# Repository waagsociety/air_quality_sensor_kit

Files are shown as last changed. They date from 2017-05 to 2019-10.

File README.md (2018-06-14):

# Air quality sensor kit
This repo contains documentation, source files and code for the following air quality sensor kits:

- Bora kit
- Bora Lora kit
- rIoT
- Responsive bird

### Bora kit
Air Quality Sensor for the Amsterdam Smart Citizens Lab, measures NO2, dust, temperature and humidity. Developed for a pilot in 2016 to measure air quality around the Valkenburgerstraat and Weesperstraat, under the name [Urban AirQ](http://waag.org/en/project/urban-airq). Citizens actively participated in the measuring process.

### Bora lora kit
The Bora kit was further developed during the [Smart Kids Lab](https://waag.org/en/blog/smart-citizen-kit-measuring-children-school) pilot to improve some criticalities with [LoraWAN](https://www.lora-alliance.org/What-IsLoRa/Technology):
- unstable and weak connectivity of the wifi module
- high power consumption,
- lack of real time data visualization.

### rIot
TBA

##### Credits
Partners: KNMI, University of Wageningen, GGD Amsterdam, ECN and the LongFonds. Waag Society earlier conducted a pilot with the Smart Citizen Kit in Amsterdam to measure air quality.

Partly financed by the Amsterdam Institute for Advanced Metropolitan Solutions (AMS). The project is also part of the European financed program Making Sense. This project has received funding from the European Union’s Horizon 2020 research and innovation programme under grant agreement no. 688620.

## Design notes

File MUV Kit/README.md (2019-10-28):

# Air quality sensor kit for MUV

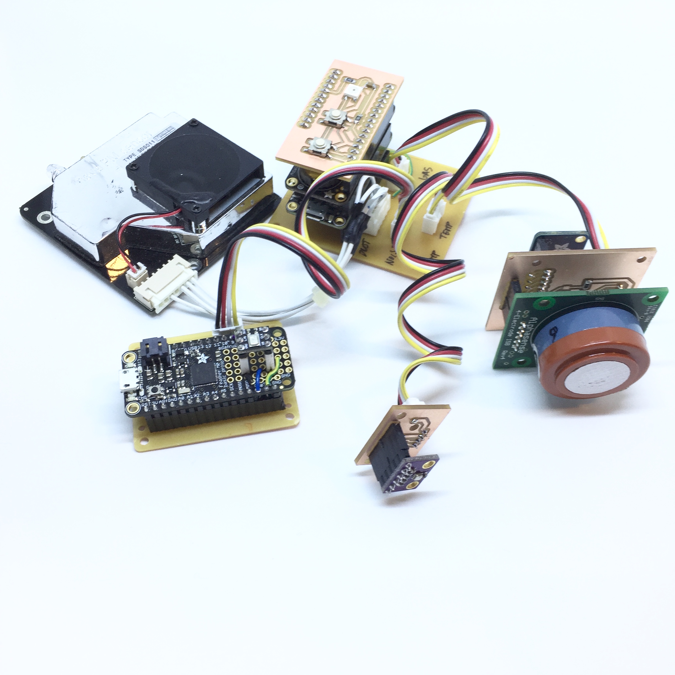
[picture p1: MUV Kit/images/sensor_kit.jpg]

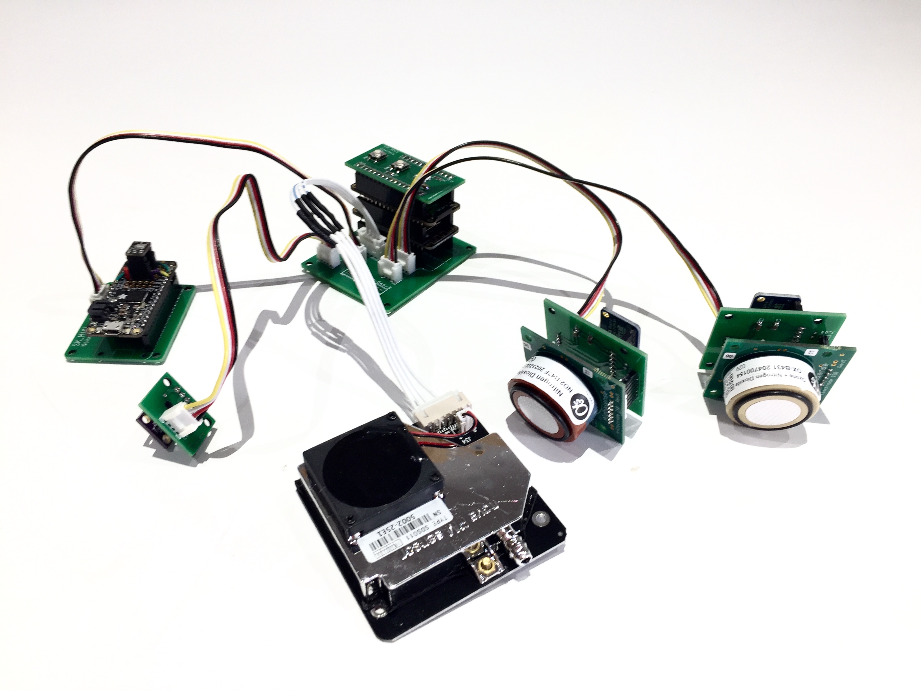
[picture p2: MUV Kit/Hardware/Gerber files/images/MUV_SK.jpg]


This repository is about the Sensors Kit developed for the project [MUV](https://www.muv2020.eu/) and contains the following parts:
- this page: you will find on this page the instructions on how it works.
- [Sensors](https://github.com/waagsociety/air_quality_sensor_kit/tree/master/MUV%20Kit/Sensors) folder: it contains the list of sensors that can be connected to the Kit.
- [Hardware](https://github.com/waagsociety/air_quality_sensor_kit/tree/master/MUV%20Kit/Hardware) folder: it contains digital files, original design files, layout view, instruction on how to produce the pcbs in a fablab, gerber files and BOM.
- [Firmware](https://github.com/waagsociety/air_quality_sensor_kit/tree/master/MUV%20Kit/Firmware) folder: it contains the sketches used in the Kit.
- [Case](https://github.com/waagsociety/air_quality_sensor_kit/tree/master/MUV%20Kit/Case) folder: it contains the instructions for the case.

## Intro
The MUV Sensors kit is a device developed to measure the following environmental quantities:
* dust (PM10 and PM2.5)
* temperature/humidity/pressure sensor
* nitrogen dioxide and ozone.

The kit has a WiFi module that collects the data from the sensors and send them to the MUV MQTT-server. If the WiFi is missing the kit saves the data on an SD-card.

NOTE: when you power on the kit, it must be able to connect to a WiFi otherwise it will not start the measurements.

Once the Kit is powered on and connected to the WiFi it will run automatically.

### Connect the Sensor Kit to the local WiFi
Power on the SK (Sensor Kit), plugging the USB cable. 
The kit will try to connect to the WiFi, during which the Led on the interface board will flash red. 
If no Wifi configuration is present, the kit wil enter configuration mode, indicated by a steady blue Led.

When in configuration mode, it creates a network named MUV_air.
At this point you need a smartphone/tablet or computer, join the network MUV_air.

If the Led keeps flashing red, you can enter configuration mode manually. Press and hold the 
SW_CONFIG button while pressing the SW_RST button. The kit should reset and start in
configuration mode with the blue Led on. Once the blue Led is on, you can release the SW_CONFIG
button.

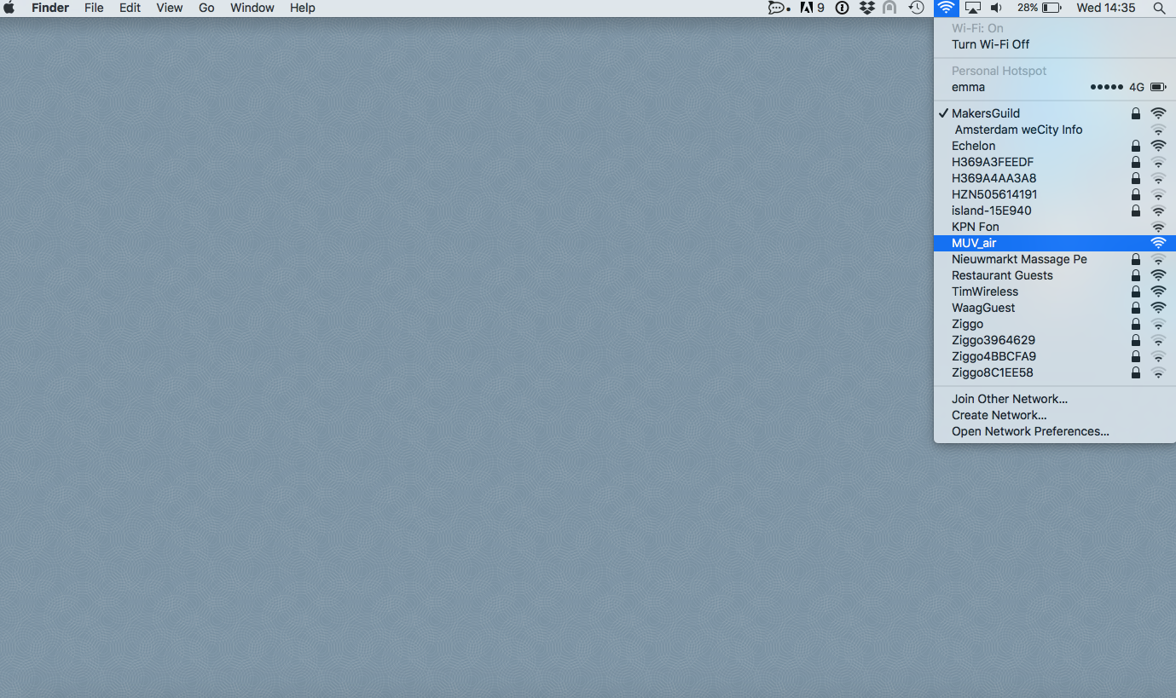
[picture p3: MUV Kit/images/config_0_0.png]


Automatically on the device you are using (smartphone/tablet/computer) the configuration window will pop-up.

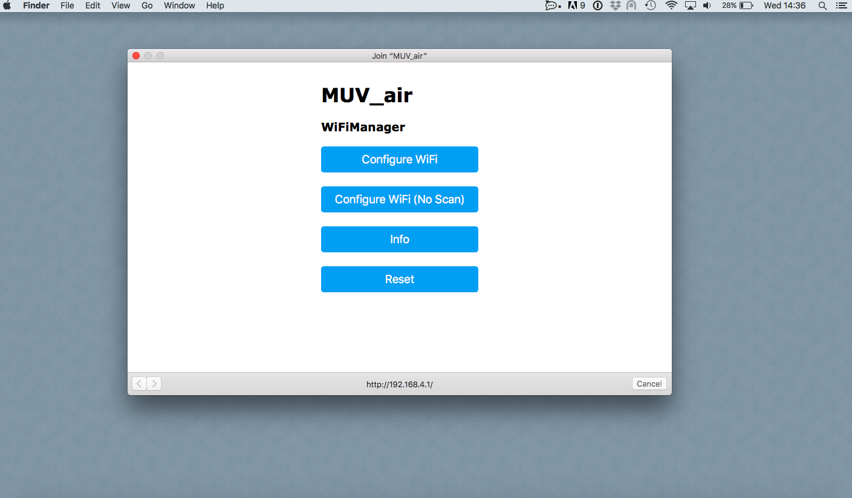
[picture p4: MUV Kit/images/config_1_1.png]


If the window doesn't appear, open a browser and go to the address: http://192.168.4.1/.

Clicking on Info, you can see the information related to the kit and find the kit ID that in the window is called Chip ID.
Clicking on Configure WiFi, you are in the right place to connect the kit to you local WiFi.

Select the WiFi and type the password.
In the tag "Insert address", write the location of the kit.
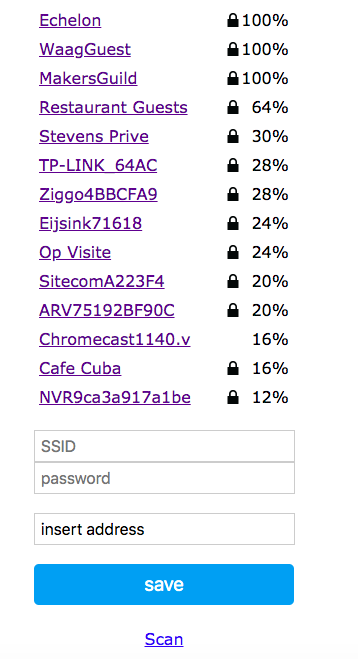
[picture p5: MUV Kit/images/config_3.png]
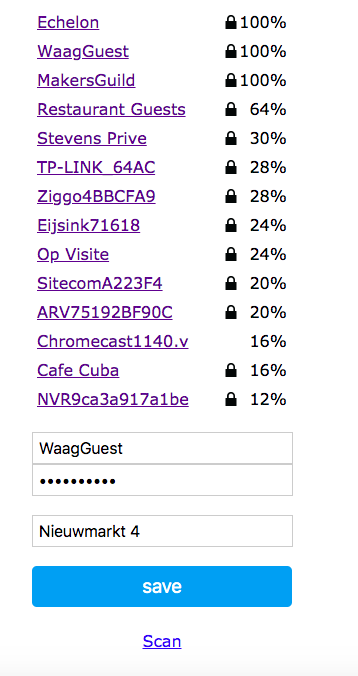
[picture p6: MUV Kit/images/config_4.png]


Click save and the kit will try to connect to the WiFi. The Led should flash red briefly, then turn green for a short time, then flash
magenta briefly and finally going off. The kit is now connected and starts the measurements.

** NOTE **
In case you want to change the location, you can enter configuration mode using the Config switch on the interface board: keep pushed the Config switch and reset the kit (press once the reset switch). Hold the Config switch until the Config Led turns blue.

### Explanation of the Led colors
- When you power the kit on, the Led blinks red while connecting to the WiFi. If it can't connect, it will continue to flash red.
- You can enter configuration mode as described above. When in configuration mode the Led is a steady blue.
- When the WiFi is connected succesfully, the Led is on green, while getting the current time from the NTP server and checking for a firmware update.
- Once the time is synchronised, the kit will attempt to connect to the MQTT server. During this the Led flashes magenta. If it can't connect
to the MQTT server, it will continue to flash magenta.
- Once the MQTT connection is made, the Led will go off and the measurements begin.
- Every time the data are pushed to the cloud, the Led blinks green if the uplink is successful. If the payload can't reach the server, the Led turns on/orange and the data are saved to the SD-card. If the kit is disconnected from the WiFi and can't save the data on the sd-card, the Led stays on/red.

### MUV

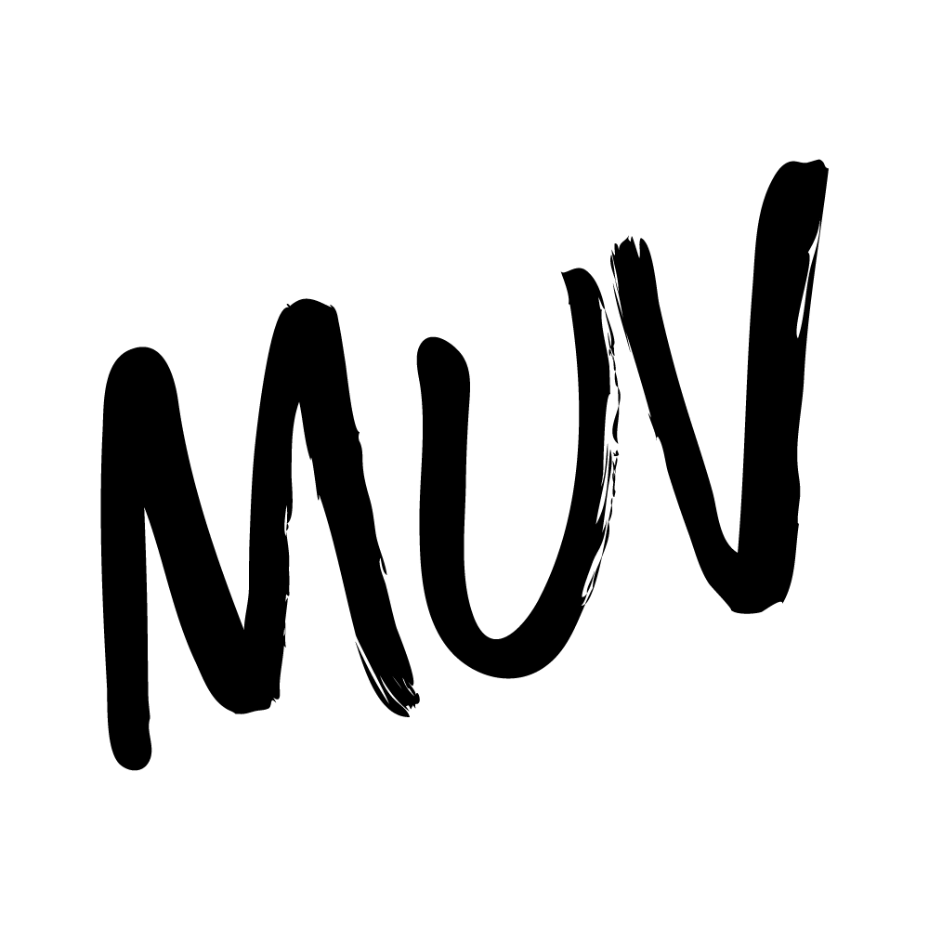
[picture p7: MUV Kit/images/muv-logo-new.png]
 

[*MUV* – Mobility Urban Values –](https://www.muv2020.eu) levers behavioural change in local communities using an innovative approach to improve urban mobility: changing citizens’ habits through a game that mixes digital and physical experiences.

Rather than focus on costly and rapidly ageing urban infrastructures, MUV promotes a shift towards more sustainable and healthy mobility choices by engaging in a positive way local communities, local businesses, policymakers and Open Data enthusiasts.

MUV solutions will be open, co-created with a strong learning community of users and stakeholders, and piloted in a set of diverse urban neighbourhoods spread across Europe: Amsterdam (NL), Barcelona (ES), Fundao (PT), Ghent (BE), Helsinki (FI), Palermo (IT).

Mobility and environmental data gathered via the mobile app and the monitoring stations will allow policymakers to enhance planning processes and civic hackers to build new services able to improve cities’ quality of life in a more effective way.



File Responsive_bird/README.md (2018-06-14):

# NO2_sensor
This bird senses NO2 and according on the percentage NO2 it rotates around its axis. 

The housing of the NO2 sensor has the shape of a bird. A DC motor attached to the sensor enables the object to rotate. This rotation gives minimalistic feedback on the sensor's data. When the quality of the air is good, the bird is in it's normal position. But when the air quality deteriorates, the bird turns half a circle and lies down on its back, as if it’s dead. In this way, by adding a small mechanism to the sensor, passers-by can immediately retrieve feedback from the sensor.

prototype bird with hands
no2 kills birds

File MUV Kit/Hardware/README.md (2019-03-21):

If you are planning to produce the boards in the fablab you are in the right place. On this page you find instructions that will guide you during the process.
If you want to save time (and budget) you can download and use the gerber files of the customised boards from [folder](https://github.com/waagsociety/air_quality_sensor_kit/tree/master/MUV%20Kit/Hardware/Gerber%20files).

## Fab pcbs

The Fab boards are made using the small milling machine Roland Modela MDX-20, each pcbs requires at least two jobs: mill the trace and cut/drill the boards, in the folder digital files you find the png machinable files. When the pcb is double-side (the components and/or traces are on both side), the jobs are four: [double side milling](https://github.com/waagsociety/air_quality_sensor_kit/tree/master/MUV%20Kit/Hardware/Double%20side%20milling).

Tools used:
- one side and double side copper plate, FR1
- to mill the traces: endmill, 1/64inch diameter
- to cut and drill: endmill, 1/32inch diameter

In Fablab Amsterdam the software to generate the rml file and send it to the machine is Fabmodules. It is highly recommended to use the last version of Fabmodules, aka mods http://mods.cba.mit.edu/; previous versions of fabmodules, still work but double check the output of the software before to send the job to the machine, in some cases the path is not well calculated.

In the image below you find the setting to envrage the traces and to drill holes/cut the board.
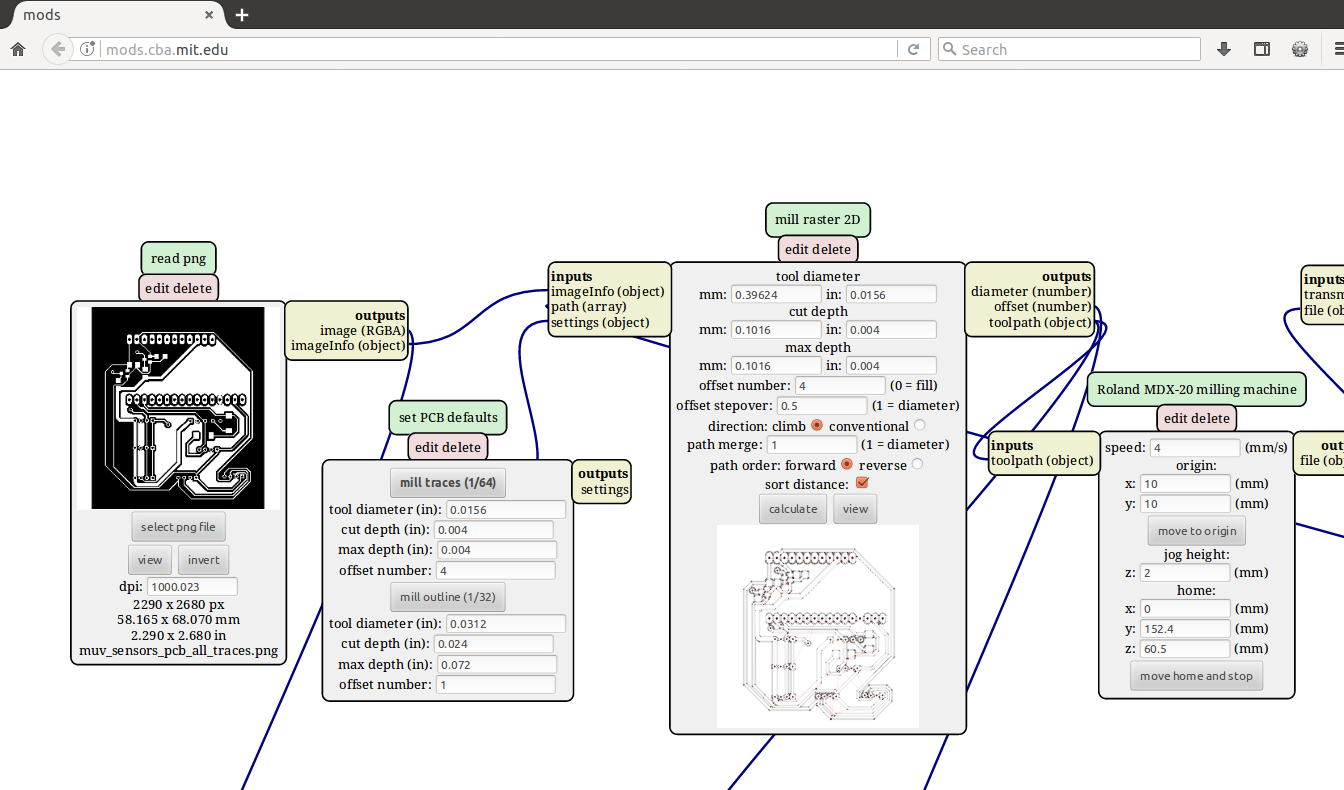
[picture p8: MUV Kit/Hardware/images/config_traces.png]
<br>
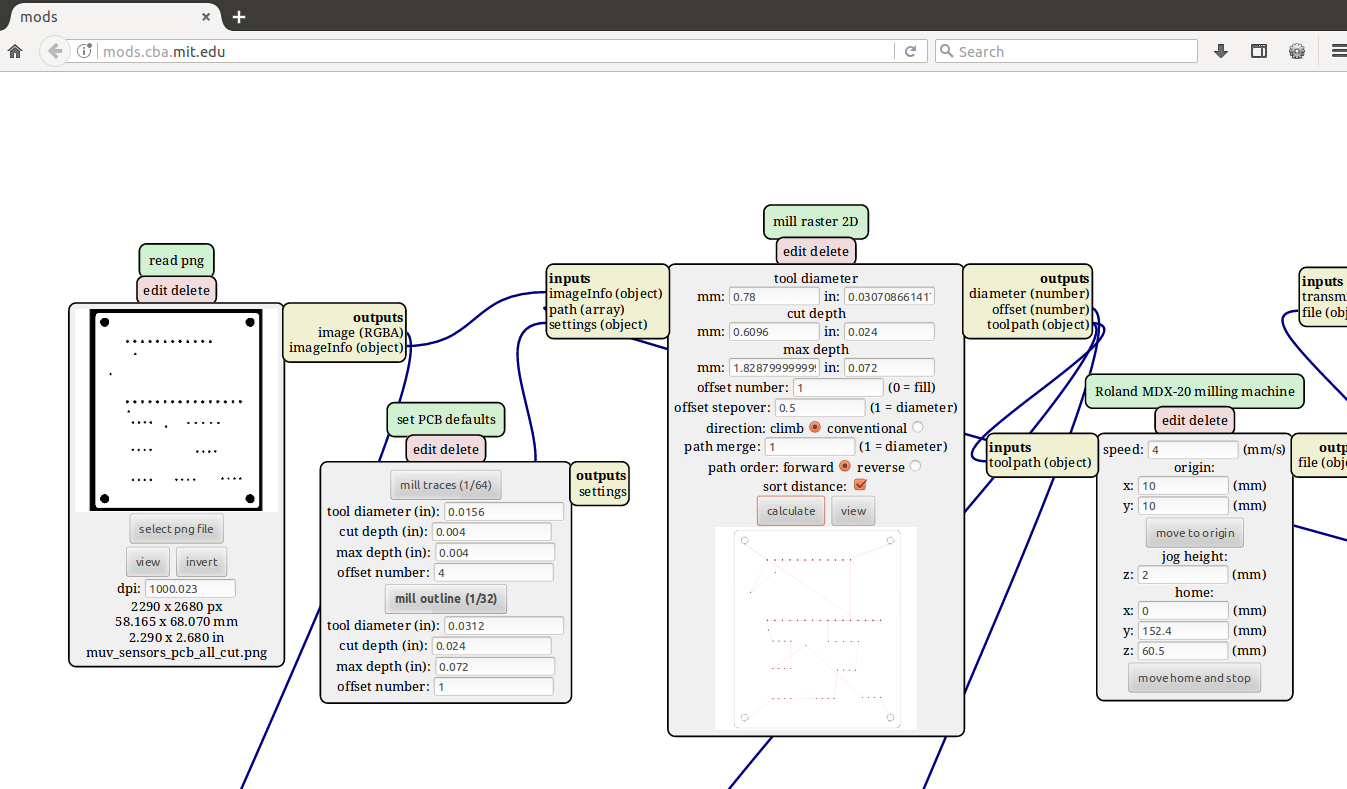
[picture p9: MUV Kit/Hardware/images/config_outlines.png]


Note: when you mill the outlines, you will need to trick the fabmodules!! Some holes are two smalls to be identified with a diameter tool of 1/64inch (0.79248mm) so you can set the diameter tool to 0.78mm and all the holes will be milled; yes, you lose some copper on the pad but it is still enough to solder vias and components.

#### Sensors pcb
| top view  | bottom view |
| --- | --- |
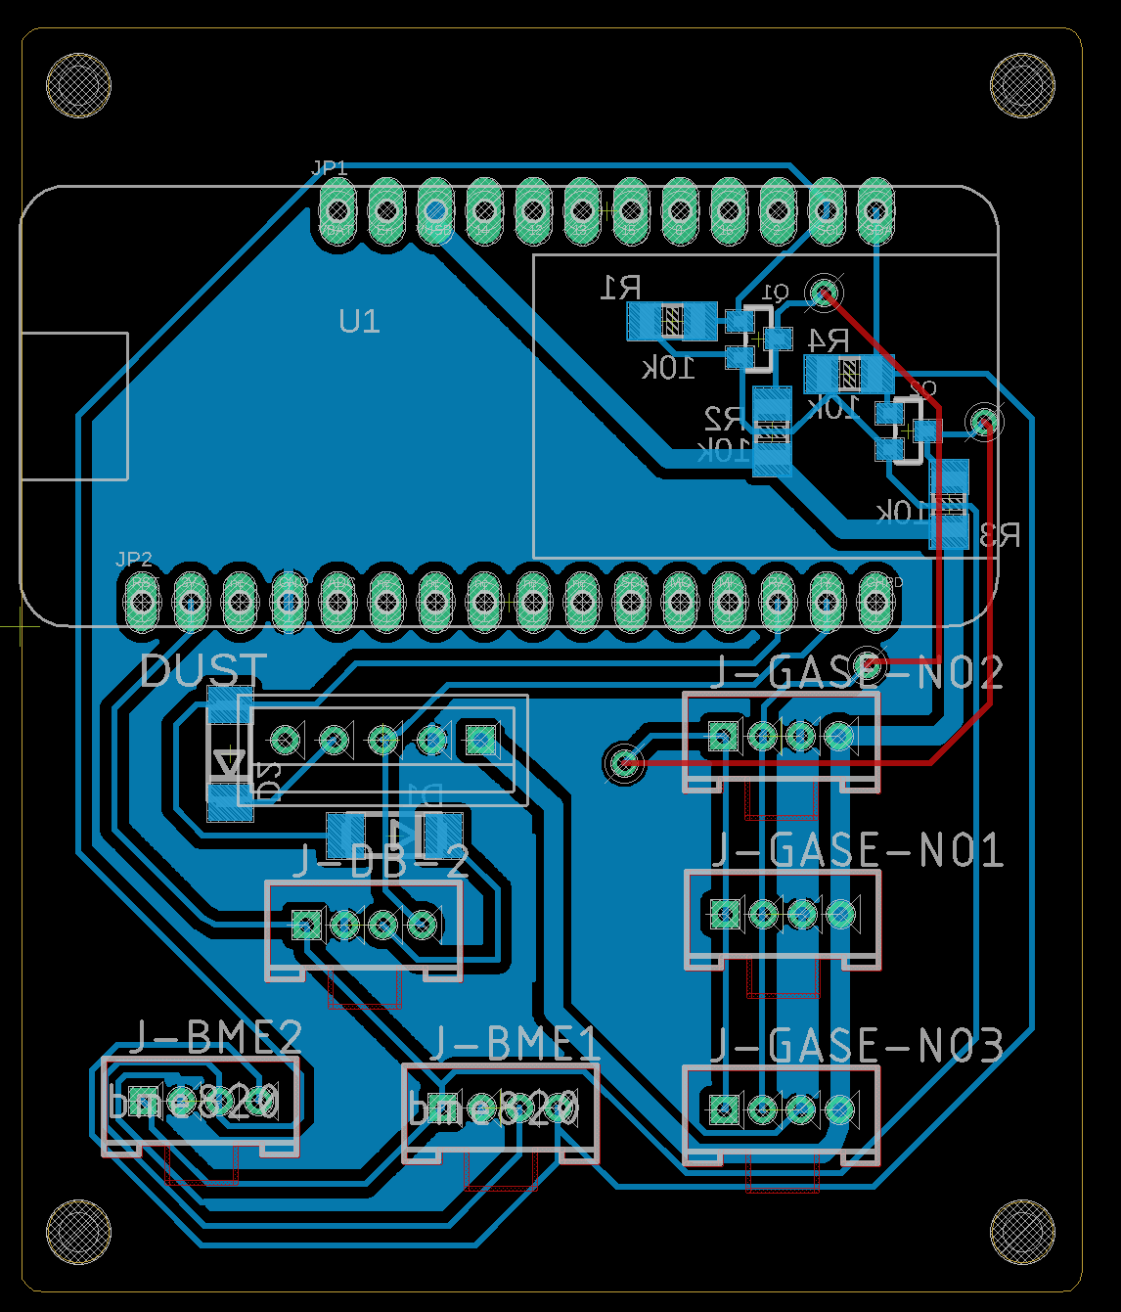
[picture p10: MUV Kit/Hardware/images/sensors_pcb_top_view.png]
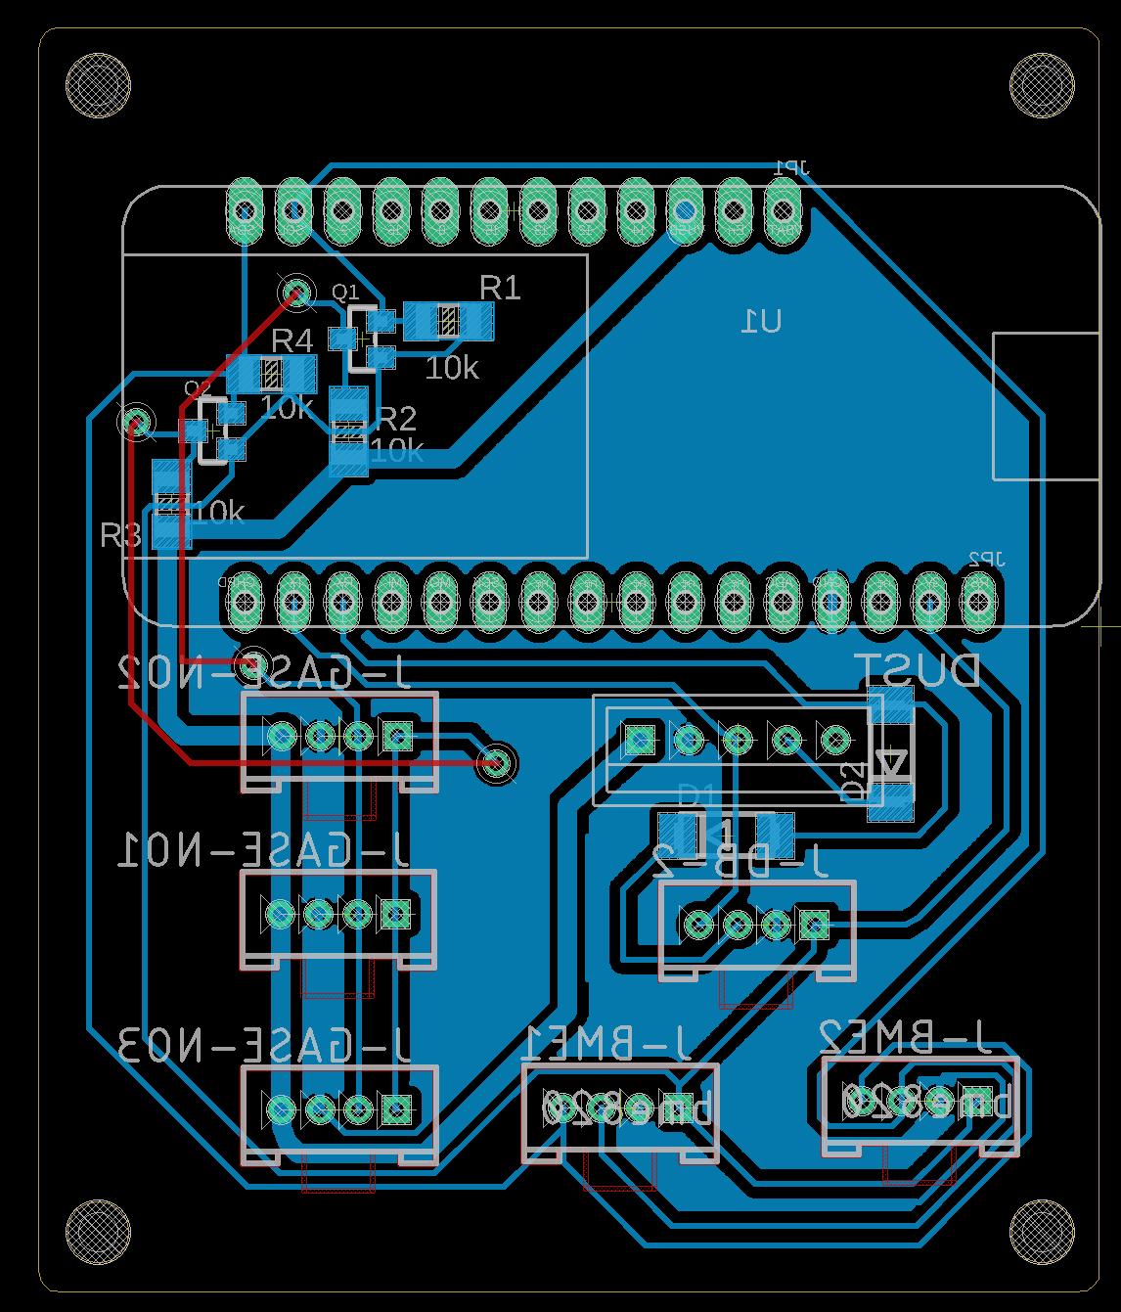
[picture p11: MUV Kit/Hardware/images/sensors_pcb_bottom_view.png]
| |  |
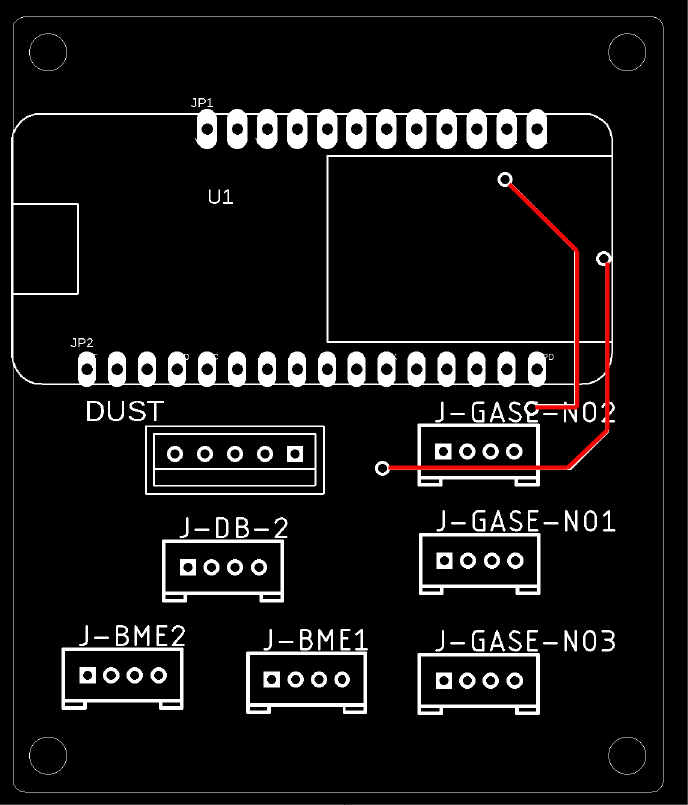
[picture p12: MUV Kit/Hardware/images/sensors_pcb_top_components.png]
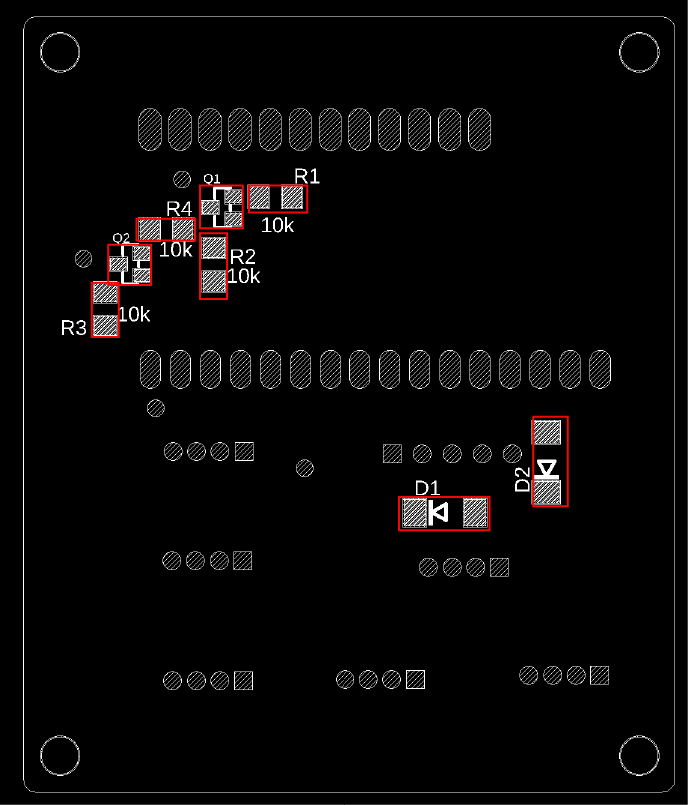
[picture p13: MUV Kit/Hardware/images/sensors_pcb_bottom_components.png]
| Components placed on the top layer  <br> but soldered on the bottom! <br>  <br> JP1: female THT 1x12 pin header, 2.54pitch <br> JP2: female THT 1x16 pin header 2.54pitch <br> J-GAS, J-DB. J-BME : Grove - Universal 4 Pin connector <br> 05-JST-B5B: Connector Wire-To-Board, B5B-XH-A (LF)(SN) <br> red traces: jumper wires between vias| Components placed on the bottom layer <br> and soldered on the bottom side <br>  <br> Q1/Q2 : BSS138 mosfet, also the NDS355AN from the fab inventory is ok. <br> R1/R2/R3/R4 : 10 Kohm <br> D1/D2 : diodes <br><br><br><br>|
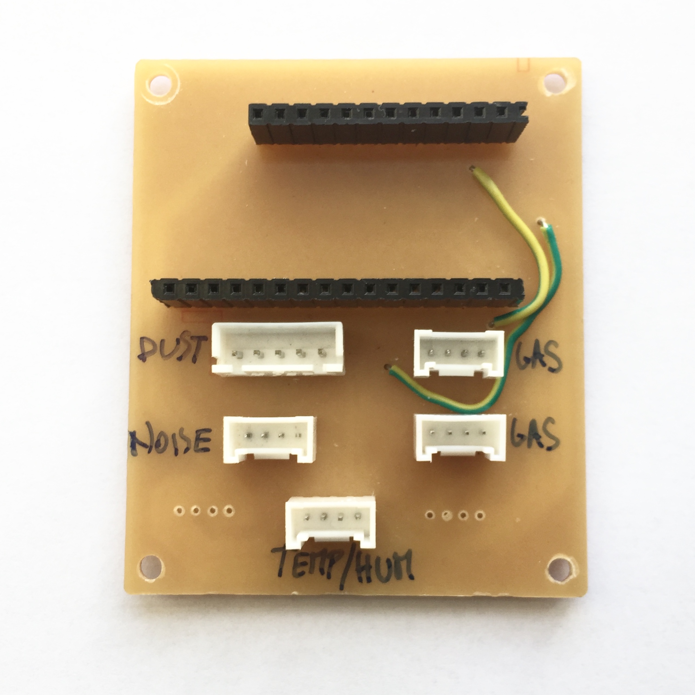
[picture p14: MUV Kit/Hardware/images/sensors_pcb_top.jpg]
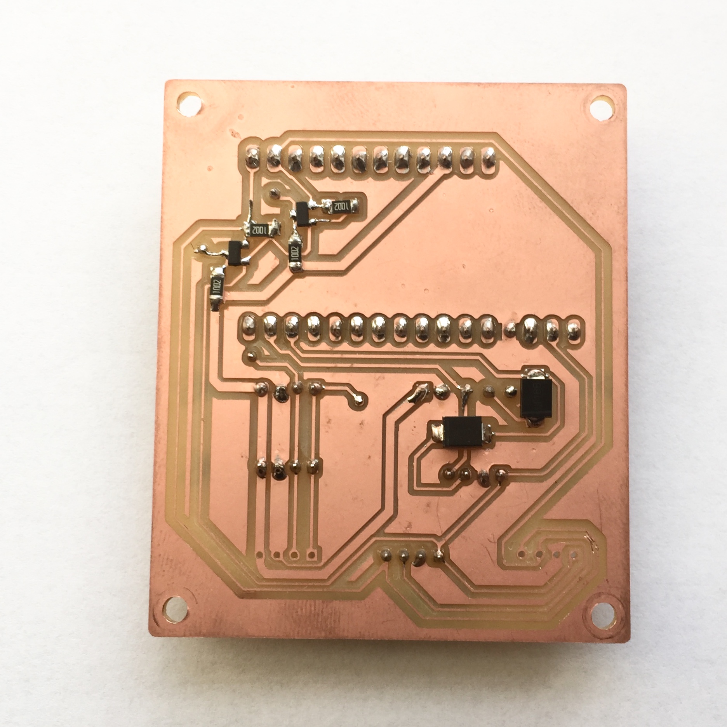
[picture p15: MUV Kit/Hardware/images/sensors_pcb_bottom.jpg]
|   | |

On the sensors pcb, it is not necessary to use all the connectors.
Depending on the sensors you want you use you can solder the required sockets. The J-GAS-NO1 and J-GAS-NO2 are dedicated to the Alphasense gas input devices. In this repo we are using only one sensor, the NO2 detector and it is connected to J-GAS-NO1.

#### Interface pcb
| top view  | bottom view |
| --- | --- |
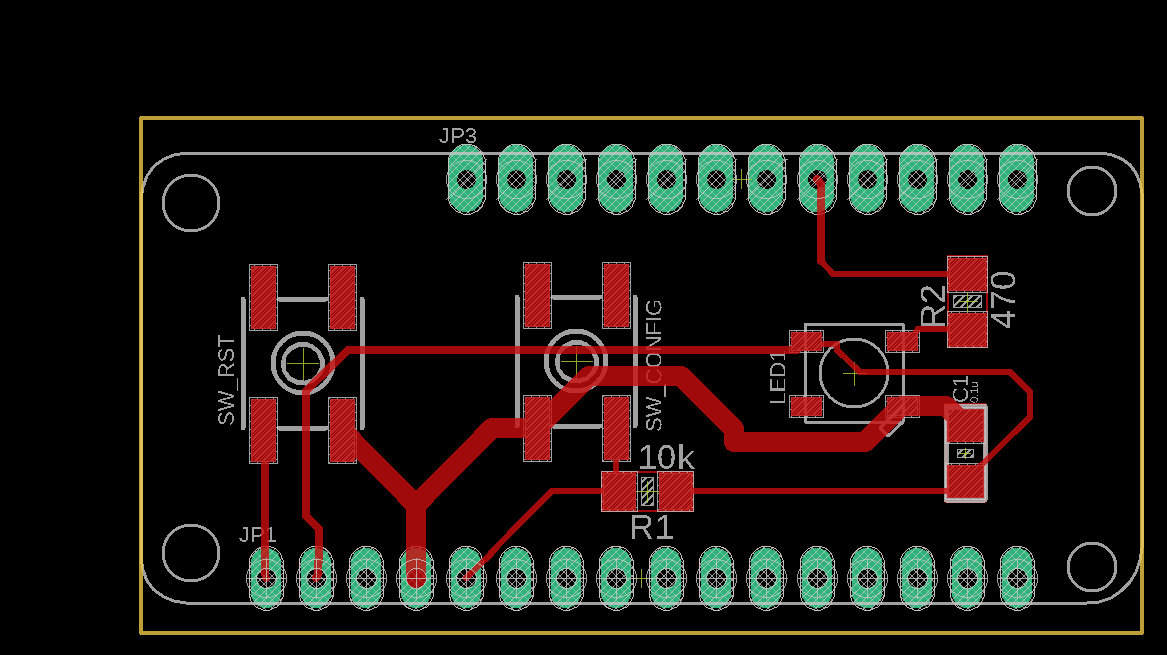
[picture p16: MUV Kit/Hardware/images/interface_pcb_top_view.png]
|  | |
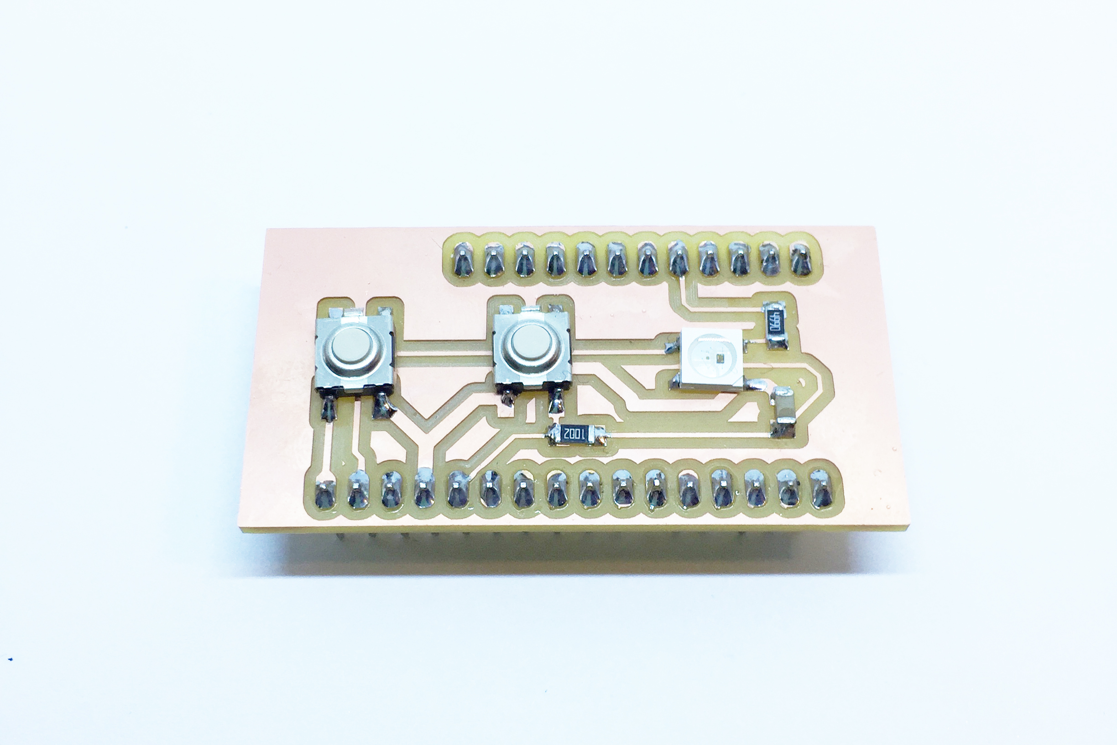
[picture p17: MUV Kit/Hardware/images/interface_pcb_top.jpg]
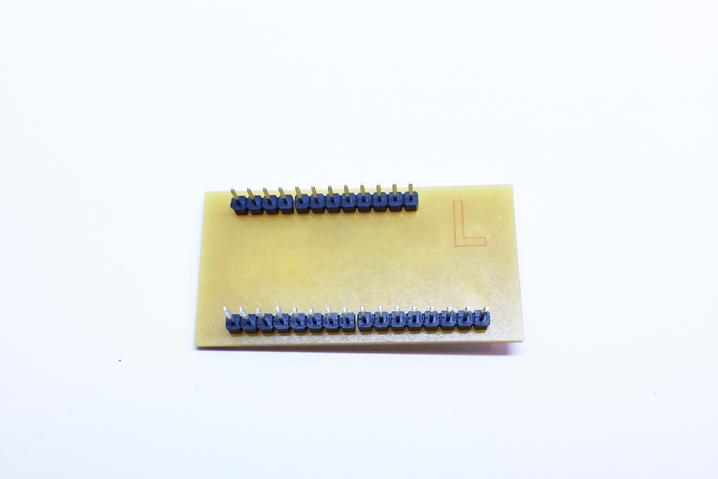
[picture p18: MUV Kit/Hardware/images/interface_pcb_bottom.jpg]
|Components placed on the top layer <br>   <br> SW_RST, SW_CONFIG: push button, smd, 6mm <br> LED1: WS2812B smd <br> R1: 10K res, smd, 1206 <br> R2: 470 ohm res, smd, 1206 <br> C1: 0.1uF cap, smd, 1206| Components placed on the bottom layer <br>  <br> JP3: female THT 1x12 pin header, 2.54pitch <br> JP1: female THT 1x16 pin header 2.54pitch <br><br><br><br>|

#### Temp/Hum pcb
| top view  | bottom view |
| --- | --- |
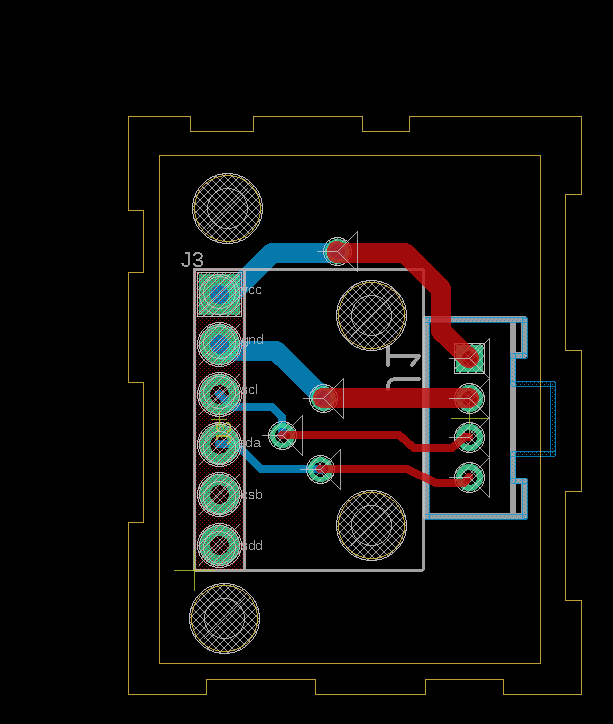
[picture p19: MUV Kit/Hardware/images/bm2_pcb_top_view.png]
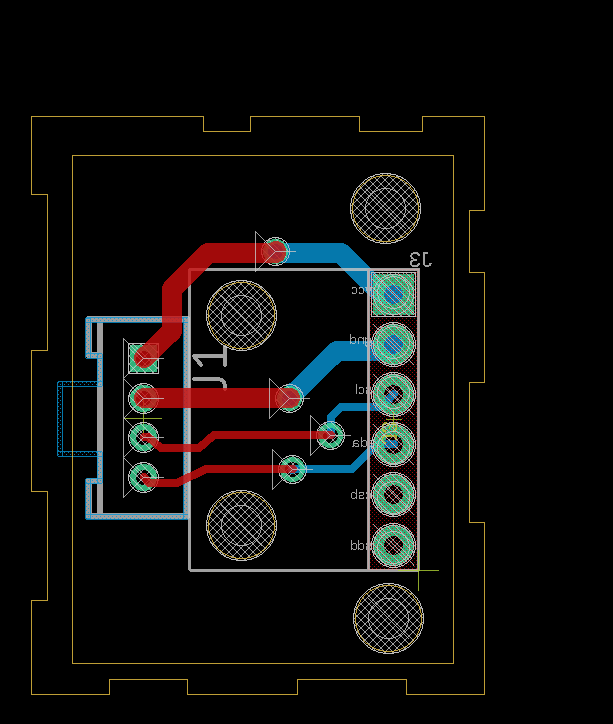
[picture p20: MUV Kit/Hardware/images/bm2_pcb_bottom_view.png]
|   | |
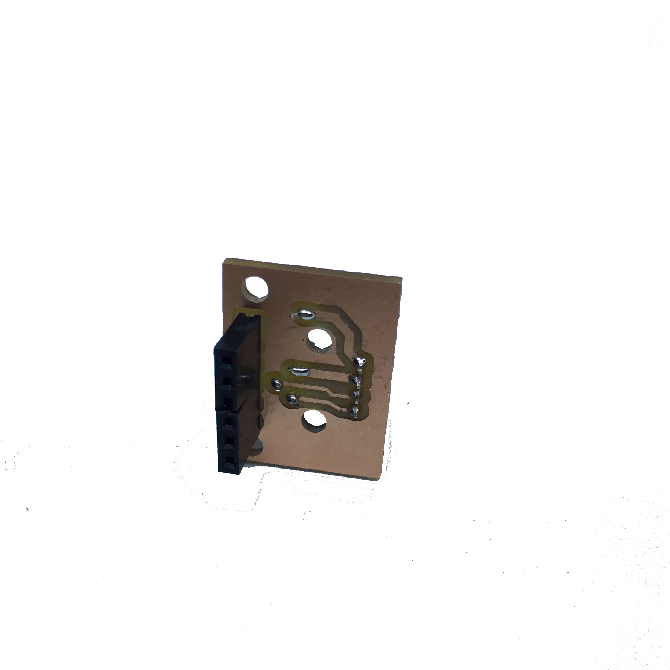
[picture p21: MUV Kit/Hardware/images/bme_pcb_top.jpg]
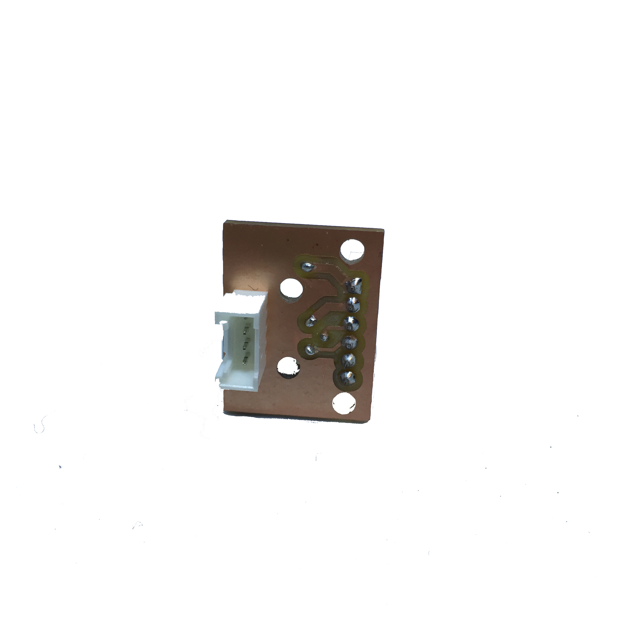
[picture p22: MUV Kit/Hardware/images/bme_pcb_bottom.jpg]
| Components placed on the top layer <br>   <br> J3: female THT 1x6 pin header, 2.54pitch| Components placed on the bottom layer <br>  <br> J1: Grove - Universal 4 Pin connector|

The temp/hum pcb is a 2 layers board, the vias can be filled in with solid core wire (diameter < 0.8 mm). More information about the production of a double side pcb are in the [Double side milling](https://github.com/waagsociety/air_quality_sensor_kit/tree/master/MUV%20Kit/Hardware/Double%20side%20milling) section.

#### Gas pcb
| top view  | bottom view |
| --- | --- |
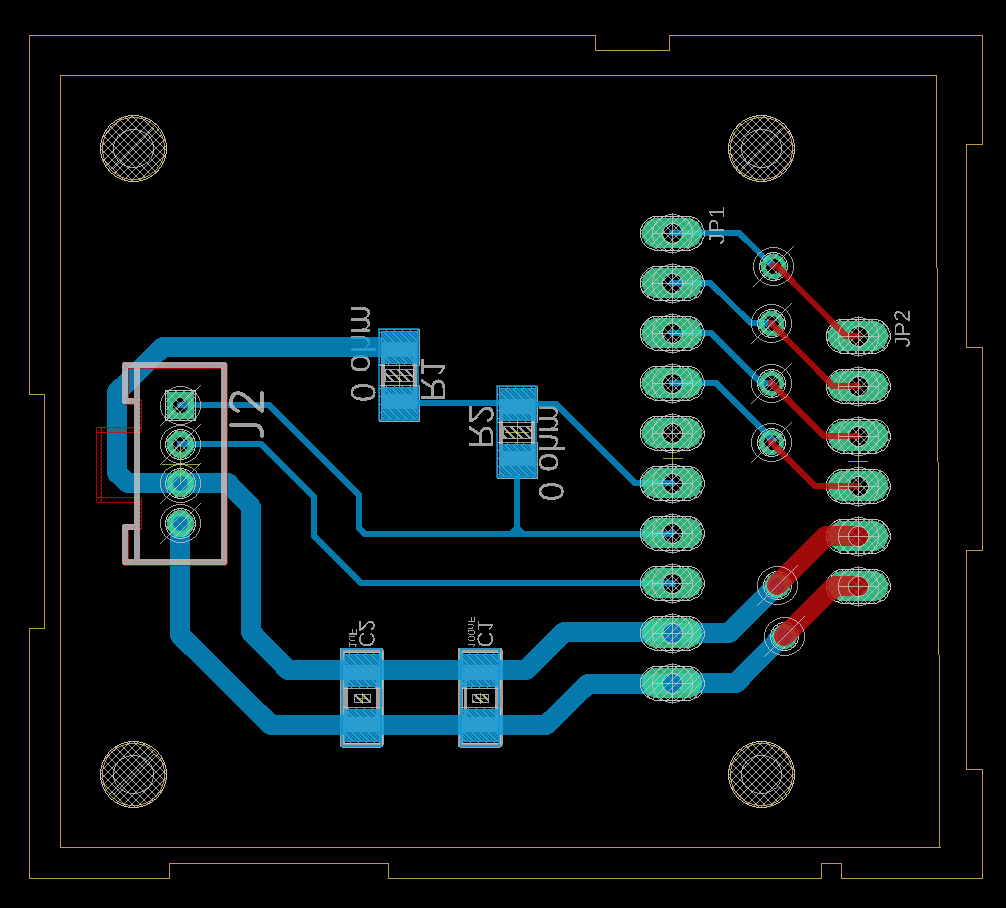
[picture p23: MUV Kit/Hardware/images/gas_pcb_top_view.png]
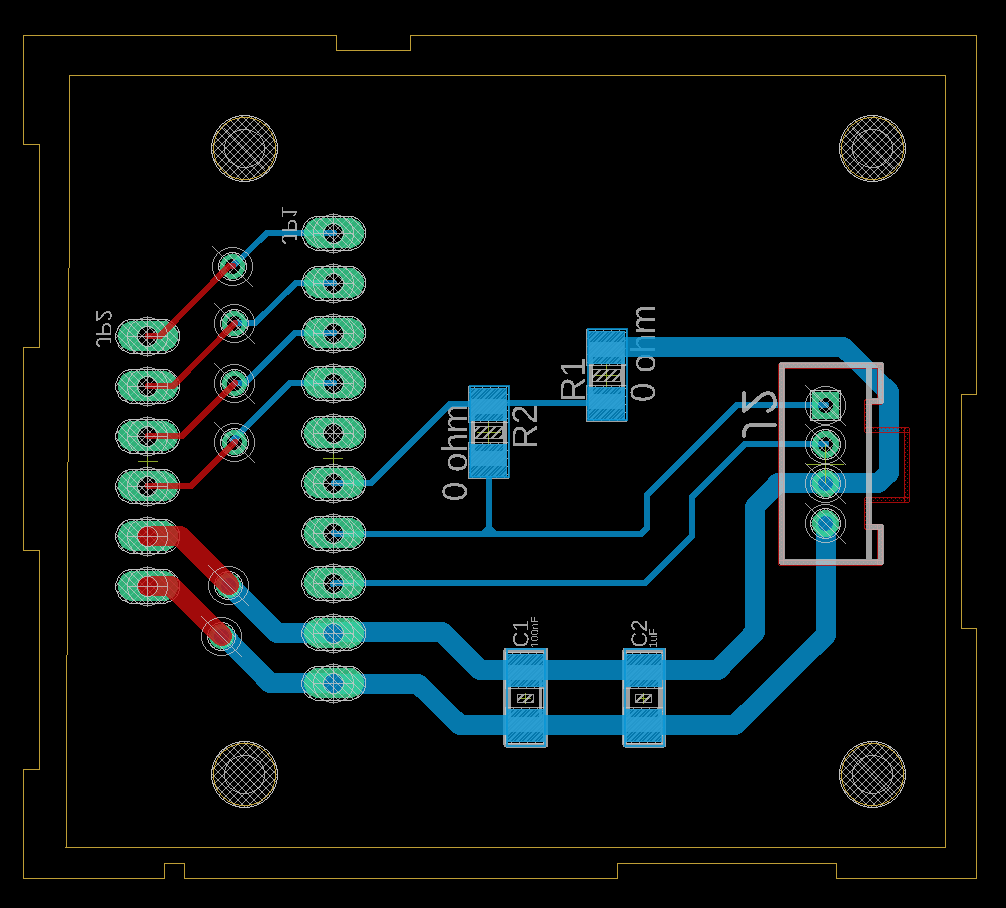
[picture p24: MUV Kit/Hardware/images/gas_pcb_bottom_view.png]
|   | |
| Components placed on the top layer <br>   <br> J2: Grove - Universal 4 Pin connector <br> JP1: female THT 1x10 pin header, 2.54pitch <br><br>| Components placed on the bottom layer <br>  <br> R1 or R2: 0 ohm resistor, smd, 1206 <br> C1: 100nF capacitor, smd, 1206 <br> C2: 1uF capacitor, smd, 1206 |

Note: this board can be used for both NO2 and O3 sensor but it is necessary to solder the zero ohm resistor in the different places depending on the gas. For the NO2 sensor the zero ohm resistor must be placed on R1, for the O3 sensor the zero ohm resistor must be placed on R2.

#### Noise pcb
| top view  | bottom view |
| --- | --- |
|   | |
| Components placed on the top layer <br>  <br> J1: Grove - Universal 4 Pin connector <br> OTS1_short: female THT 1x12 pin header, 2.54pitch <br> OTS1_long: female THT 1x16 pin header, 2.54pitch | There are no components placed on the bottom layer <br>  <br><br><br><br>|

## Off-the-shelf pcbs

#### Adafruit Feather esp8266
The [Adafruit Feather HUZZAH ESP8266](https://learn.adafruit.com/adafruit-feather-huzzah-esp8266?view=all) is an 'all-in-one' ESP8226 WiFi development board. The module can be supplied through USB cable with the following specifications:
* Measures 2.0" x 0.9" x 0.28" (51mm x 23mm x 8mm) without headers soldered in
* Light as a (large?) feather - 6 grams
* ESP8266 @ 80MHz or 160 Mhz with 3.3V logic/power
* 4MB of FLASH (32 Mbit)
* 3.3V regulator with 500mA peak current output
* CP2104 USB-Serial converter onboard with 921600 max baudrate for uploading
* Auto-reset support for getting into bootload mode before firmware upload
* 9 GPIO pins - can also be used as I2C and SPI
* 1 x analog inputs 1.0V max
* Pin #0 red LED for general purpose blinking. Pin #2 blue LED for bootloading debug & general purpose blinking
* Power/enable pin
* 4 mounting holes
* Reset button<br>

In this application the feather esp8266 is responsible to collect the measurements of the sensors and send them, via WiFi, to the dedicated server.
When the Wifi network is not available it can save the data on a SD-card, embedded on a different pcb, see section below.

The feather esp8266 requires female stacking headers so it can be plugged on the sensors pcb and it can host, on top, the RTC/SD-card pcb. The headers must be bought separately and they must be solder on the feather esp8266 board.



#### Adafruit Feather RTC and SD-card
The [Adalogger FeatherWing - RTC + SD](https://learn.adafruit.com/adafruit-adalogger-featherwing/overview) is compatible with the feather esp8266 and it features:
* an I2C real time clock (PCF8523) with 32KHz crystal and battery backup.
* microSD socket that connects to the SPI port pins. A CR1220 coin cell is required to use the RTC battery-backup capabilities.

As for the feather esp8266, it needs the female stacking headers that don't come with the board but they must be separately bought and soldered.

 

#### BME280 breakout board
The [bme280](https://www.bosch-sensortec.com/bst/products/all_products/bme280) sensor is so small (2.5x2.5 mm) that it is easier to work with its breakout board. The sensor works at 3.3V and it can communicate directly with the feather esp8266 that is also run at 3.3V, it means no need of level shifters between the two. Depending on where you buy the device, the board could already have the pin header, otherwise it is necessary to solder a 1x6 male header, 2.54mm pitch.



#### ADS1115 breakout board
The [ADS1115 board](https://learn.adafruit.com/adafruit-4-channel-adc-breakouts/) from Adafruit is the breakout board of the high-resolution Analog-to-Digital converter ADS1115. It is used in the reading of small voltages from the Gas sensors. The board can run from 2ßV up to 5V, in the kit it is supplied at 5V, same domain of the gas sensor, and it executes a two differential input readings.<br>
The [ADS1115](http://www.ti.com/lit/ds/symlink/ads1115.pdf) features:
* Resolution: 16 Bits
* Programmable Sample Rate: 8 to 860 Samples/Second
* Power Supply/Logic Levels: 2.0V to 5.5V
* Low Current Consumption: Continuous Mode: Only 150µA * Single-Shot Mode: Auto Shut-Down
* Internal Low-Drift Voltage Reference
* Internal Oscillator
* Internal PGA: up to x16
* I2C Interface: 4-Pin-Selectable Addresses
* Four Single-Ended or 2 Differential Inputs
* Programmable Comparator  

In the sensor kit, the ADS1115 board needs a 1x10 male pin header, pitch 2.54mm.



#### Adafruit Feather M0 Basic Proto
The Feather M0 Basic Proto has the ATSAMD21G18 ARM Cortex M0 processor as core, it clocked at 48MHz with 3,3V logic. Some specs:

* Measures 2.0" x 0.9" x 0.28" (51mm x 23mm x 8mm) without headers soldered in
* Light as a (large?) feather - 4.6 grams
* ATSAMD21G18 @ 48MHz with 3.3V logic/power
* 256KB of FLASH + 32KB of RAM
* 32.768 Khz crystal for clock generation & RTC
* 3.3V regulator with 500mA peak current output
* USB native support, comes with USB bootloader and * serial port debugging
* 20 GPIO pins
* Hardware Serial, hardware I2C, hardware SPI support
PWM outputs on all pins
* 6 x 12-bit analog inputs
* 1 x 10-bit analog output (DAC)
* Built in 100mA lipoly charger with charging status indicator LED, not in used in sensor kit.
* Pin #13 red LED for general purpose blinking
* Power/enable pin
* 4 mounting holes
* Reset button

In the kit the feather M0 is responsible to communicate with mic for the noise measurements and it sends the data to the feather esp8266 over serial.
The connect the fetaher M0 to pheripheral devices is necessary to solder:
* two 1x3 female pin headers on the proto part of the feather, as socket for the mic. See image below for connection.
* the pin headers: one 1x12 male pin and one 1x16 male pin header, both 2.54mm pitch.

As it is shown in the images below, the socket for the mic is connected to three GPIO pins of the feather M0.
It is handy to NOT solder the long on these three GPIO pads and keep the pads available for the wires of the mic.

<p align="center">  <br>
 </p>

#### ICS-43432 breakout board
The ICS-43432 is the mic used to measure noise, [see](https://github.com/waagsociety/air_quality_sensor_kit/tree/master/MUV%20Kit#Noise%sensor).

Due to the small dimensions, it is handy to work with the breakout board released by [Arduino](https://store.arduino.cc/ics43432-i2s-digital-microphone). The pcb need two 1x3 male pin headers.
The biggest advantage of this module is the I2S audio as a stream of 24-bit serial words that can be directly read by your mcu board with an I2S port. No CODEC is required to decode the audio data!



**Update**<br>
The breakout board of the ICS-43432 from Arduino is no longer available.
The mic can be replaced by the [Adafruit I2S MEMS Microphone Breakout](https://learn.adafruit.com/adafruit-i2s-mems-microphone-breakout?view=all). The board has the [sph0645](https://cdn-shop.adafruit.com/product-files/3421/i2S+Datasheet.PDF): <br>
- High SNR of 65dB(A)
- Low Current of typ. 600µA
- I2S Output: Direct attach to µP
- Multi modes: standard >1MHz,
- 600uA / sleep <900kHz, 10uA
- Flat Frequency Response
- RF Shielded
- Supports Dual Microphones
- Ultra-Stable Performance
- Standard SMD Reflow
- Omnidirectional
- Zero-Height Mic™



As with the original module, the Adafruit device uses I2S protocol and the code is compatible with this device. It's important to note that the pins on this module have a different configuration, so be sure about the [connections](https://learn.adafruit.com/adafruit-i2s-mems-microphone-breakout?view=all#arduino-wiring-and-test). Another important difference between the two breakout boards is the location of the microphone hole. In the Adafruit device, the hole is placed on bottom side of the breakout board!!

#### SDS011 Cable
Due to the wrong orientation of the connector on the sensors pcb, it is necessary to adjust the cable that comes with sensor so the connectors are well aligned:<br>
1- cut the cable<br>
2- rotate one of the extremities of 180 degrees<br>
3- solder back the wires using shrink tubes on each wire<br>

  
 

## Modules and assembly
#### Central module
|  |  |
| --- | --- |
| | |

#### Temp/Hum module
|  | |
| --- | --- |

#### Gas module
|  |  |
| --- | --- |
|   |  |

#### Noise module
|  | |
| --- | --- |

#### Final Assembly
The SDS011 sensor connects to the sensors pcb with its cable. All the other modules use Grove - Universal 4 Pin Unbuckled 20cm Cable.


## Power Supply
The kit is supplied by the micro USB port of the Adafruit Feather esp8266. The ISB adapter must be able to supply at least 1A.

## BOM notes
Many items in the BOM can be bought only in minimum amount, when you actually are going to use one or two component. The total cost is therefore expressed as:
* total purchase: the cost of the purchase, buying the minimum amount per items
* cost of 1 kit: considering the cost of only the component used in the kit.

for example: if you buy the "feather header 1" from Farnell, you have to buy 10 components even if you are going to use only one. In the purchase cost the item "feather header 1" is 12€ but in the single cost of one kit, the item value is 1,2€.

The kit showed in this repo doesn't have the O3 sensor, but the you can find indication about the boards and how to connect it to the kit.

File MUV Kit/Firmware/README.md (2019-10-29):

## MUV Firmware

There are two different firmwares in this directory and they are written in Arduino IDE, version 1.8.5.
1. code to set the measurement period of the sds sensor kit
2. code for Feather HUZZAH ESP8266 board

Because the compilation of the code takes a long time in the Arduino IDE, the latest code for the ESP8266 was developed in Visual Studio Code (v1.39.2) using Platform.io (v4.0.3). The code should compile in the Arduino IDE, but it is much easier to just flash the prepared binary file to the board using the esptool explained below.

### Code for setting the SDS011
The data collection is based on the working period of the SDS011. It is necessary to configure the 
SDS011 to collect and send data every 3 minutes. Connect an Arduino UNO to the sensor, 
the connections are the following: 

* Arduino pin 2 -> SDS pin TX
* Arduino pin 3 -> SDS pin RX
* Arduino pin 5V -> SDS pin 5V
* Arduino pin GND -> SDS pin GND

Upload the code 'MUV_sds011_set_working_period.ino' to Arduino UNO with the sensor connected and the Arduino will take care to configure the SDS011.
The sketch includes the following library:
* SdsDustSensor.h: https://github.com/lewapek/sds-dust-sensors-arduino-library

### Code for Feather HUZZAH ESP8266 board
The sketches for Feather HUZZAH ESP8266 are the following:
* 'MUV_ESP8266_format.ino': described in First upload section
* 'MUV_ESP8266_main_OTA.ino': described in Second upload section

To upload them to your kit, you need the SiLabs CP2104 Driver and the ESP8266 Board Package in Arduino IDE: [tutorial](https://learn.adafruit.com/adafruit-feather-huzzah-esp8266/using-arduino-ide).

#### First upload
This is a recommendation, the First Upload is not mandatory but it formats the System files in the esp8266 and reset previously saved WiFi settings. You just need to upload the code 'MUV_ESP8266_format.ino'. Once you upload the code, open the Serial Monitor and when it displays: "loop...", you can proceed with the next step.

The 'MUV_ESP8266_format.ino' includes the library:
* FS.h: part of the esp8266 core https://github.com/esp8266/Arduino
* WiFiManager library: https://github.com/tzapu/WiFiManager

#### Second and further uploads
The sketch 'MUV_ESP8266_main_OTA.ino' is responsible to read the sensors data and send them to the cloud; it includes the following libraries:

* esp8266 core: https://github.com/esp8266/Arduino
* FS library: part of the esp8266 core
* DNSServer library: part of the esp8266 core
* ESP8266WebServer library: part of the esp8266 core
* WiFiManager library: https://github.com/tzapu/WiFiManager --- Version 0.14.0
* ArduinoJson library: https://github.com/bblanchon/ArduinoJson (Version 6!)
* PubSubClient library: https://github.com/knolleary/pubsubclient
* SD library: https://github.com/arduino-libraries/SD
* SoftwareSerial library: part of Arduino core
* Wire library: part of Arduino core
* RTClib library: https://github.com/adafruit/RTClib
* ezTime library: https://github.com/ropg/ezTime
* Adafruit_Sensor library: https://github.com/adafruit/Adafruit_Sensor
* Adafruit_BME280 library: https://github.com/adafruit/Adafruit_BME280_Library
* Adafruit_ADS1X15 library: https://github.com/adafruit/Adafruit_ADS1X15
* Adafruit_NeoPixel library: https://github.com/adafruit/Adafruit_NeoPixel

Change the maximum payload size in the library file "PubSubClient.h":
```
#define MQTT_MAX_PACKET_SIZE 256
```

When you upload the code to this board the following requirements are necessary:
- insert the battery in the battery holder of the board 'Adalogger FeatherWing RTC + SD'
- insert the SD-card in the SD-card holder of the board 'Adalogger FeatherWing RTC + SD'. The card must be formatted as FAT16 or FAT32, [link](https://learn.adafruit.com/adafruit-adalogger-featherwing/using-the-sd-card).
- plug, on top of the esp board, the 'Adalogger FeatherWing RTC + SD' and the 'interface board'
- don't connect any other boards to it.

#### config.json file on the SD-card

In previous versions, several configuration values such as the MQTT credentials were hardcoded in the source code. Because of the new Over The Air firmware updates, these configuration values were moved to a separate configuration file, located on the SD-card.

The SD-card must contain file in the root directory named "config.json". This file contains the login credentials for the MQTT server, the credentials for the firmware server and the configuration of which sensors are on board this Monitoring Station. It is essential that this file is configured and formatted correctly, otherwise the firmware will not work.

The format of this file is as follows:
```
{ "mqtt_server":"mqtt host",
  "mqtt_port":"mqtt port",
  "mqtt_username":"mqtt usename",
  "mqtt_password":"mqtt password",
  "mqtt_topic":"sensor/%u/data",
  "address":"sensor street address",
  "firmware_server":"firmware host",
  "firmware_port":"firmware port",
  "firmware_path":"/ota",
  "sensor_no2":"True",
  "sensor_o3":"False",
  "sensor_bme":"True"  }
```

Depending on which sensors are on board your Monitoring Station, set the values for `sensor_no2`, `sensor_o3` and `sensor_bme` to `True` or `False`.<br>
If the sensor is not used, the variable must be set to `False`. <br>
If the sensor is used, the variable must be set to `True`.<br>

Be sure that the information to access the MUV server and the firmware update server are correct.
  
To get the MUV credentials and MUV password, please contact [insert contact information]
  
Now you can flash the firmware.

#### Flashing the firmware

Since the new firmware has the capability to be updated from a remote server, prebuilt binaries of the firmware are available.
You do not have to compile the code yourself. The easiest way to flash the prebuilt firmware binary to the ESP8266 is to use 
the esptool that is bundled with the Arduino ESP8266 Core. 

Open a terminal window and go to the directory where the Arduino esptool is installed. On my Windows this is located in
C:\Users\Windows\AppData\Local\Arduino15\packages\esp8266\hardware\esp8266\2.5.2\tools\esptool\

You can also install the esptool separately using pip, if you have python installed:

`$ pip install esptool`

See the esptool [github]https://github.com/espressif/esptool page for more information.

Next copy the latest firmware image (located in the builds directory) to this directory. 
After that you can flash the firmware using this command:

`$ python esptool.py write_flash 0x0000 firmware_2.0-4.bin`

Because the SDS dust sensor shares the serial connection that is also used for the firmware upload, It is possible for a firmware upload to fail because of interference from the sensor. If this happens, just retry the upload and it should succeed, or disconnect the dust sensor.

Once the code is uploaded, unplug the USB cable and assemble the kit; the kit is ready to run. On the [this page](https://github.com/waagsociety/air_quality_sensor_kit/tree/master/MUV%20Kit) you find the instructions to connect the kit to the local WiFi.

#### Uplinks
The Sensor kit can send two messages, at the start-up and when the data are ready.

- Start-up message:
```
{"message":"startup","id":1340471,"ts":"2019-10-25T15:35:50","location":"Groningen","rssi":-69}
```
message: startup <br>
id: chipID, unique identifier of the esp <br>
ts: timestamp in ISO 8601 format: YEAR-MONTH-DAY T HOUR:MINUTE:SECOND <br>
location: location of the kit, to be inserted during configuration mode <br>
rssi: rssi <br>

- Data message:
```
{"id":1340471,"ts":"2019-10-25T15:40:05","t":23.27,"h":35.4,"p":1001.02,"p25":9.7,"p10":13.8,"no2op1":1057,"no2op2":1100,"o3op1":1567,"o3op2":1457}
```

id: chipID, unique identifier of the esp <br>
ts: timestamp in ISO 8601 format: YEAR-MONTH-DAY T HOUR:MINUTE:SECOND <br>
t: temperature (Celsius)<br>
h: relative humidity (Percent)<br>
p: pressure<br>
p25: concentration of pm2.5<br>
p10: concentration of pm10 <br>
no2op1: op1 output of the NO2 sensor <br>
no2op2: op2 output of the NO2 sensor <br>
o3op1: op1 output of the O3 sensor <br>
o3op2: op2 output of the O3 sensor <br>

The Data uplink happens once every 3 minutes. This is determined by the working period of the SDS011 sensor. Please configure this correctly as described at the top of this document.

## Future development

For the moment the data transmission does not use TLS, this is a possible future development

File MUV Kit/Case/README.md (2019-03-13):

This directory contains instructions to build the case for the air quality sensor.

The following documents are present:
* [Steps](https://github.com/waagsociety/air_quality_sensor_kit/blob/master/MUV%20Kit/Case/Steps.md) contains the steps to build the case
* [MUV Air Quality Kit Bill of Materials](https://github.com/waagsociety/air_quality_sensor_kit/blob/master/MUV%20Kit/Case/MUV%20Air%20Quality%20Kit%20Bill%20of%20%20Materials.md) contains the Bill Of Materials
* [Air Qual. Sensor_ Prototyping](https://github.com/waagsociety/air_quality_sensor_kit/blob/master/MUV%20Kit/Case/Air%20Qual.%20Sensor_%20Prototyping.md) contains the description of the design process

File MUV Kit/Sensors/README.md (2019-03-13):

# SENSORS



The kit developed for MUV is a modular system on which the following sensors can be attached:
* dust sensor
* temperature/humidity/pressure sensor
* noise sensor
* gases sensors

The pcbs used in the kit are both off-the-shelf products and can be produced in the fablab.

## Dust sensor
The dust sensor is the [SDS011](http://aqicn.org/sensor/sds011/) from [inovafitness](http://inovafitness.com/en/a/chanpinzhongxin/95.html) and it uses the principle of laser scattering technology.

The device is capable to measure the concentration of PM2.5, nominally it measures also PM10 but research papers shows the fact that the PM10 measurement is an extrapolation based on PM2.5 data.
Based on such results we will use the sensor to measure only PM2.5. The communication between the sensor and the main mcu is over serial.

The specifications are:
- Output: PM2.5, PM10
- Measuring Range: 0.0-999.9μg/m3
- Input Voltage: 5V
- Maximum Current: 100mA
- Sleep Current: 2mA
- Response Time: 1 second
- Serial Data Output Frequency: 1 time/second
- Particle Diameter Resolution: ≤0.3μm
- Relative Error: 10%
- Temperature Range: -20~50°C
- Physical Size: 71mm*70mm*23mm

The dust sensor doesn't need any support pcb, the cable you get with the sensor can be used to plug the device to the main sensors board, see [Hardware](https://github.com/waagsociety/air_quality_sensor_kit/tree/master/MUV%20Kit/Hardware).

## Temp/Hum/Pressure sensor
To measure temperature and humidity, the kit include the [BME280 sensor](https://www.bosch-sensortec.com/bst/products/all_products/bme280).

The operation ranges are:<br>
Pressure: 300-1100 hPa<br>
Temperature: -40~85°C<br>

The average current consumption (1Hz data refresh rate) is:<br>
1.8 μA @ 1 Hz (H, T)<br>
2.8 μA @ 1 Hz (P, T)<br>
3.6 μA @ 1 Hz (H, P, T)<br>
and the average current consumption in sleep mode is 0.1 μA.

The Humidity sensor:<br>
- Response time (τ63%): 1 s
- Accuracy tolerance: ± 3 % relative humidity
- Hysteresis: ≤ 2 % relative humidity

The Pressure sensor:<br>
- RMS Noise: 0.2 Pa (equiv. to 1.7 cm)
- Sensitivity Error: ± 0.25 % (equiv. to 1 m at 400 m height change)
- Temperature coefficient offset: ±1.5 Pa/K (equiv. to ±12.6 cm at 1°C temperature change)

It uses I2C or SPI communication interface, in the kit we use the first one.

## Noise sensor
The microphone included in the kit is the [ICS‐43432](https://www.invensense.com/wp-content/uploads/2015/02/ICS-43432-data-sheet-v1.3.pdf) from [Invensense](https://www.invensense.com/products/ics-43434/) and it features:



* Digital I²S Interface with High Precision 24‐bit Data  
* High 65 dBA SNR
* −26 dB FS Sensitivity
* ±1 dB Sensitivity Tolerance
* Wide Frequency Response from 50 Hz to 20 kHz
* Low Current Consumption: 1.0 mA
* High Power Supply Rejection: −80 dB FS
* 116 dB SPL Acoustic Overload Point
* Small 4 mm × 3 mm × 1 mm Surface‐Mount Package
* Compatible with Sn/Pb and Pb‐Free Solder Processes  
* RoHS/WEEE Compliant  

This sensor has its own dedicated mcu that is capable to run 44100 Khz sample frequency and I²S interface. The board is the Adafruit feather M0 basic, see [Hardware](https://github.com/waagsociety/air_quality_sensor_kit/tree/master/MUV%20Kit/Hardware).

## Gas sensors
The kit is designed to read up to two electro-chemical sensors from [Alphasense](http://www.alphasense.com/).
Two are the sensors that are recommended:
- [Nitrogen dioxide](http://www.alphasense.com/index.php/products/nitrogen-dioxide-2/)
- [Ozone](http://www.alphasense.com/index.php/products/ozone-2/)

### NO2 sensor
The sensor is the NO2-B43F embedded on the [ISB individual sensor board](http://www.alphasense.com/index.php/air/downloads/) from Alphasense. We are also investigating the possibility to have a support circuit for both sensors (instead of having an individual sensor board for each sensor, since this drives the price up).



The specifications of sensor are:
- Sensitivity nA/ppm at 2ppm No2 : -175 to -450
- Response time t90 (s) from zero to 2ppm NO2: < 60
- Zero current  nA in zero air at 20°C :  -50 to +70
- Noise* ±2 standard deviations (ppb equivalent) : 15
- Range  ppm NO limit of performance warranty : 20
- Linearity ppb error at full scale, linear at zero and 5ppm NO2 : < ±0.5
- Overgas limit maximum ppm for stable response to gas pulse : 50

<p align="center">

### O3 sensor
The [OX-B431](http://www.alphasense.com/WEB1213/wp-content/uploads/2018/12/OXB431.pdf) specifications are:
- Sensitivity nA/ppm at 1ppm O3 : -200 to -650
- Response time t90 (s) from zero to 1ppm O3 : < 45
- Zero current nA in zero air at 20°C : -70 to 70
- Noise* ±2 standard deviations (ppb equivalent) : 15
- Range ppm O3 limit of performance warranty : 20
- Linearity ppm error at full scale, linear at zero and 20ppm O3 : < ±0.5
- Overgas limit maximum ppm for stable response to gas pulse : 50

<p align="center">

Also in this case, the sensor in the kit uses the ISB individual sensor board.

## Calibration
The dust and the gas sensors require a calibration process to validate the data.
In the case of the dust sensor is recommended to execute the comparison of the SDS011 sensor with professional stations before the employment of the kit in the field of application. <br>
The gas sensors require more sophisticated process.
The workflow for a proper calibration has several steps, depending on the duration of the measurement time. Before placing the sensors in the field, it is necessary to execute a calibration closed to a professional station, the duration depends on the weather conditions, the longer the better, ideally at least 1-2 weeks. After the first calibration the sensors can be placed in the field and during the measurements time the data should be submitted to "on-fly calibration", continuous calibration during the night. At the end of the measuring time or after 6 month, it is recommended to have a second round of calibration at professional station as described above.
To have more information about the calibration, please see [Contacts](#contacts)

## Contacts
You can leave your comments or questions in the issue section of this repo.
If you have question about calibration, please contact stefano@waag.org

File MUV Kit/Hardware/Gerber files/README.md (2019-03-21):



The available gerber files are:
- MUV_sensors_pcb_2019-03-21
- MUV_noise_pcb_2019-03-21
- MUV_interface_pcb_2019-03-21
- MUV_gas_o3_pcb_2019-03-21
- MUV_gas_no2_pcb_2019-03-21.zip
- MUV_bme280_in_pcb_2019-03-21

From this folder you can download the zip files and use them to produce the pcb at external services.
The boards that you see on this page have been produced by https://jlcpcb.com/, production time was 3 days and delivery time was 3 days.

The gerber files was created with Eagle 9.1.3, using the default setting of jlcpcb.

The components and there placements is described in the [Hardware page](https://github.com/waagsociety/air_quality_sensor_kit/tree/master/MUV%20Kit/Hardware).

**NOTE 1**
In the Fab version, there is only one gas pcb and it is possible to select the gas (NO2 or O3), soldering a 0 ohm resistor between two traces.
In this version there are two different pcb for the two gases: one specific board for Nitrogen Dioxide and one pcb for the Ozone sensor.

**NOTE 2**
Some of the boards that are showed in the photos below, don't have ground plates, on the other side the design of the gerber files includes ground plates.

| MUV_sensors_pcb  |  |
| --- | --- |
| |  |
| |  |

| MUV_interface_pcb  |  |
| --- | --- |
| |  |
| |  |

| MUV_bme280_in_pcb  |  |
| --- | --- |
| |  |
| |  |

| MUV_gas_no2_pcb  |  |
| --- | --- |
| |  |
| |  |

| MUV_gas_o3_pcb  |  |
| --- | --- |
| |  |
| |  |

| MUV_noise_pcb  |  |
| --- | --- |
| |  |
| |  |

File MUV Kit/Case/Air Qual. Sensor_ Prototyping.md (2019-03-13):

# MUV Air quality sensor case

## Parts and Sizing

* 25 x: m3 washers
* 50 x: m3 nuts
* 2 x: m6 x 25 hook bolt
* 4 x: m6 nut
* 4 x: m6 washer
* 4 x: m5 nut
* 4 x: m5 washer
* 2 x: m4.5 wing nut (M4 also fits looser)
* 2 x: m4.5 wing bolts (m4 also fits looser)
* 4 x: m4.5 or m4 washers
* 7 x: m3 x 30mm bolts    
* 12 x: m3 x 12mm bolts
* 4 x: m3 x 25mm bolts
* 4 x: m3 x 15mm bolts

* 1 x 19.05mm blind grommet
* 1 x 22.23mm blind grommet
* 1 x 14.29mm OD 7.94mm ID grommet

## Enclosure internal Dimensions
L: 245, W: 190 H: 68mm(without lid)

### Dust sensor, SDS011

Has a 190MM cable as standard

* Air barb diameter: 7.05
* Air barb length: 11
* Air hose: 8mm OD 6mm ID
* Air hose length: 75mm
* Screws: 3 x m3 x 30mm

### Adafruit Feather M0 Basic Proto + PCB + noise sensor

* Cable: 200mm
* Screws: 4 x m3 x 30mm

### Sensors PCB

* Cable: 200mm
* Screws: m3 x 12mm

### Gas sensor w pcb

* Cable: 200mm
* Screws: m3 x 25mm

### Temp/Hum/Pressure sensor

* Cable: 200mm
* Min screw length: m3 x 15mm

### Inner Tube pieces for grip

Hose clamp strain relief:
71 x 42mm (x2)

Drain pipe grip pad: 
180 x 42mm

Balcony grip pad:
115 x 42mm(x2)

L section long pad:
135 x 40mm (x2)
w
L section short pads:
83 x 40mm (x2)

## The Brief

Design a case for the MUV air quality sensor.

**The case should:**

- Be able to hold, securely, all of the sensors of the kit (dust,temp/press/humid,noise, 2 x N02)
- Allow the proper functioning of all the sensors
- Be waterproof and durable enough to withstand wet weather
- Be able to be mounted securely outdoors (e.g. on lamp posts)
- Be easy to make
- Be easy to service
- Be easy to assemble
- Use redily available parts
 
**Challenges:**

I think allowing the sensors acess to the outside with the sensors without allowing moisture in is a big challenge.

The 2 gas sensors, the dust sensor and the temp/ humidity sensor will have to have access to the outside air to collect data properly. The usb cable for power must also be able to plug in to the main board. The microphone must also be able to record the audio from outside.

I think the best option is to have all of the holes on the bottom to avoid rain gathering in them from above. I will mount a "baseplate" to the screw holes in the bottom of the box. These holes are raised 11.1mm from the bottom of the box, so I will have an 11.1mm gap between the baseplate and the floor of the box where the air holes are. I will then mount the sensors to holes in the baseplate so they can poke through the baseplate to access the airflow. I think that by keeping this 11.1mm gap between the air holes and the sensors, I can stop rain from being able to reach the sensors. I will have to test it and see.

I will have to come up with a way to seal the components to the holes, I think glue or silicone would work but I would like to try to make some gaskets or O-rings myself and see if they stop the moisture. Using these, the sensors could be more easily removable for maintainance.




Another potetial problem will be allowing the status of the LED to be visible from the outside. To carry the light from the led to the wall of the case, I will try to use "light piping" with a piece of frosted acrylic. The acryic will be sealed to a hole in the case wall.



http://blog.stratasys.com/wp-content/uploads/2015/10/3d-printed-light-pipes-e1443786870121.jpg 

If that does not work, or if I dont have the time, I will replace the light pipe with a simple Acrylic window.

**Designing & Testing:**

For the outer enclosure of the sensors I will use an off-the-shelf waterproof enclosure. I will then modify this enclosure to hold the sensors in a way which allows good collection of the data (good airflow). I will make my design for holding the sensors in the enclosure easily resizable for those who can only source other size enclosures.

I chose this waterproof enclosure for this first version of the air quality kit:
<https://www.amazon.de/dp/B0151KNMB2/ref=pe_3044161_185740101_TE_item>



This case is larger than I need but there are many others like it available in different sizes from online stores worldwide. This case had a short delivery time to me so I went with it.

So by modifying my baseplate design (changing the screw hole locations, scaling, changing sensor locations) it can be adapted to fit many of these outdoor enclosures. 

I can mount the sensors to the baseplate simply with screws and nuts, as the PCBs have screw holes in the corners already. 

I decided to cut out the bottom of the enclosure and replace it with a laser cut acrylic plate with holes cut in it for airflow to the sensors. This plate can be modified in response to testing to increase or decrease the airflow by using more or less air flow holes.






The kit must operate in a outdoor setting such as a balcony. To secure the kit in this setting, I chose to design another plate from acrylic which can attach to the enclosure. The mounting plate will allow hose clamps to attach for mounting to drain pipes and clamps to attach for mounting to railings.



**Making**

During the process of making my design, I made small tests to see if my measurements were correct in less costly materials such as cardboard and poplar plywood. This was important because I only had enough acrylic to cut the final parts once.









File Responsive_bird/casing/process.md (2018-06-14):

# Process

## Drawings to cut
cutprints

These are the drawings used to make the casing. The drawing on the left creates a thin wall, in the prototype I stacked 7 of these wall parts of 3 mm MDF. 
The drawing on the right is the front and the backpanel. In the prototype, the front panel is made of 3 mm acrylic and the back panel 3mm MDF.

### Settings laser cutter
The settings of the laser cutter were:
MDF 3 mm : 
Speed : 50, Power : 80, Corner Power : 25
Acrylic 3 mm :
Speed : 50 Power : 80 Corner Power : 25

## Sizes
The width of the bird, measured from its tail to the tip of its beak, is 265 mm. 
My advise is to make the casing slighly bigger so the electronics will fit better.

## Assemble



The parts are stacked as shown; the acrylic front plane at the bottom, followed by 7 wall parts. These parts are but together by 5 long bolts with a nut on top.
The bolt at the position of the eye of the bird has a spacer of 15 mm around it to support the back panel.



## Backpanel

I drilled some holes in the back panel to be able to attach the components. The hole I drilled for the DC motor was too big but it needed to have a firm grip to make the housing rotate. To make this firm grip, I used a small piece of rubber found in the fablab. 

measurements





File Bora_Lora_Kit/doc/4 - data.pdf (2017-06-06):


Bora Lora Kit – The Story

### 4. DATA VISUALIZATION and DATA

### 4.1 Visualization Platform

To offer the possibility of a real time monitor of the status and data of the sensors we decided to send our data to the smartcitizem.me platform.
Thanks | to | the | last | year | implementation | of the | Smartcitizen | V0 | API
(https://developer.smartcitizen.me/) and the support of the developers of Fablab Barcelona we uploaded automatically our measurements on their server.
This is the data flow:

The spec of Waag side are the following:
Server: Ubuntu 15.10, 4 CPUs quadcores, 32Gb RAM Mqtt broker: mosquitto
Back-end: Ruby, Postgres

The smartcitizen.me interface allows:
- geo-location on the map
- real time data on the low bar
- plot overtime with two data comparison
- download the data, .csv format

Fig4.1, smartcitizen.me of the Bora Lora kit in Noord.


Fig4.2, Bora Lora Noord data history comparison.

### 4.2 DATA

The data that the sensor kits send, can’t be directly visualize and they need to be filtered and understood. Electronic devices, measurements based on signal duration, low cost sensors, analog components, power supply are all error sources. They intrinsically introduce errors that in some cases can be estimated, for example: the 16bit ADC reads the NO2 sensor output with a worse case deviation of 0.5LSB and an integral non linearity of +/-3LSB. It’s necessary to keep in consideration these kinds of errors during calibration/evaluation processes of the sensor and barley they give friendly feedback if the user is interested only in the result, such as the amount of dust or NO2 concentration; we didn’t include these contributions in our platform.
The nature of the implemented sensors, optical and electrochemical, anyhow showed the need to eliminate wrong measurements. Fig4.3 reports the plot the original data set of the Dust Sensor in Noord, picks of 60.000 parts/cubicfeet are not credible; scaling the axis and zooming in, the plot shows indeed daily patterns that can be easily recognized and explained. The No2 sensor, on the other hand, is a slow device, it means that the first hours don’t give valid data, it’s highly affected by external factors, the linearity of the device is lost at temperatures higher than 30 degree Celsius and it need long calibration to avoid shift over time.
It’s important to keep in consideration any possible source of inaccuracy to understand the number that we get from the sensors. They are not perfect tools.


Fig4.3, Bora Lora raw data set.


Fig4.4, Bora Lora raw data set details.

The friendly accessibility of the data is also related to the unit of measure.
The raw data are expressed in parts per cubic feet and mV, respectively for particulate matters and the nitrogen dioxide, we decided to covert the data to the units used by European
environmental | standards | that | can | be | found | at | the | link
http://ec.europa.eu/environment/air/quality/standards.htm. The PM 2.5um, PM 10um and NO2 are defined in ug/m^3.


Fig4.4, Bora Lora PM2.5 data set on smartcitizen.me.

Everyone can have a look to the measurements following the links: Noord -> https://smartcitizen.me/kits/3767
West -> https://smartcitizen.me/kits/3764
ZuidOost -> https://smartcitizen.me/kits/3766

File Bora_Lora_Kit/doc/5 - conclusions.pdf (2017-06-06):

Bora Lora Kit – The Story

### 5. PROBLEMS and CONCLUSIONS

### 5.1 Problems

During the pilot study, the maintenance of the sensor kits was minimal and in only two occasions I had to visit the school for quick interventions:
- the blackout in Amsterdam on the 17th of January. Two gateways had to be rebooted.
- the migration to the new dashboard of TTN: the staging dashboard has been moved to the more complete console.thethingsnetwork.org/ dashboard. The migration to the
new | platform | was | easy,
https://www.thethingsnetwork.org/docs/network/migrate.html. I only paid the choice to personally identify my kit, I didn’t use OOTA configuration. I had to create new address ID per each device and programmed them again.

### 5.2 Conclusions

During this project I had the pleasure to work with LoraWAN and the services offered by TTN. The choice to communicate through Lora network and The Things Network was good for several reasons:
- fast and open support from TTN experts!
- friendly configuration of the devices on the dashboard,
- no need to access to private local networks,
- connection process smooth,
- stable network.

Our case was facilitated by the fact the application was in-door and not-mobile. I’m willing to develop a portable solution.

Many aspects could be improved, especially with the aim to create a portable air quality sensor kit: optimization of the code for power consumption, upload link only under trigger event, extra memory support to guarantee the collection of the data.

I’m happily surprised by the fact that we could run a 4 months study using a technology (hardware and software) under developments and diffusion.

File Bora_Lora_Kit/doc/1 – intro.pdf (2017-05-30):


Bora Lora Kit – The Story

### 1. INTRODUCTION

Within Making Sense project (http://making-sense.eu/), European Union’s Horizon 2020 research and innovation program, we run three pilot studies in Amsterdam:
1- Urban AirQ,
2- Smart Kids Lab,
3- Making sense of gamma radiation.

In this series of posts I will describe a part of the development that I implemented for the second pilot, Smart Kids Lab. To encourage, attract and empower kids in primary schools to measure and monitor the environment where they live, we used two approaches:
- a | list | of | low | technological | sensors
(http://waag.org/sites/waag/files/public/media/publicaties/smart-kids-lab-english.pdf),
- two air quality sensor kits placed the schools sending real time data to an online platform.

In total three schools and six classes took part to the project.

One of the sensor kits is called “Bora Lora kit” and it will be the subject of my posts.

Fig1.1, Bora Lora kit.

### 1.1 From Bora to Bora Lora

For the first pilot of Making Sense we developed an air quality sensor kit called Bora, you can find the documentation at the following link: https://github.com/waagsociety/makingsensor/tree/master/sensor_kit.


Bora Lora Kit – The Story

Fig1.2, Bora kit.

The kit measures NO2, Dust, temperature and humidity and during the operational period of the pilot, 16 citizens connected the devices to their wifi local network to send the data to our server.
With this experience I decided to further develop the sensor kit to improve some criticalities:
- un-stable and weak connectivity of the wifi module,
- high power consumption,
- lack of real time data visualization.

To improve the first two points we decided to use one the current emerging technology available for IoT applications: LoraWAN, https://www.lora-alliance.org/What-Is-LoRa/Technology ; we decided to implement in our sensor kit a Lora radio and to use The Things Network hardware and backend solutions to smooth the data flow. The Bora kit became then Bora Lora kit.

The lack of a real time visualization of the data was solved using the smartcitizen.me platform and the last released APIs of it.

### 1.2 Planning ahead

The only way I see to respect the deadlines of a project, especially when there are many parts involved, is to clearly understand what are the steps; this was my plan:

- Learn about LoraWAN and status of the art.
- Transform the Bora kit in a Lora connected device
- Evaluate the available infrastructures
- create the infrastructure if needed
- Create the bridge for the data between the sensor kit and the final digital platform.

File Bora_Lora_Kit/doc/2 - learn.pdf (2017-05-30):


Bora Lora Kit – The Story

### 2. LEARN

When it’s time to approach a new technology and apply it to a real application, such as a pilot study, it’s important to investigate the current available options of the hardware and software. The first step was to learn how to connect an end-device to Internet via The Things Network. The second step was the investigation in LoraWAN network in the area of my interest to see if it was necessary to provide and implement extra infrastructures, the gateways.


Fig2.1, sensor kit and gateway network. https://www.cooking-hacks.com/

### 2.1 The Things Network (TTN) workshop

We invited the experts, The Things Network, to give a workshop at the Waag. You can find
the | contents | of | the | workshop | here:
https://github.com/TheThingsNetwork/workshops/tree/workshop/kickoff/workshops/TheThin gsUno

TTN provided the hardware, the sweet and friendly The Things Uno, an Arduino Leonardo based IoT board, with embedded Lora Radio Module. It’s the perfect solution for fast learning and prototyping.


Fig2.2, TTN workshop at the Waag. September 2016

Thanks to the compatibility with Arduino environment, I didn’t need to install any new software and the only tools I used were: Arduino IDE and the TTN dashboard web interface. The dashboard is a browser page that allows you to configure your devices, to monitor them, to see the upcoming data.


Bora Lora Kit – The Story

During the workshop I learnt:
- to register a device in the TTN Dashboard
- to program my device so it can send data to TTN server
- to see my data on the dashboard

Many other features were explained and tested but these three were my goal.
I highly suggest to follow the step-by-step instructions provided by The Things Network.

For the pilot study I couldn’t use The Things Uno because it was under productions, so for my sensor kit I selected and assembled different hardware (see chapter 3).

### 2.2 TTN Gateway

After I made a first TTN standalone end-device (see chapter 3), I simply went around the schools with the sensor kit supplied by a power bank to verify network and connectivity.
At that time it was necessary to employ new gateways, the schools were not yet completely covered by TTN network and I got the chance to join the perfect meet-up for my purpose: “Build and connect your own Things Network Gateway”, https://www.meetup.com/Eindhoven-Internet-of-Things/events/234101548/.


Fig2.3, gateway workshop. September 2016

In one day we build and configure our own TTN gateway, raspberry pi based using the iC880A-SPI concentrator board.

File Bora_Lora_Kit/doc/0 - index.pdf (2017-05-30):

### BORA LORA KIT The Story

Index

1. Introduction
1.1 From Bora to Bora Lora
1.2 Planning ahead
2. Learn about LoraWAN
2.1 The Things Network workshop 2.2 Gateway workshop
3. Sensor Kit Hardware and Software 3.1 Hardware
3.2 Software
3.3 BOM
3.4 Three kits for three schools
4. Data visualization and Data 4.1 Data platform
4.2 DATA

5 Problems and Conclusion
5.1 Problems
5.2 Conclusions

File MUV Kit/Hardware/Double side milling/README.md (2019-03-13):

Steps in the double-sided milling process:








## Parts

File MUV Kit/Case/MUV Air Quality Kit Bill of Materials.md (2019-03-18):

# Bill of materials/ shopping list

## External case

The external case can be bought from Amazon:

https://www.amazon.de/dp/B0151KNMB2/ref=pe_3044161_185740101_TE_item

## Hardware

Can be purchased at local hardware shops (in this instructable I refer to Praxis, Gamma for NL for example). For some items you can choose between m4.5 or m4, choose consequently the same option for all the choices.

Its better to buy extra nuts, bolts and washers just in case!

```
* 25 x m3 washers
*  4 x m4.5 or m4 washers
*  4 x m5 washer
*  4 x m6 washer

* 50 x m3 nuts
*  4 x m4.5 wing nut (m4 also fits but looser)
*  4 x m5 nut
*  4 x m6 nut

* 12 x m3 x 12mm bolts
*  8 x m3 x 15mm bolts
*  4 x m3 x 25mm bolts
*  7 x m3 x 30mm bolts
*  4 x m4.5 x 30mm wing bolts (m4 also fits but looser)
*  4 x m5 x 25mm bolt

*  2 x m6 x 25 hook bolt
```

## Weatherproof grommets
(also available locally in hardware shops but much cheaper as part of kits online)

https://www.amazon.de/gp/product/B07DJ5WQ24

* 1 x 19.05mm blind gromet
* 1 x 22.23mm blind gromet
* 1 x 14.29mm OD 7.94mm ID grommet 

## Acrylic

500 x 500mm of 3mm acrylic

https://www.kunststofshop.nl/acrylaat-plexiglas/platen/melkwit-wit-en-zwart-standaard-maten/acrylaat-plaat-melkwit-ac02/a-3784-20000029

## Rubber

1/2 of An old inner tube (prefereably used and beyond repair. If really needed you can buy locally)

## Corner supports

I bought the 2 pairs of corner supports which I used as the balcony clamp from Praxis. They are a standard part but the hole locations may change and will have to be changed in the DXF.

The corner supports are also available locally in Praxis and Gamma.

15cm large corner supports:

https://www.gamma.nl/assortiment/intensions-practical-basic-steun-rail-u-luxe-standaardrail-15-cm-2-stuks/p/B141026

10cm small corner supports:

https://www.gamma.nl/assortiment/intensions-practical-basic-steun-rail-u-luxe-standaardrail-10-cm-2-stuks/p/B141024

## Stainless steel Hose Clamps

2 x hose clamps with a internal diameter suited for rain pipes in your country (we use 120 mm max internal diameter)

Available in local hardware shops, in Schmidt Houthandel in Amsterdam

https://nl.rs-online.com/web/c/fasteners-fixings/clips/hose-jubilee-clips/

## Other items

Superglue

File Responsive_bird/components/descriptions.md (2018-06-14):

# Component descriptions
components

## NO2 sensor
The used NO2 sensor is the Alphasense no2-b43f. Previous tests with the specific sensors led to a formula to calculate the correct NO2 concentration from the measurements of the sensor. This formula can be found in   
http://www.alphasense.com/index.php/products/nitrogen-dioxide-2/

## DC motor
In this prototype we used a Jameco relia pro 253471. We started with a smaller 6V dc motor but it was not strong enough to rotate the bird. Therefore we switched to this stronger motor. Something remarkable about the use of the motor is that the motor itself is connected to the object, and the small pin is fixed. In this way the motor spins instead of the small pin coming out of the motor. 

## Power supply
The Jameco relia pro needs 12 V, this is why we needed a power supply that was strong enough. The adapter showed at the following picture is the one we used for this prototype. It's the SYS1308-2412-W2E of the brand Sunny. 

img_2213klein

In this case, it would be a better fit to have a wireless power supply, since the object rotates, and to be placed more easily. 

## A/D Converter
In the prototype we use the 16 bit ads1115 adafruit a/d converter. In the arduino code we used the library Adafruit_ADS1015.h.
Using this converter, we were able to read the small differences the NO2 sensor measures. The converter of the Arduino is not precise enough for these measurements.

https://cdn-learn.adafruit.com/downloads/pdf/adafruit-4-channel-adc-breakouts.pdf

## Motor driver
This driver is used to be able to control the speed, the direction and the duration of the rotation of the motor. Triple check if the wires are connected correctly! A small mix up could destroy the motor driver, by blowing up the protection diode. 

Hook-up guide motor driver:
https://learn.sparkfun.com/tutorials/tb6612fng-hookup-guide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

## Circuit board
The circuit board is not as structured as I hoped but it works. The motor driver, the tilt switch and a resistor are on the back of the board while the dc motor and the power supply are connected to the front. 




This schematic circuit clearer shows what the circuit looks like:
bird circuit

## Tiltswitch
Using a tilt switch, the bird always knows in what position it's hanging.
This is the tilt switch used in the prototype:
https://uk.rs-online.com/web/p/non-mercury-tilt-switches/3615087/
This image (source: http://iamtechnical.com/tilt-switch) shows how tilt switches work:
tilt-switch

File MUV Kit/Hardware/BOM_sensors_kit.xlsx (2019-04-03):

 |  | READ THE BOM NOTE in the repo
 |  | The cost of the gas sensors are estimations, you have to contact the company for the exact cost.
Purchase cost (euro) | 496.344
Cost of 1 kit (euro) | 448.8729
 | Name | Description | Amount | Supplier | Order code | Price (euro) | Minimum | Purchase Cost (euro) buying minimu amount | Cost per Kit (euro) | Link
 | Feather HUZZAH esp8266 | Adafruit Feather HUZZAH with ESP8266 WiFi (*) | 1 | Open Circuit | P2821 | 19.95 | 1 | 19.95 | 19.95 | https://opencircuit.nl/Product/12958/Adafruit-Feather-HUZZAH-with-ESP8266-WiFi
 | Adalogger Feather | Adalogger FeatherWing - RTC + SD Add-on For All Feather Boards | 1 | Open Circuit | ADA-2922 | 10.5 | 1 | 10.5 | 10.5 | https://www.kiwi-electronics.nl/adalogger-featherwing-rtc-sd-add-on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
 | Feather Stacking Headers | 12-pin and 16-pin female headers | 2 | Open Circuit | ADA-2830 | 1.75 | 1 | 1.75 | 3.5 | https://opencircuit.nl/Product/12816/Feather-Stacking-Headers-12-pin-and-16-pin-female-headers
 | BME280 breakout board | BMP280 I2C or SPI Barometric Pressure / Temperature / Altitude Sensor | 1 | tinytronics | 001511 | 4.5 | 1 | 4.5 | 4.5 | https://www.tinytronics.nl/shop/nl/sensoren/temperatuur-lucht-vochtigheid/bme280-digitale-barometer-druk-en-vochtigheid-sensor-module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
 | ADS1115 breakout board | 4 Channel with Programmable Gain Amplifier | 2 | Open Circuit | 54390 | 17.95 | 1 | 17.95 | 35.9 | https://opencircuit.nl/Product/14001/ADS1115-16-Bit-ADC-4-kanaals-met-Programmeerbare-gain-versterker
 | Feather M0 Basic Proto | Adafruit Feather M0 Basic Proto - ATSAMD21 Cortex M0 | 1 | Kiwi electronics | ADA-2772 | 23.95 | 1 | 23.95 | 23.95 | https://www.kiwi-electronics.nl/adafruit-feather-m0-basic-proto-atsamd21-cortex-m0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
 | ICS-43432 breakout board | ICS43432 I2S DIGITAL MICROPHONE | 1 | Arduino | E000098 | 14.9 | 1 | 14.9 | 14.9 | https://store.arduino.cc/ics43432-i2s-digital-microphone
 | female connector for mic | Board-To-Board Connector, 2.54 mm, 3 Contacts, Receptacle, M20 Series, Through Hole, 1 Rows | 2 | Farnell | 7991924 | 0.491 | 10 | 4.91 | 0.982 | https://nl.farnell.com/harwin/m20-7820346/socket-pcb-0-1-3way/dp/7991924
 | SDS011 | PM2.5 sensor | 1 | tiny tronics | 1548 | 25 | 1 | 25 | 25 | https://www.tinytronics.nl/shop/nl/sensoren/temperatuur-lucht-vochtigheid/nova-sds011-hoge-precisie-laser-stofsensor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
 | NO2-B43F | NO2 sensor Compact, 4-electrode, low ppb | 1 | Alphasense | CONTACT THE COMPANY |  |  | 50 | 50 | http://www.alphasense.com/index.php/products/nitrogen-dioxide/
 | OX-B431 | O3 Compact, 4-electrode, low ppb | 1 | Alphasense |  |  |  | 50 | 50 | http://www.alphasense.com/index.php/products/ozone-2/
 | ISB Individual Sensor Board | ISB for B series 4-electrode sensors | 2 | Alphasense |  |  |  | 200 | 200 | http://www.alphasense.com/index.php/products/support-circuits-air/
Sensor pcb
 | JP2 | Board-To-Board Connector, 2.54 mm, 16 Contacts, Receptacle, WR-PHD Series, Through Hole, 1 Rows | 1 | Farnell | 2827905 | 1.2 | 10 | 12 | 1.2 | https://nl.farnell.com/wurth-elektronik/61301611821/connector-rcpt-16pos-1row-2-54mm/dp/2827905
 | JP1 | Board-To-Board Connector, 2.54 mm, 12 Contacts, Receptacle, WR-PHD Series, Through Hole, 1 Rows | 1 | Farnell | 2827901 | 0.713 | 10 | 7.13 | 0.713 | https://nl.farnell.com/wurth-elektronik/61301211821/connector-rcpt-12pos-1row-2-54mm/dp/2827901
 | J-GAS, J-DB, J-BME | Grove - Universal 4-Pin Connector | 4 | Kiwi electronics | SS-110990030 | 0.15 | 10 | 1.5 | 0.6 | https://www.kiwi-electronics.nl/grove-universal-4-pin-connector-10-pack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
 | 05-JST-B5B | Wire-To-Board Connector, Vertical, 2.5 mm, 5 Contacts, Header, XH Series, Through Hole, 1 Rows | 1 | farnell | 1516281 | 0.147 | 100 | 14.7 | 0.147 | https://nl.farnell.com/jst-japan-solderless-terminals/b5b-xh-a-lf-sn/header-tht-vertical-2-5mm-5way/dp/1516281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
 | Q1 Q2 | MOSFET Transistor, N Channel, 1.7 A, 30 V, 0.065 ohm, 10 V, 1.6 V | 2 | farnell | 9845429 | 0.36 | 5 | 1.8 | 0.72 | https://nl.farnell.com/on-semiconductor/nds355an/mosfet-n-sot-23/dp/9845429?st=NDS355AN
 | R1 R2 R3 R4 | RC1206JR-0710KL - SMD Chip Resistor, 1206 [3216 Metric], 10 kohm, RC Series, 200 V, Thick Film, 250 mW | 4 | farnell | 9240640 | 0.061 | 10 | 0.61 | 0.244 | https://nl.farnell.com/yageo/rc1206jr-0710kl/res-10k-5-0-25w-1206-thick-film/dp/9240640
 | D1 D2 | Fast / Ultrafast Diode, 100 V, 1 A, Single, 1 V, 50 ns, 30 A | 2 | farnell | 2675010 | 0.361 | 5 | 1.805 | 0.722 | https://nl.farnell.com/webapp/wcs/stores/servlet/ProductDisplay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
Interface pcb
 | JP3 | Board-To-Board Connector, 2.54 mm, 12 Contacts, Receptacle, WR-PHD Series, Through Hole, 1 Rows | 1 | Farnell | 2827901 | 0.713 | 10 | 7.13 | 0.713 | https://nl.farnell.com/wurth-elektronik/61301211821/connector-rcpt-12pos-1row-2-54mm/dp/2827901
 | JP1 | Board-To-Board Connector, 2.54 mm, 16 Contacts, Receptacle, WR-PHD Series, Through Hole, 1 Rows | 1 | Farnell | 2827905 | 1.2 | 10 | 12 | 1.2 | https://nl.farnell.com/wurth-elektronik/61301611821/connector-rcpt-16pos-1row-2-54mm/dp/2827905
 | SW_RST, SW_CONFIG | Tactile Switch, B3SN Series, Top Actuated, SMD, Round Button, 160 gf, 50mA at 24VDC | 2 | Farnell | 2076274 | 0.721 | 5 | 3.605 | 1.442 | https://nl.farnell.com/omron-electronic-components/b3sn-3112p/switch-6x6x3-1mm-sealed-1-57n/dp/2076274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
 | R1 | RC1206JR-0710KL - SMD Chip Resistor, 1206 [3216 Metric], 10 kohm, RC Series, 200 V, Thick Film, 250 mW | 4 | farnell | 9240640 | 0.061 | 10 | 0.61 | 0.244 | https://nl.farnell.com/yageo/rc1206jr-0710kl/res-10k-5-0-25w-1206-thick-film/dp/9240640
 | R2 | RC1206FR-07470RL - SMD Chip Resistor, 1206 [3216 Metric], 470 ohm, RC Series, 200 V, Thick Film, 250 mW | 1 | farnell | 9240926 | 0.0699 | 10 | 0.699 | 0.0699 | https://nl.farnell.com/yageo/rc1206fr-07470rl/res-470r-1-0-25w-1206-thick-film/dp/9240926
 | C1 | C1206C104KARACTU - SMD Multilayer Ceramic Capacitor, Tip & Ring, 0.1 µF, 250 V, 1206 [3216 Metric], ± 10%, X7R | 1 | farnell | 2429364 | 0.299 | 5 | 1.495 | 0.299 | https://nl.farnell.com/kemet/c1206c104karactu/cap-0-1-f-250v-10-x7r-1206/dp/2429364?st=C1206C104KARACTU
 | LED1 | WS2812B RGB Led, Neopixel, package 5050 | 1 | Opencircuit | 10707 | 0.195 | 10 | 1.95 | 0.195 | https://opencircuit.nl/Product/10707/WS2812B-RGB-led-10-stuks
Temp/Hum pcb
 | J3 | 61300611821 - Board-To-Board Connector, 2.54 mm, 6 Contacts, Receptacle, WR-PHD Series, Through Hole, 1 Rows | 1 | farnell | 2827893 | 0.29 | 10 | 2.9 | 0.29 | https://nl.farnell.com/wurth-elektronik/61300611821/connector-rcpt-6pos-1row-2-54mm/dp/2827893
 | J1 | Grove - Universal 4-Pin Connector | 1 | Kiwi electronics | SS-110990030 | 0.15 | 10 | 1.5 | 0.15 | https://www.kiwi-electronics.nl/grove-universal-4-pin-connector-10-pack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
Gas pcb
 | J2 | Grove - Universal 4-Pin Connector | 2 | Kiwi electronics | SS-110990030 | 0.15 | 10 | 1.5 | 0.3 | https://www.kiwi-electronics.nl/grove-universal-4-pin-connector-10-pack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
 | JP1 | 2212S-10SG-85 - Board-To-Board Connector, 2.54 mm, 10 Contacts, Receptacle, 2212S Series, Through Hole, 1 Rows | 2 | farnell | 1593464 | 0.221 | 5 | 1.105 | 0.442 | https://nl.farnell.com/multicomp/2212s-10sg-85/socket-pcb-1-row-10way/dp/1593464
 | R1 - R2 | CRCW12060000ZSTA - SMD Chip Resistor, 1206 [3216 Metric], 0 ohm, CRCW Series, 200 V, Thick Film, 250 mW | 2 | farnell | 1692540 | 0.0847 | 10 | 0.847 | 0.1694 | https://nl.farnell.com/vishay/crcw12060000zsta/res-0r0-0-25w-1206/dp/1692540
 | C1 | C1206C104KARACTU - SMD Multilayer Ceramic Capacitor, Tip & Ring, 0.1 µF, 250 V, 1206 [3216 Metric], ± 10%, X7R | 2 | farnell | 2429364 | 0.299 | 5 | 1.495 | 0.598 | https://nl.farnell.com/kemet/c1206c104karactu/cap-0-1-f-250v-10-x7r-1206/dp/2429364?st=C1206C104KARACTU
 | C2 | 12065C105JAT2A - SMD Multilayer Ceramic Capacitor, 1 µF, 50 V, 1206 [3216 Metric], ± 5%, X7R, AVX 1206 MLCC | 2 | farnell | 1740706 | 0.698 | 5 | 3.49 | 1.396 | https://nl.farnell.com/avx/12065c105jat2a/cap-1-f-50v-5-x7r-1206/dp/1740706
Noise pcb
 | J1 | Grove - Universal 4-Pin Connector | 1 | Kiwi electronics | SS-110990030 | 0.15 | 10 | 1.5 | 0.15 | https://www.kiwi-electronics.nl/grove-universal-4-pin-connector-10-pack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
 | OTS1_short | Board-To-Board Connector, 2.54 mm, 12 Contacts, Receptacle, WR-PHD Series, Through Hole, 1 Rows | 1 | Farnell | 2827901 | 0.713 | 10 | 7.13 | 0.713 | https://nl.farnell.com/wurth-elektronik/61301211821/connector-rcpt-12pos-1row-2-54mm/dp/2827901
 | OTS1_long | Board-To-Board Connector, 2.54 mm, 16 Contacts, Receptacle, WR-PHD Series, Through Hole, 1 Rows | 1 | Farnell | 2827905 | 1.2 | 10 | 12 | 1.2 | https://nl.farnell.com/wurth-elektronik/61301611821/connector-rcpt-16pos-1row-2-54mm/dp/2827905
Extra
 | solid wire for the vias | solid core condactive wire, AWG >= 21 | 1 | Open Circuit | ADA-1881 | 1.5 | 1 | 1.5 | 1.5 | https://opencircuit.shop/Product/13971/Silicone-Cover-Stranded-Core-Wire-2m-26AWG-Black
 | grove cables | Grove - Universal 4 Pin Unbuckled 20cm Cable. | 4 | Kiwi electronics | SS-110990031 | 0.7 | 5 | 3.5 | 2.8 | https://www.kiwi-electronics.nl/grove-universal-4-pin-unbuckled-20cm-cable-5-pack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
 | sdcard | 8GB Micro SD card | 1 | open circuit | 11234 | 6 | 1 | 6 | 6 | https://opencircuit.nl/Product/11234/8GB-Micro-SD-geheugenkaart
 | USB power cable | Micro USB kabel - 1.8m | 1 | tinytronics | 924 | 2.5 | 1 | 2.5 | 2.5 | https://www.tinytronics.nl/shop/nl/kabels/usb/micro-usb-kabel-1.8m?search=usb
 | USB adapter | Goobay 59232 Dual USB Voeding - 5V 2.4A | 1 | tinytronics | 1750 | 7.5 | 1 | 7.5 | 7.5 | https://www.tinytronics.nl/shop/nl/voedingen/5v/goobay-59232-dual-usb-voeding-5v-2.4a-zwart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
 | battery for rtc | CR1220 3V lithium metal coin cell battery | 1 | allekables | 1296899 | 0.38 | 5 | 1.9 | 0.38 | https://www.allekabels.nl/knoopcel-batterij/1067/1296899/knoopcel-batterij.html

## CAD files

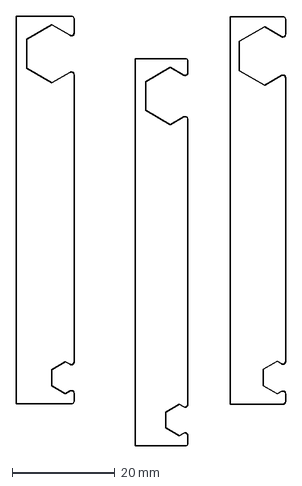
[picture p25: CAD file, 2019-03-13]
MUV Kit/Case/CAD/Laser cut files/aSSEMBLY TOOL.DXF
52.3 x 83.6 mm

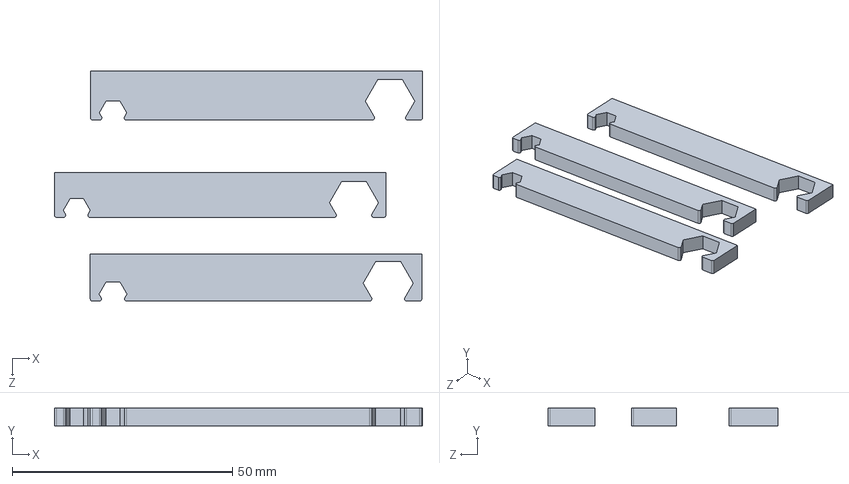
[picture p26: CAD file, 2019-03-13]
MUV Kit/Case/CAD/Solidworks/aSSEMBLY TOOL.SLDPRT
83.6 x 4.00 x 52.3 mm

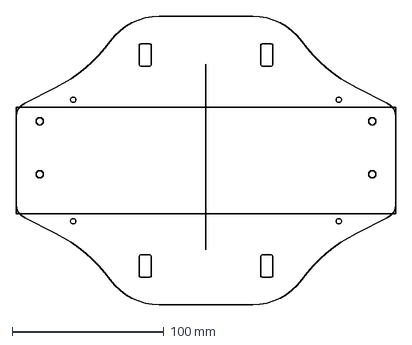
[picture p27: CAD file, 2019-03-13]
MUV Kit/Case/CAD/Laser cut files/Mounting Template.DXF
250.0 x 190.0 mm

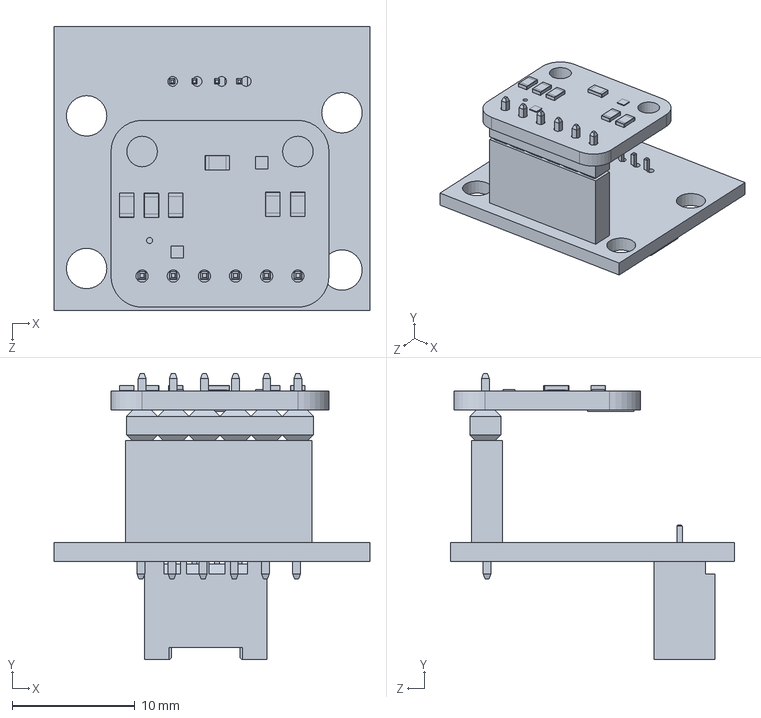
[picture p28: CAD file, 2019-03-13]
MUV Kit/Case/CAD/Solidworks/TEMPERATURE.SLDPRT
25.8 x 23.4 x 23.2 mm

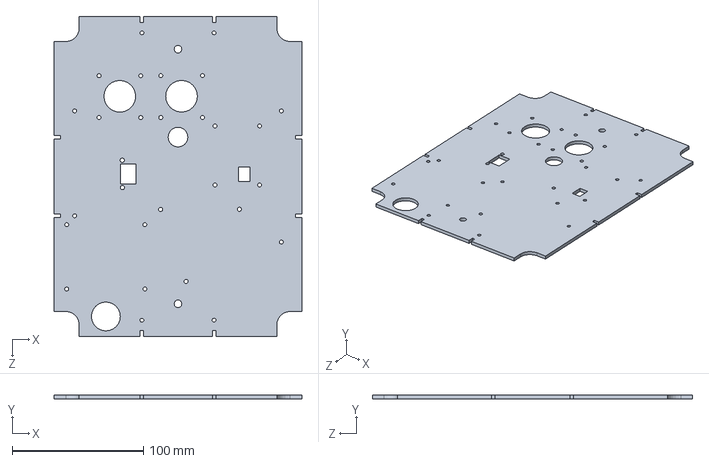
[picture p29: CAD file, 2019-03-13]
MUV Kit/Case/CAD/Solidworks/Base plate.SLDPRT
189.0 x 3.00 x 244.0 mm

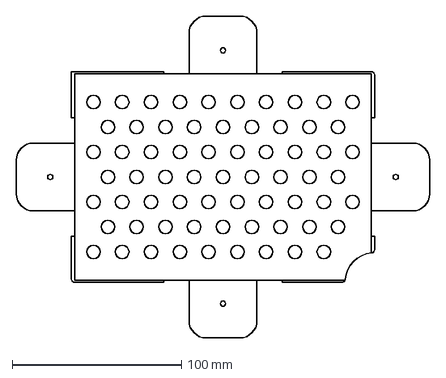
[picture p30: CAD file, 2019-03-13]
MUV Kit/Case/CAD/Laser cut files/air holes.DXF
244.0 x 190.0 mm

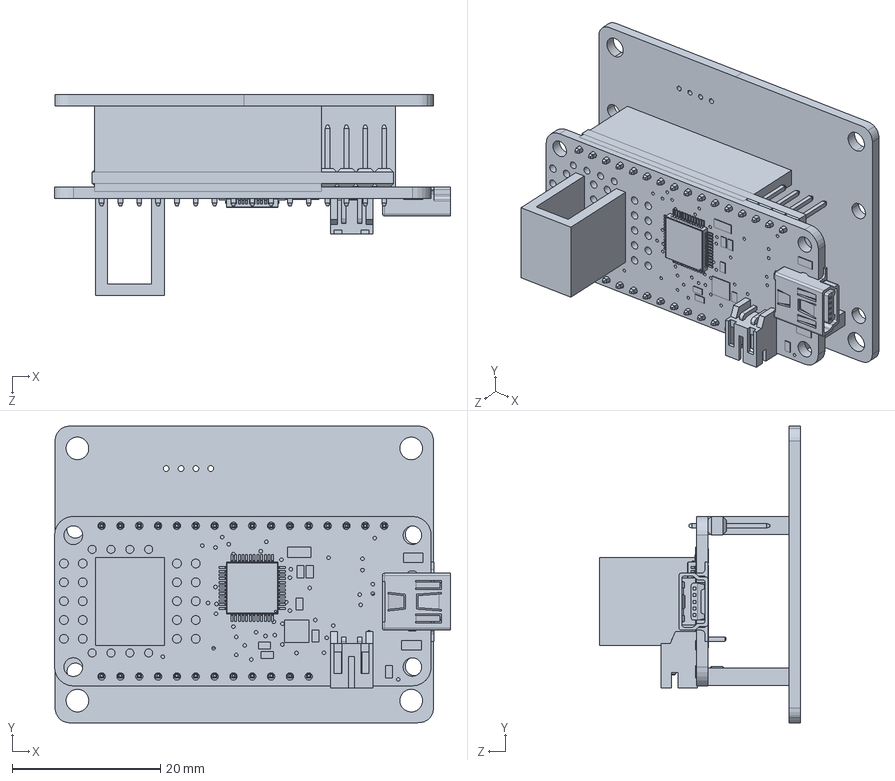
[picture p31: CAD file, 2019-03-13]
MUV Kit/Case/CAD/Solidworks/Protomic.SLDPRT
53.4 x 40.0 x 27.1 mm

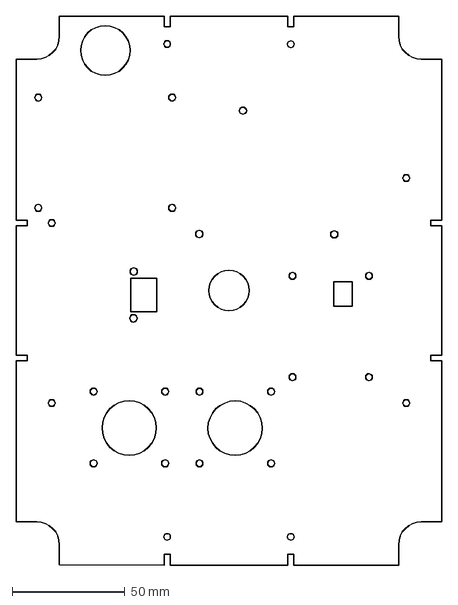
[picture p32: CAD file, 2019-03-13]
MUV Kit/Case/CAD/Laser cut files/Base plate.DXF
189.0 x 244.0 mm

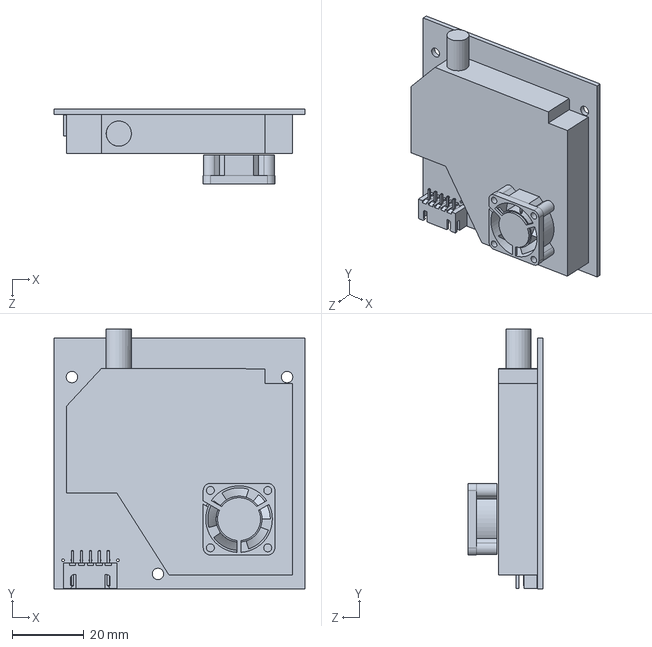
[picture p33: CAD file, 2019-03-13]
MUV Kit/Case/CAD/Solidworks/dust sENSOR.SLDPRT
70.0 x 72.5 x 20.9 mm

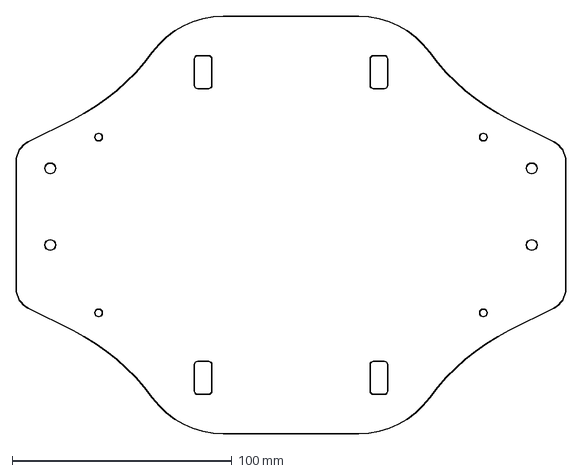
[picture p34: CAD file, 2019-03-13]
MUV Kit/Case/CAD/Laser cut files/mounting plate.DXF
250.0 x 190.0 mm

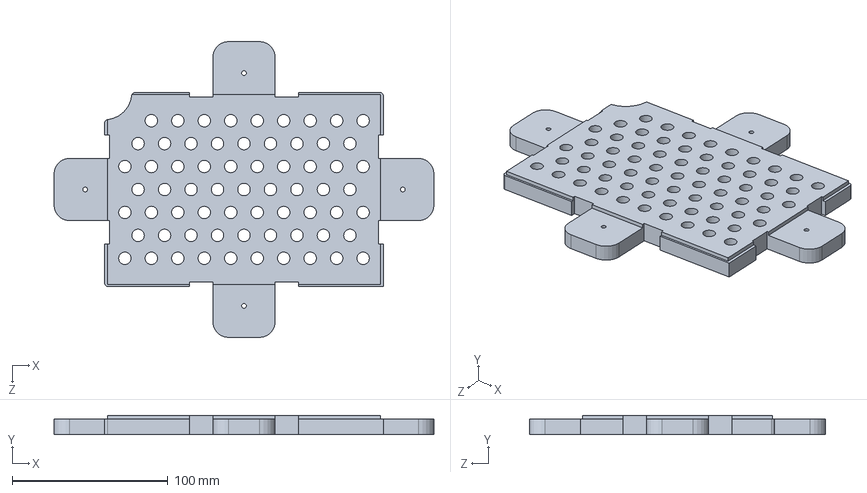
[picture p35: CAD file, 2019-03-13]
MUV Kit/Case/CAD/Solidworks/air holes.SLDPRT
244.0 x 12.5 x 190.0 mm

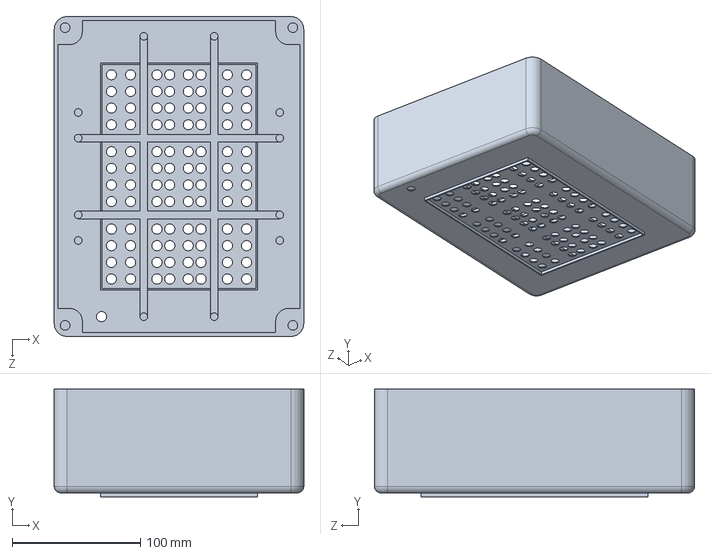
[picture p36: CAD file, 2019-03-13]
MUV Kit/Case/CAD/Solidworks/230x150x85 box.SLDPRT
195.0 x 84.0 x 250.0 mm

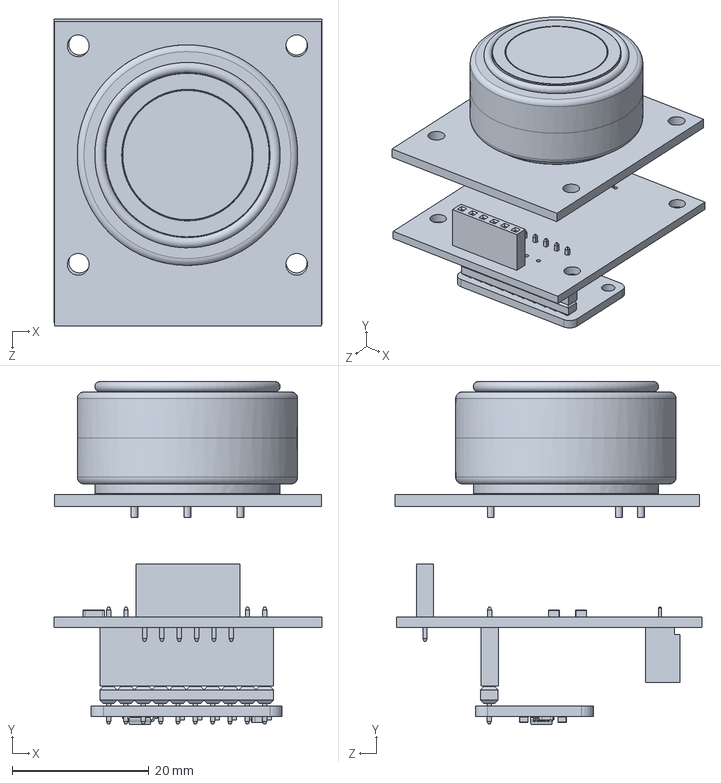
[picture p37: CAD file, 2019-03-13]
MUV Kit/Case/CAD/Solidworks/gas.SLDPRT
39.2 x 50.2 x 44.9 mm

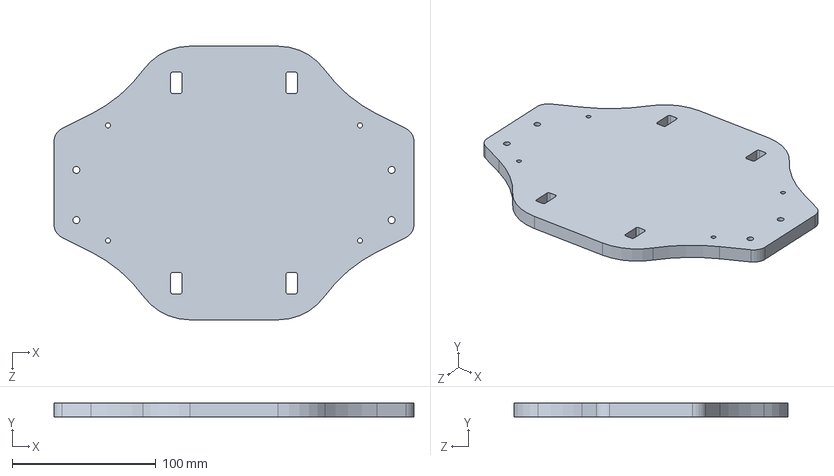
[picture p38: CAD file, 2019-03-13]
MUV Kit/Case/CAD/Solidworks/mounting plate.SLDPRT
250.0 x 10.0 x 190.0 mm

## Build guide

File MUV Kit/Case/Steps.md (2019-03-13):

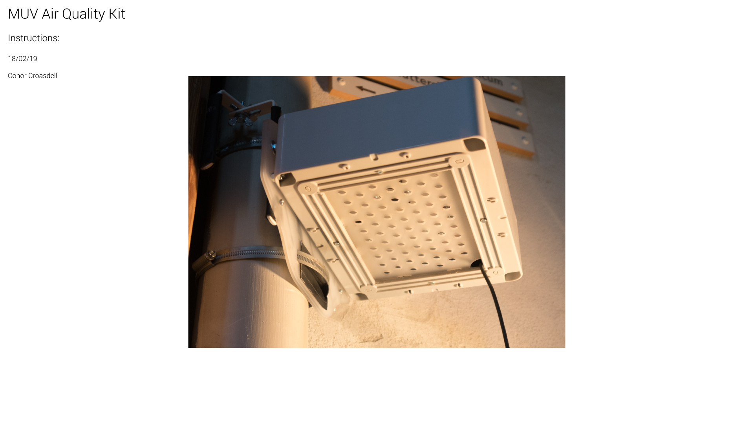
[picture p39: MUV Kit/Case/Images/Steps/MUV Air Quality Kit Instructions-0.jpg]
<p align="center"><p/>
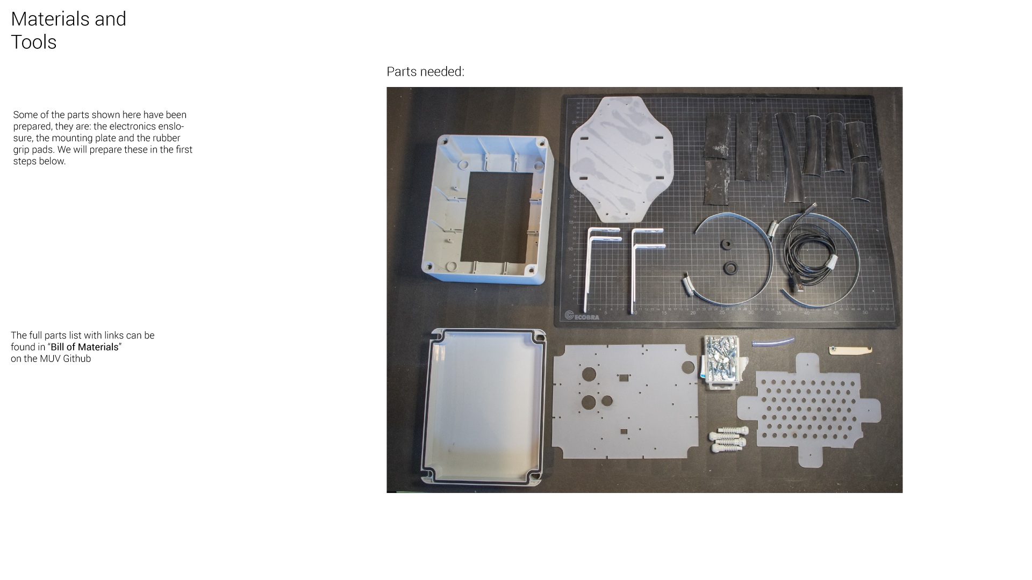
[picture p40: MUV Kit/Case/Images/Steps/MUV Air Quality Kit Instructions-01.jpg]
<p align="center"><p/>
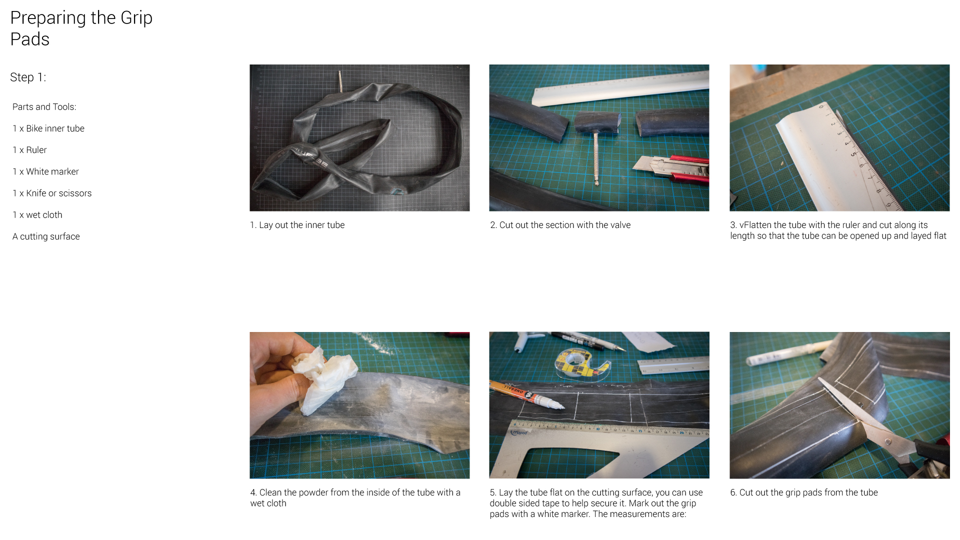
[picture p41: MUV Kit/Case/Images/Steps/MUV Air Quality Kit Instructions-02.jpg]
<p align="center"><p/>
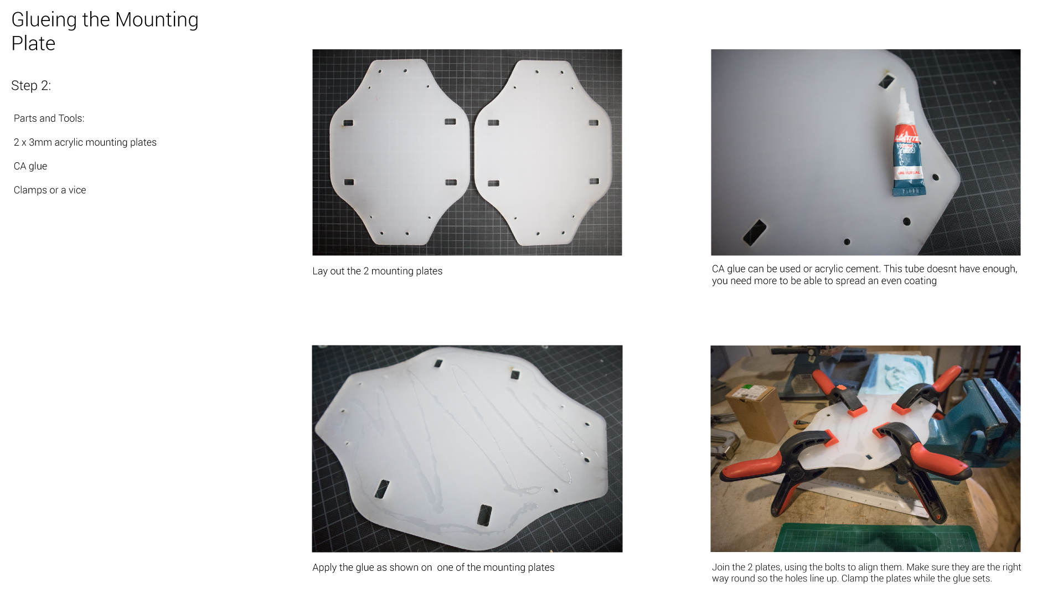
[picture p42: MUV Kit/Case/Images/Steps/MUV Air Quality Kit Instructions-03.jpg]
<p align="center"><p/>
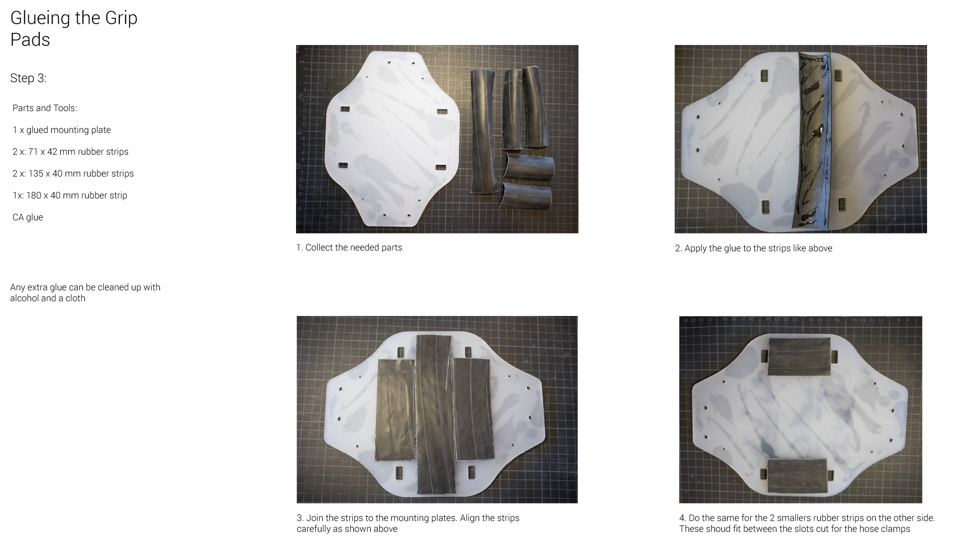
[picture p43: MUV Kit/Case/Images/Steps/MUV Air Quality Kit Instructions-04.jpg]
<p align="center"><p/>
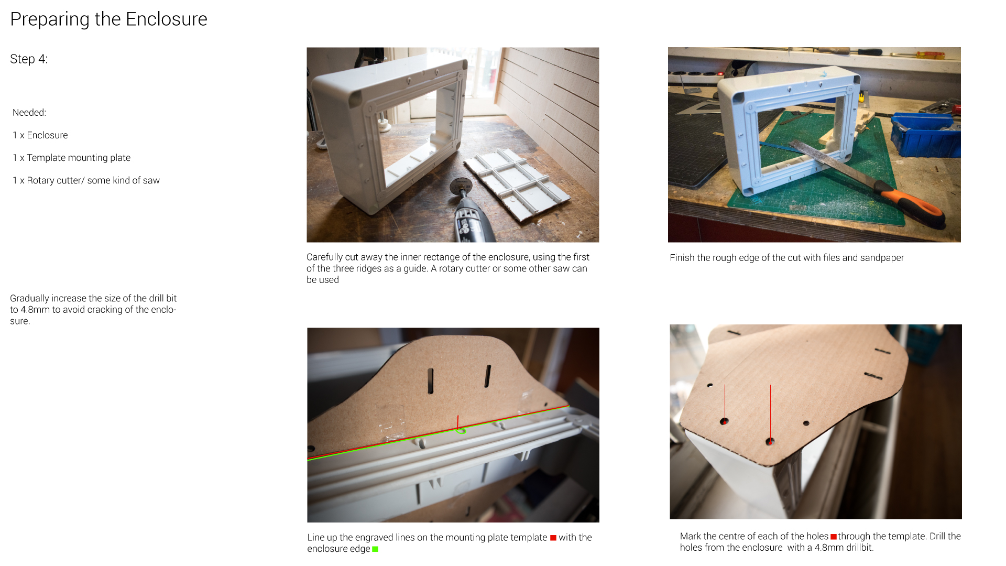
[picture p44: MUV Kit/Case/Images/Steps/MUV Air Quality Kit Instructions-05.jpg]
<p align="center"><p/>
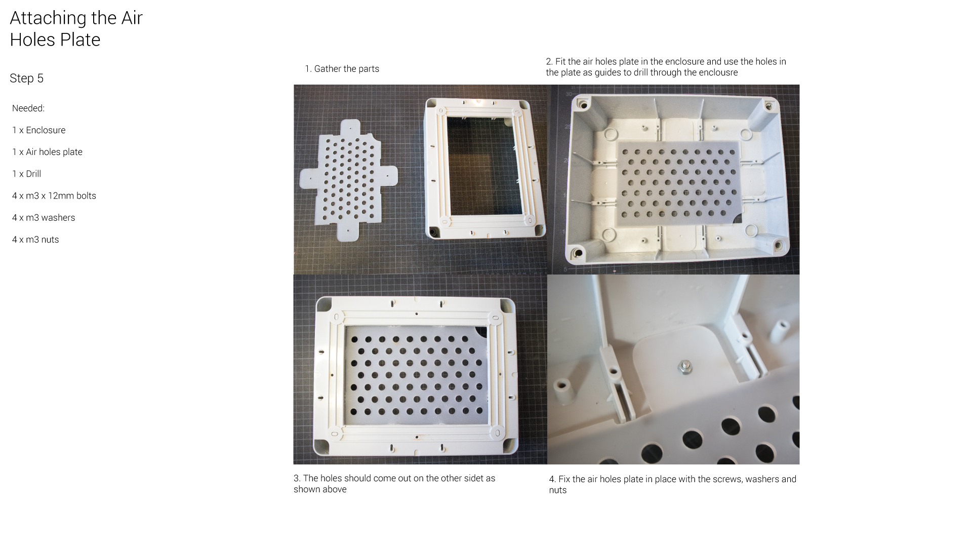
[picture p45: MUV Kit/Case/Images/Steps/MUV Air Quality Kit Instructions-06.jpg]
<p align="center"><p/>
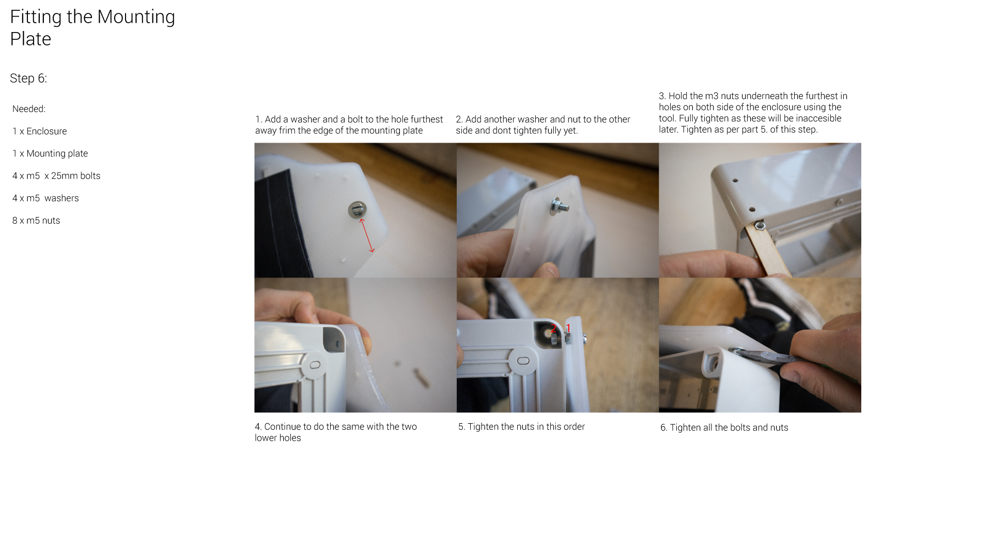
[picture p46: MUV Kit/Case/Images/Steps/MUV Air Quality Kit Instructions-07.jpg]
<p align="center"><p/>
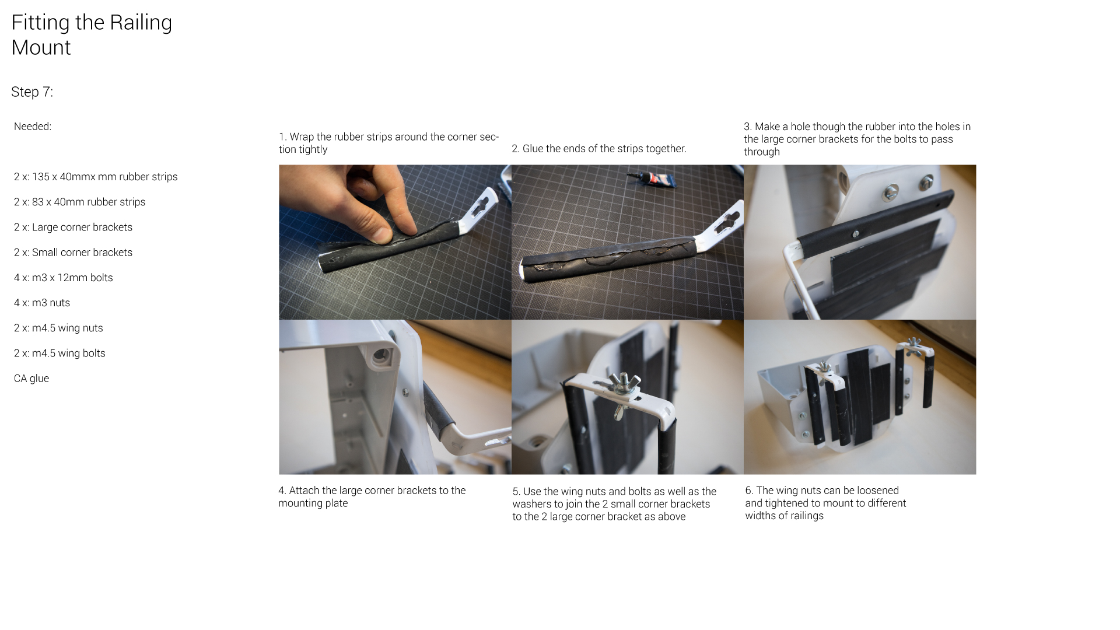
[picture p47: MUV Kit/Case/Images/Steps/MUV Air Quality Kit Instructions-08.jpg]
<p align="center"><p/>
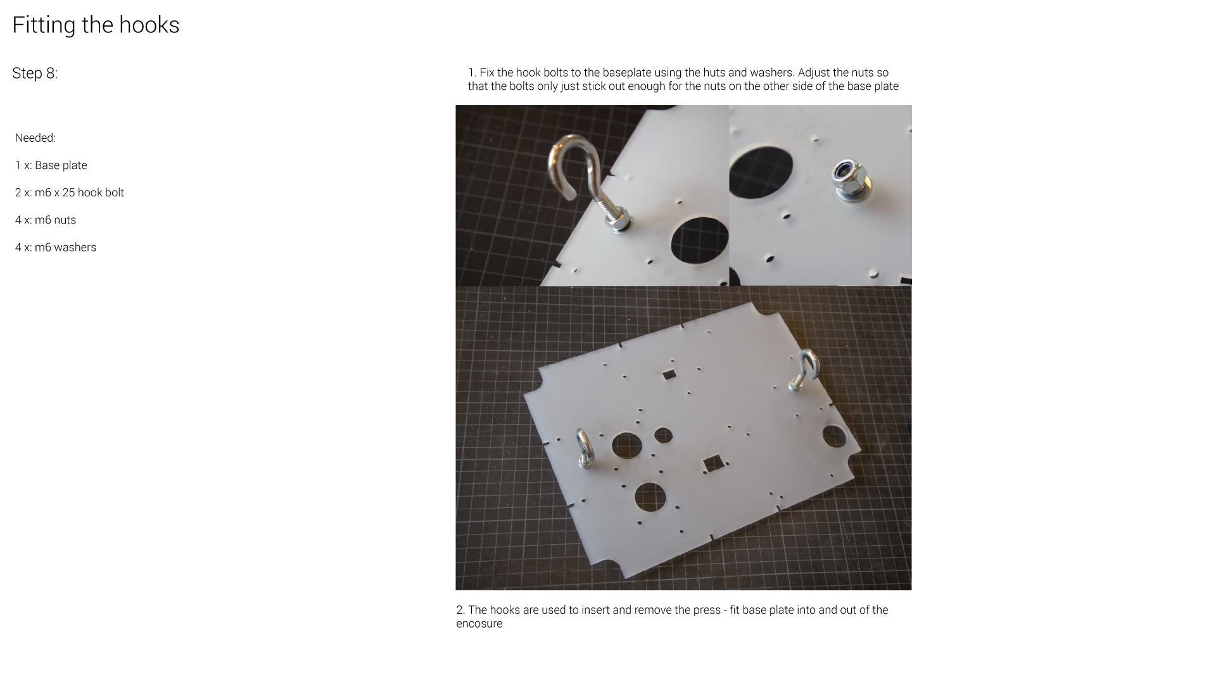
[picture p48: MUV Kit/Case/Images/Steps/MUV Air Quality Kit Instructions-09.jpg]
<p align="center"><p/>
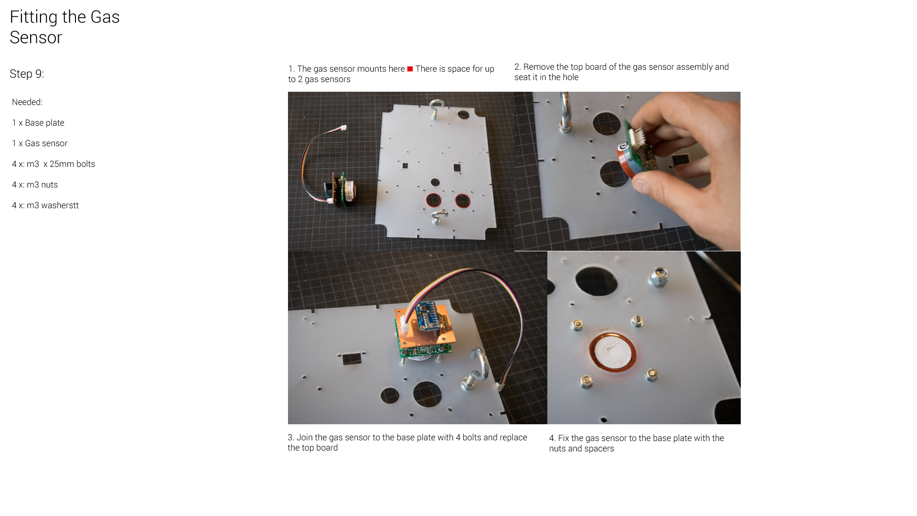
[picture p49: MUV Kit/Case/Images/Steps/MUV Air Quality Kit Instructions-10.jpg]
<p align="center"><p/>
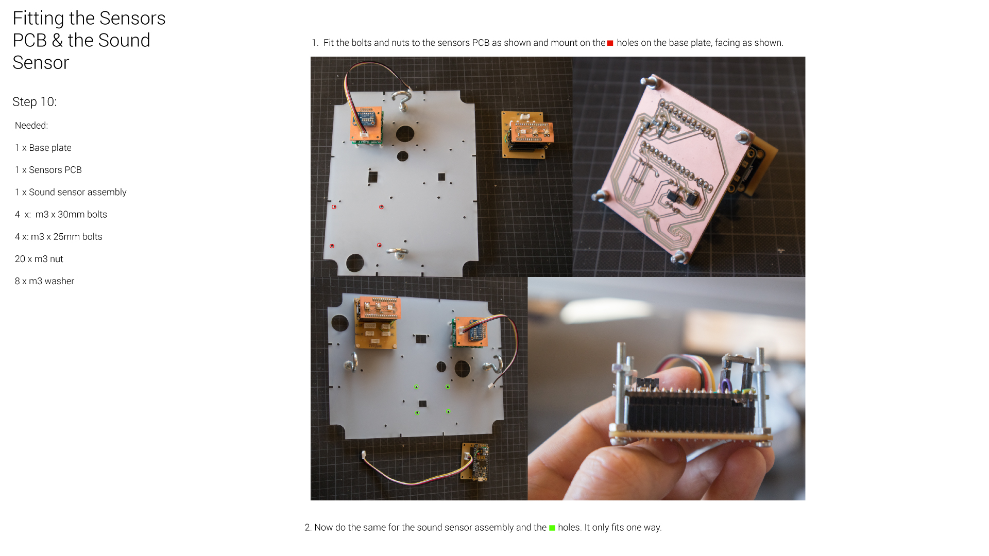
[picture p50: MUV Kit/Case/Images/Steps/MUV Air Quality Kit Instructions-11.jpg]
<p align="center"><p/>
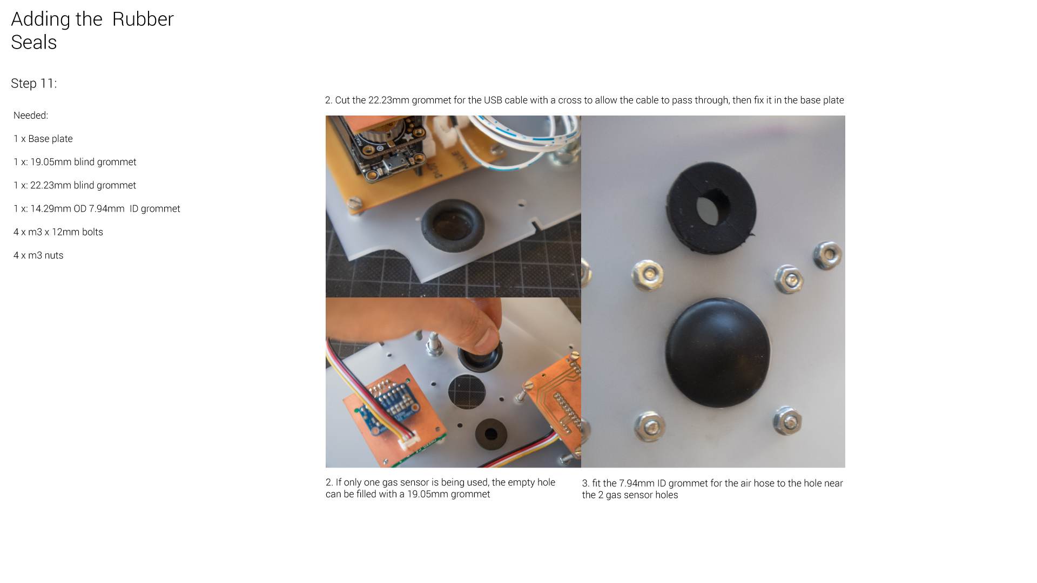
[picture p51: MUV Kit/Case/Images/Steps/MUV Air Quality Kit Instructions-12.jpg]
<p align="center"><p/>
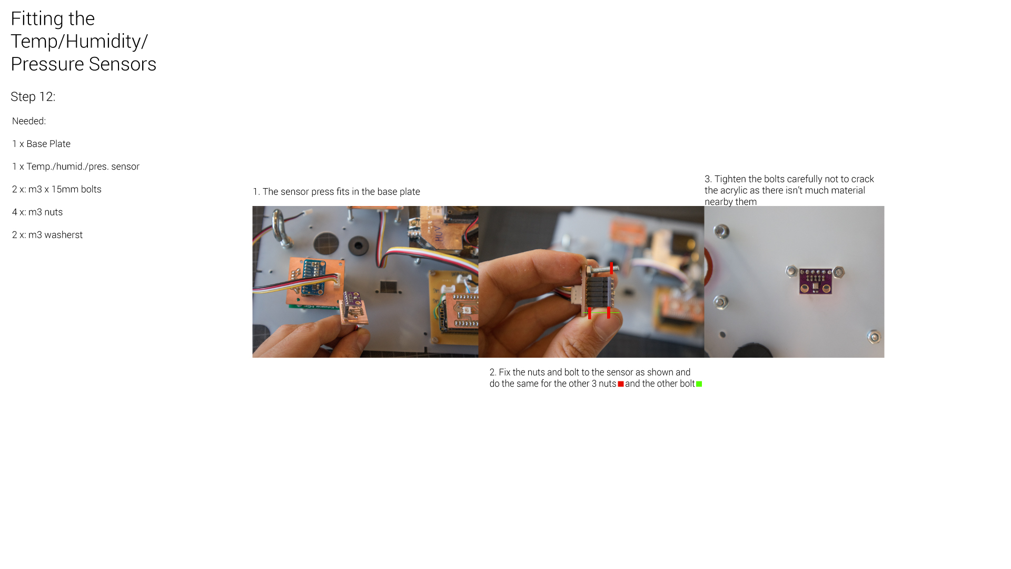
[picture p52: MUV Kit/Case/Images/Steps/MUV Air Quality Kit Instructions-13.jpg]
<p align="center"><p/>
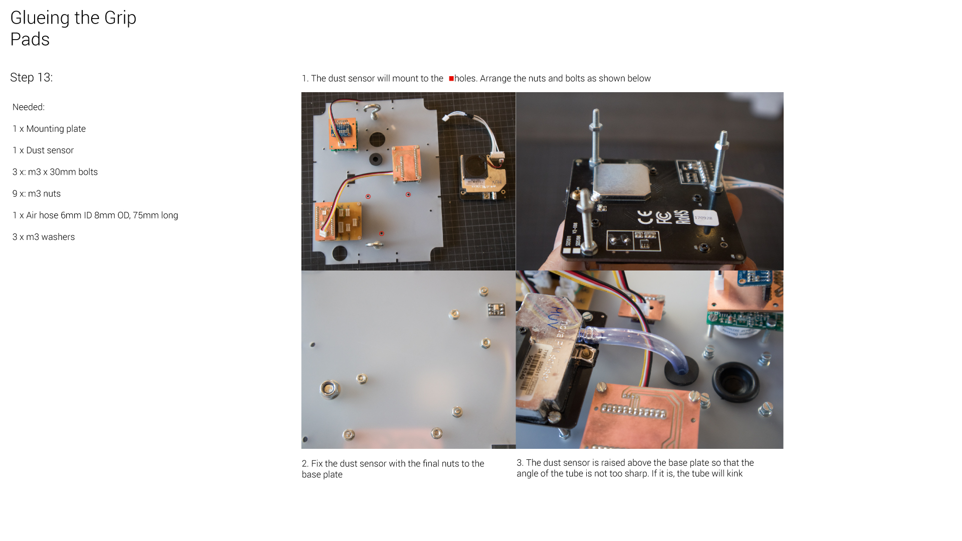
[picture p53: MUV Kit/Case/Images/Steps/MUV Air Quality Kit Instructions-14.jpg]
<p align="center"><p/>
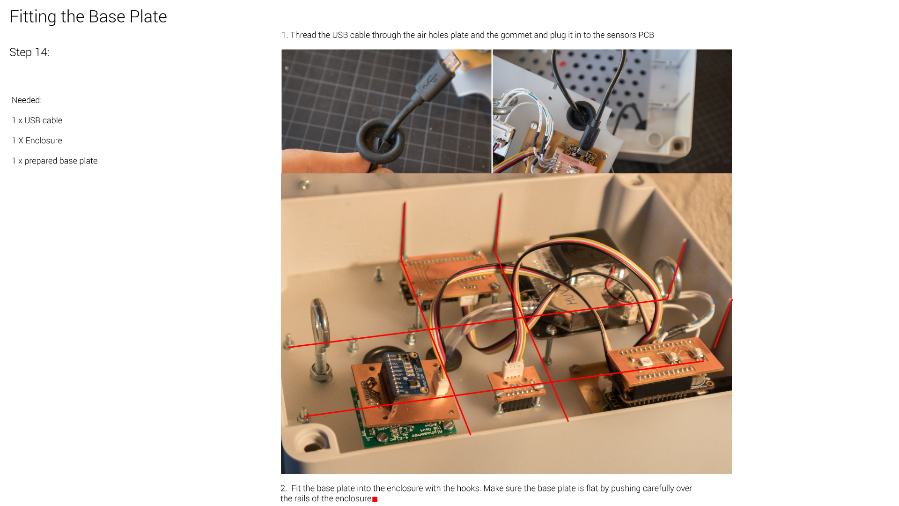
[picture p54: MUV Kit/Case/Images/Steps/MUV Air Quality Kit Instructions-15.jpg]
<p align="center"><p/>
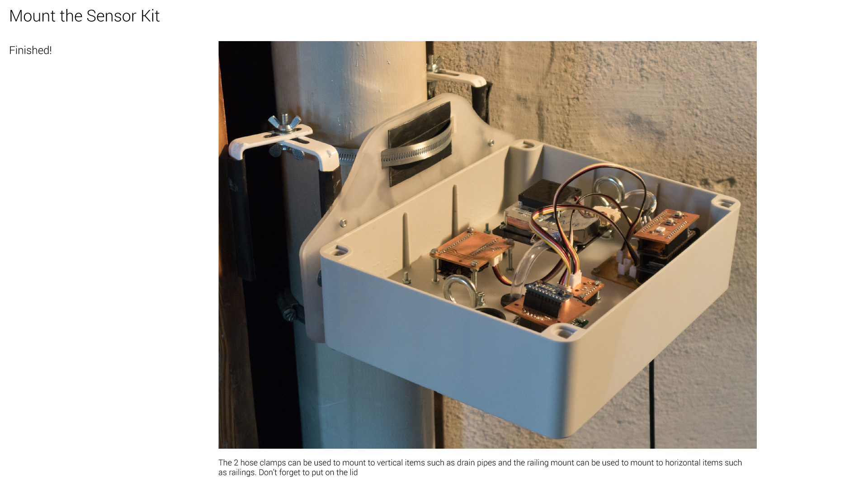
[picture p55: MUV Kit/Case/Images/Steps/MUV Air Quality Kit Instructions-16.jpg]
<p align="center"><p/>

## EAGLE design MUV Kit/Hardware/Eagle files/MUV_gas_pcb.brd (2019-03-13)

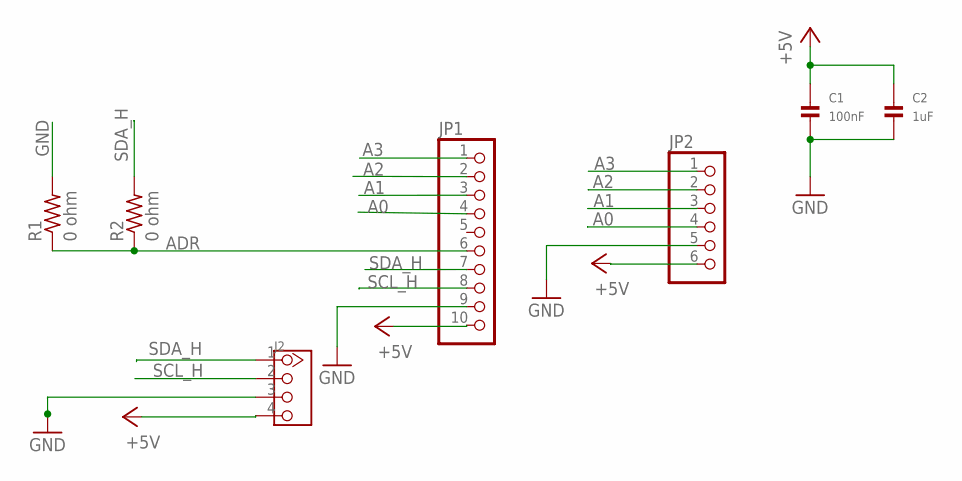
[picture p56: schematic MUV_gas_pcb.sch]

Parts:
C1: 100nF; 1206
C2: 1uF; 1206
J2: TWIG-4P-2.0-2.0; 4P-2.0
JP1: HEADER-1X10; 1X10_OVAL
JP2: HEADER-1X6; 1X06_OVAL
R1, R2: 0 ohm; 1206

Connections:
+5V: C1.1, C2.1, J2.4, JP1.10, JP2.6
A0: JP1.4, JP2.4
A1: JP1.3, JP2.3
A2: JP1.2, JP2.2
A3: JP1.1, JP2.1
ADR: JP1.6, R1.1, R2.1
GND: C1.2, C2.2, J2.3, JP1.9, JP2.5, R1.2
SCL_H: J2.2, JP1.8
SDA_H: J2.1, JP1.7, R2.2

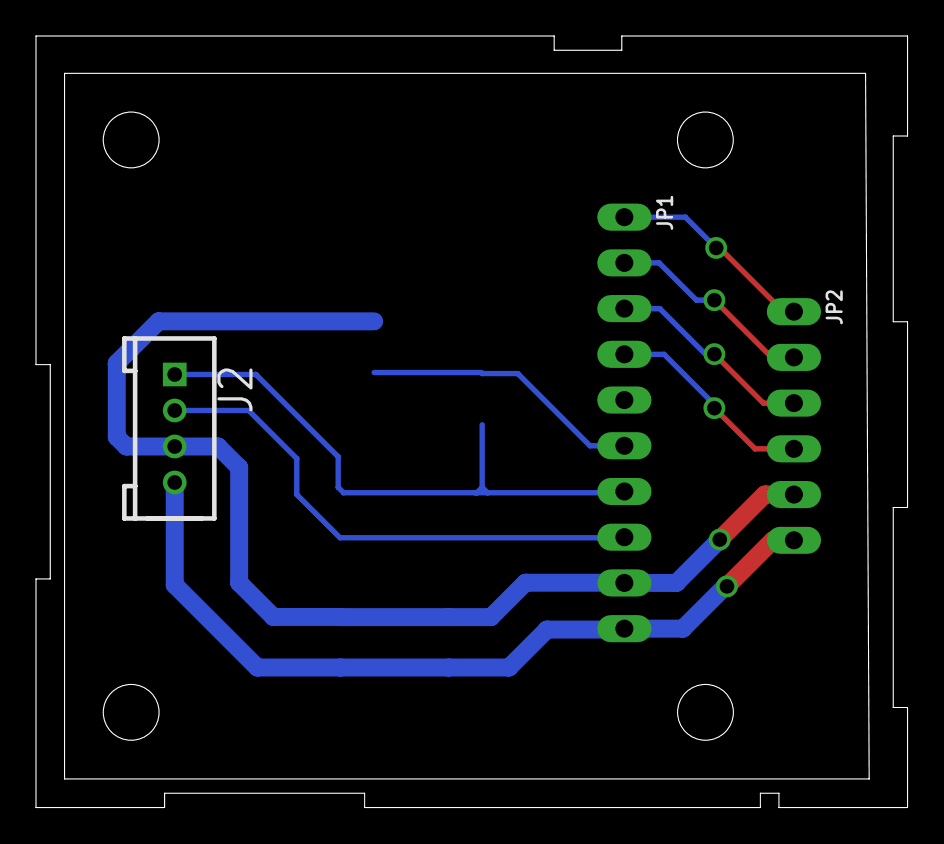
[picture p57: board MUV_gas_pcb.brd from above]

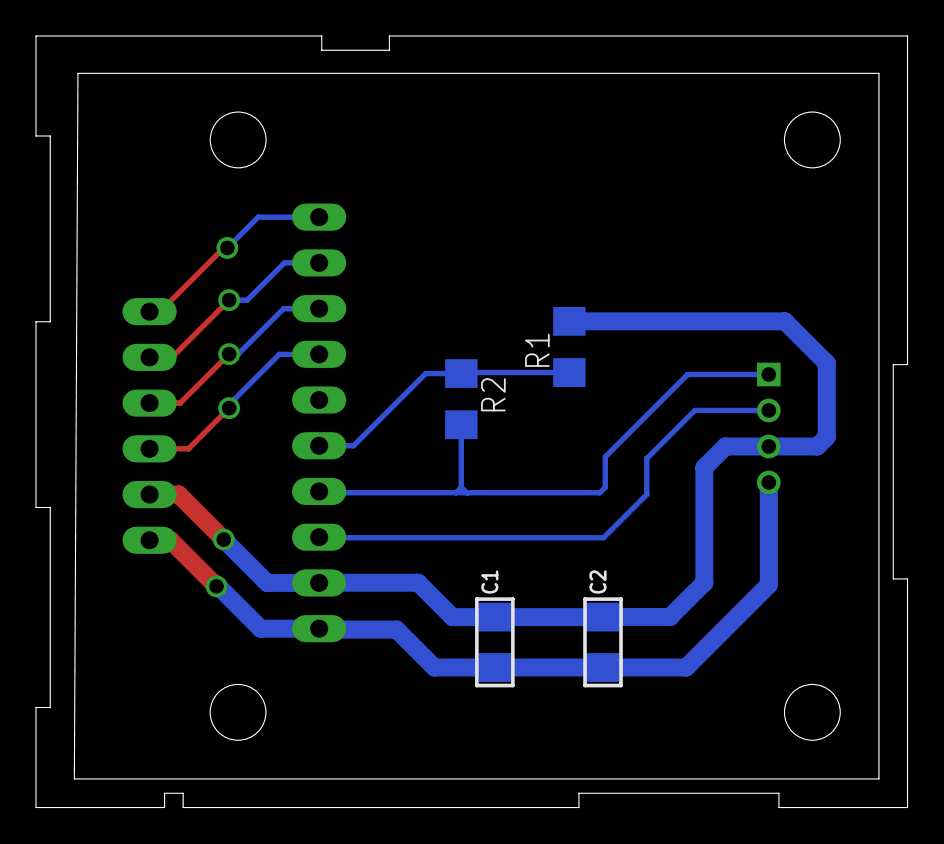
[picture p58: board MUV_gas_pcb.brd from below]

Board: 2 copper layers, 48.4 x 42.9 mm, 7 parts (4 on the bottom side), 9 nets.

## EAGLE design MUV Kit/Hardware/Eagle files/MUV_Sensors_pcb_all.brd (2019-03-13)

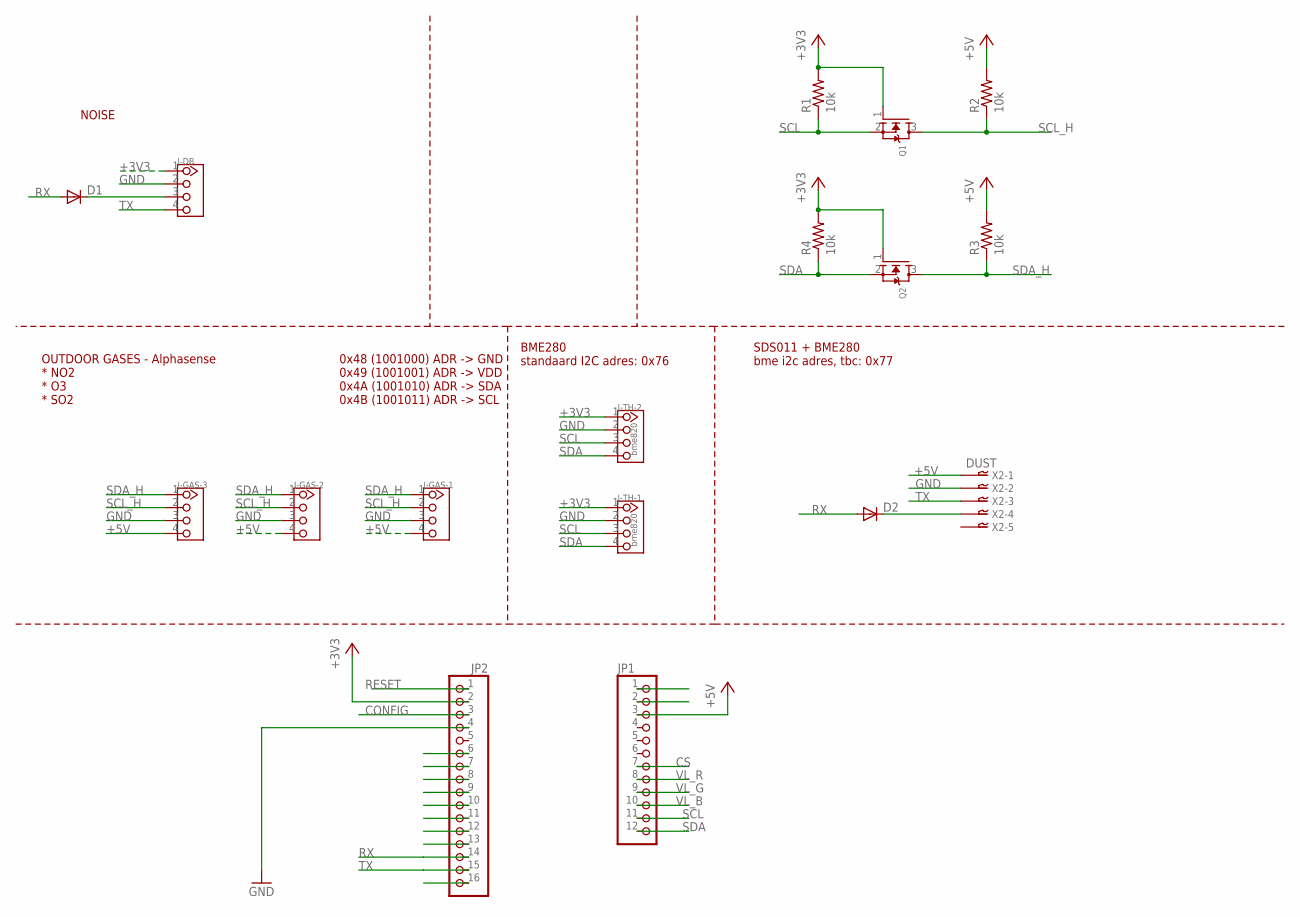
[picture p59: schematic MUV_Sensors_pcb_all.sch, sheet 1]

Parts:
D1, D2: DIODE-DO214AA; DO214AA
J-DB: TWIG-4P-2.0-2.0; 4P-2.0
J-GAS-1, J-GAS-2, J-GAS-3: TWIG-4P-2.0-2.0; 4P-2.0
J-TH-1, J-TH-2: bme820; 4P-2.0
JP1: HEADER-1X12OVAL; 1X12_OVAL
JP2: HEADER-1X16; 1X16_OVAL
Q1, Q2: MOSFET-NWIDE; SOT23-WIDE
R1, R2, R3, R4: 10k; 1206
X2: DUST; B5B-XH

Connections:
+3V3: J-DB.1, J-TH-1.1, J-TH-2.1, JP2.2, Q1.1 (G), Q2.1 (G), R1.2, R4.2
+5V: J-GAS-1.4, J-GAS-2.4, J-GAS-3.4, JP1.3, R2.2, R3.2, X2.P$1
CONFIG: JP2.3
CS: JP1.7
GND: J-DB.2, J-GAS-1.3, J-GAS-2.3, J-GAS-3.3, J-TH-1.2, J-TH-2.2, JP2.4, X2.P$2
unnamed: D1.C, J-DB.3
unnamed: D2.C, X2.P$4
RESET: JP2.1
RX: D1.A, D2.A, JP2.14
SCL: J-TH-1.3, J-TH-2.3, JP1.11, Q1.2 (S), R1.1
SCL_H: J-GAS-1.2, J-GAS-2.2, J-GAS-3.2, Q1.3 (D), R2.1
SDA: J-TH-1.4, J-TH-2.4, JP1.12, Q2.2 (S), R4.1
SDA_H: J-GAS-1.1, J-GAS-2.1, J-GAS-3.1, Q2.3 (D), R3.1
TX: J-DB.4, JP2.15, X2.P$3
VL_B: JP1.10
VL_G: JP1.9
VL_R: JP1.8

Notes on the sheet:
SDS011 + BME280 bme i2c adres, tbc: 0x77
BME280 standaard I2C adres: 0x76
OUTDOOR GASES - Alphasense * NO2 * O3 * SO2
0x48 (1001000) ADR -> GND 0x49 (1001001) ADR -> VDD 0x4A (1001010) ADR -> SDA 0x4B (1001011) ADR -> SCL
NOISE

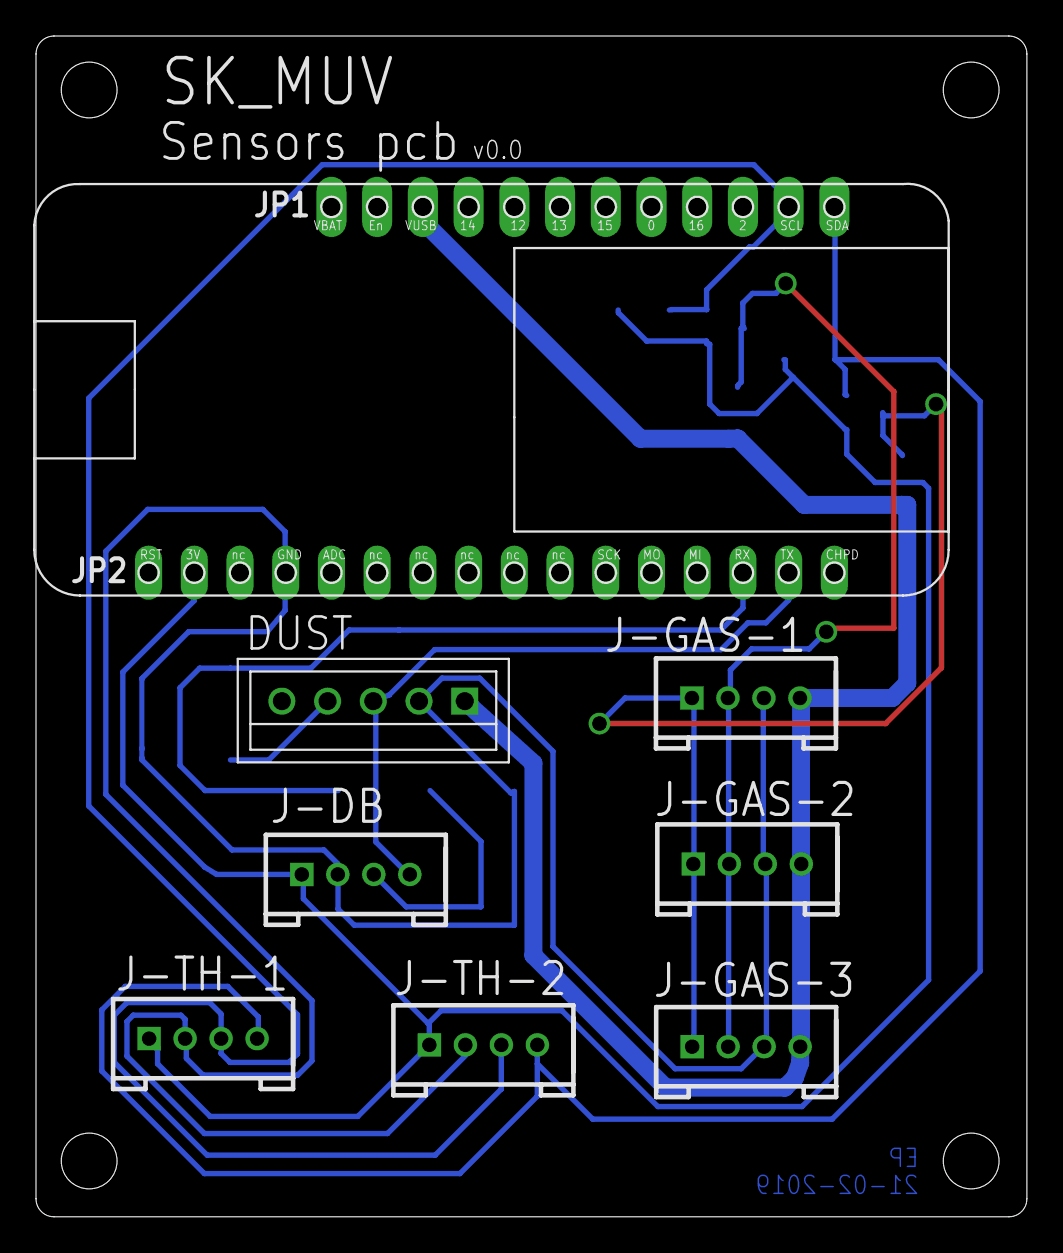
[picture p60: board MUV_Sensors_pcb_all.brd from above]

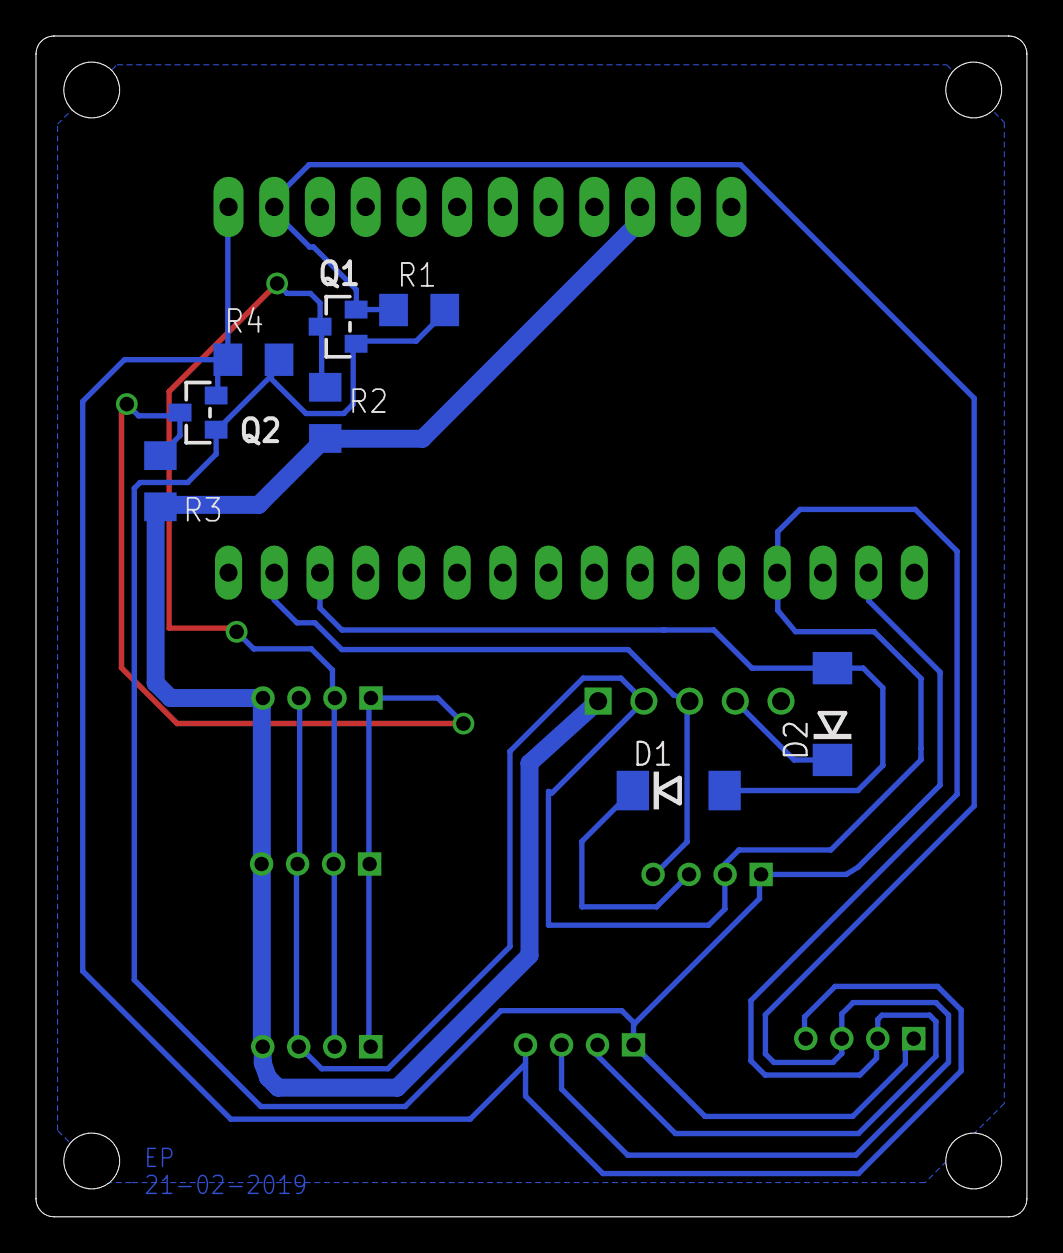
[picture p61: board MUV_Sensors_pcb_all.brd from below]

Board: 2 copper layers, 55.0 x 65.6 mm, 18 parts (8 on the bottom side), 11 nets.

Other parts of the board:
U1: ADA_FEATHER_HUZZAH_ESP8266_NOPADS

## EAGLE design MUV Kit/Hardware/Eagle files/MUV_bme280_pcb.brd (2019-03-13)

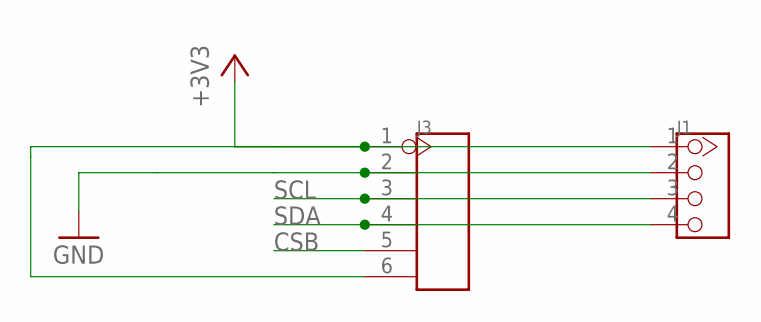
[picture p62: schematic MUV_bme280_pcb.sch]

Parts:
J1: TWIG-4P-2.0-2.0; 4P-2.0
J3: HEADER-6P-80/40MIL; 6P-2.54-80/40MIL

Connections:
+3V3: J1.1, J3.1, J3.6
CSB: J3.5
GND: J1.2, J3.2
SCL: J1.3, J3.3
SDA: J1.4, J3.4

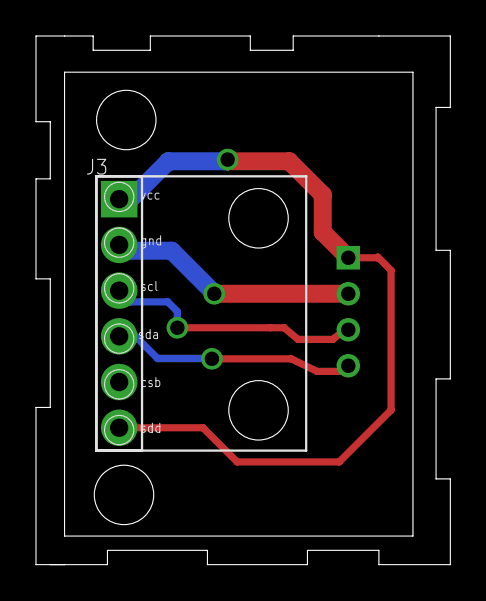
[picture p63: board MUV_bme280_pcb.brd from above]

Board: 2 copper layers, 23.0 x 29.4 mm, 3 parts (1 on the bottom side), 4 nets.

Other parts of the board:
U$1: BME280_BO_NOPADS

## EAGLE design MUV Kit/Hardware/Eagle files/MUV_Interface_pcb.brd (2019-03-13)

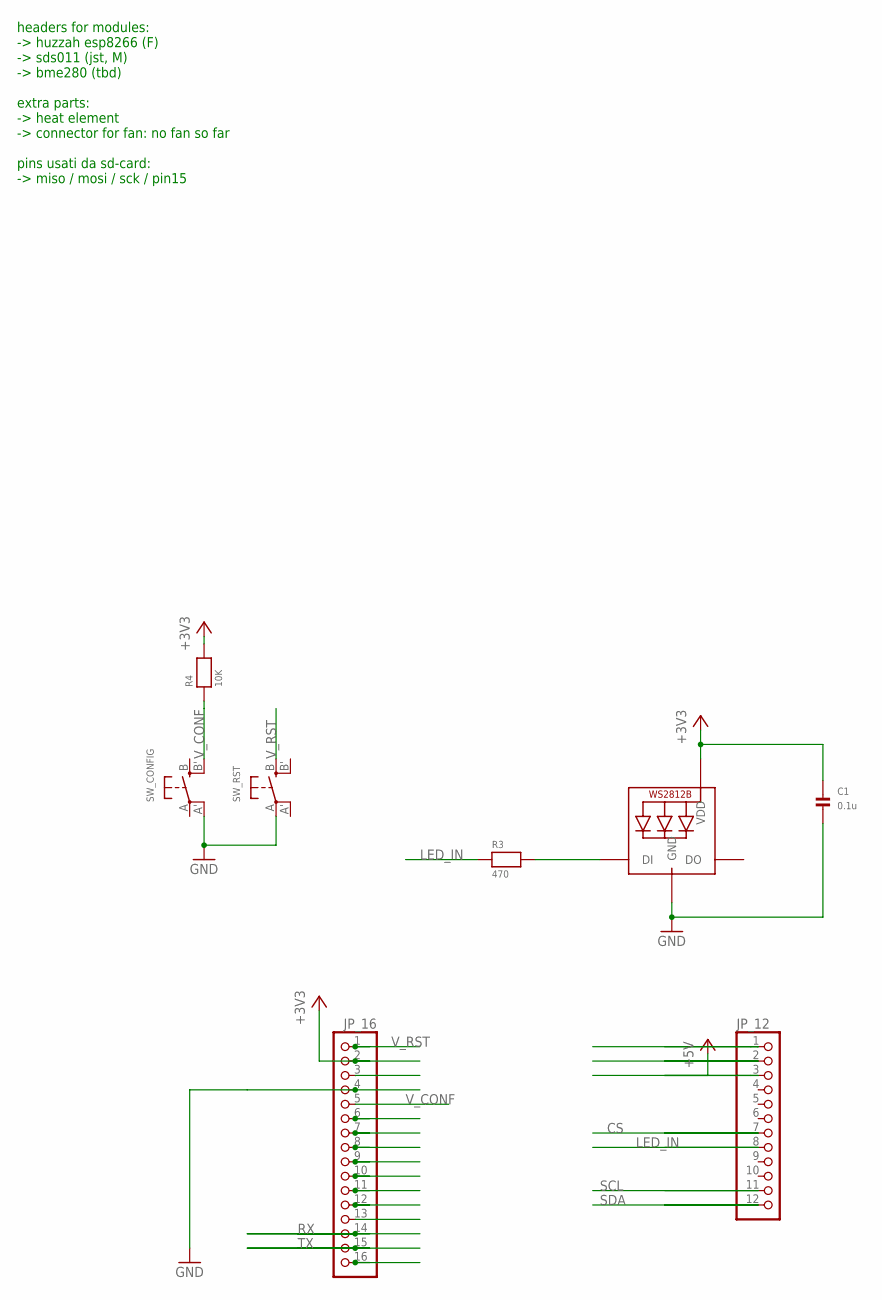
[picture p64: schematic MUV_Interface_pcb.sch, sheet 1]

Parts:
C1: 0.1u; 1206
JP_12: HEADER-1X12OVAL; 1X12_OVAL
JP_16: HEADER-1X16; 1X16_OVAL
LED1: WS2812B5050; WS2812B
R3: 470; 1206
R4: 10K; 1206
SW_CONFIG: SWITCH_TACT_SMT; EVQ-Q2
SW_RST: SWITCH_TACT_SMT; EVQ-Q2

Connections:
+3V3: C1.1, JP_16.2, LED1.1-VDD (VDD), R4.2
+5V: JP_12.3
CS: JP_12.7
GND: C1.2, JP_16.4, LED1.3-GND (GND), SW_CONFIG.A' (P1), SW_RST.A
LED_IN: JP_12.8, R3.1
unnamed: LED1.4-DIN (DI), R3.2
RX: JP_16.14
SCL: JP_12.11
SDA: JP_12.12
TX: JP_16.15
V_CONF: JP_16.5, R4.1, SW_CONFIG.B' (S1)
V_RST: JP_16.1, SW_RST.B (S)

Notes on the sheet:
headers for modules: -> huzzah esp8266 (F) -> sds011 (jst, M) -> bme280 (tbd) extra parts: -> heat element -> connector for fan: no fan so far pins usati da sd-card: -> miso / mosi / sck / pin15

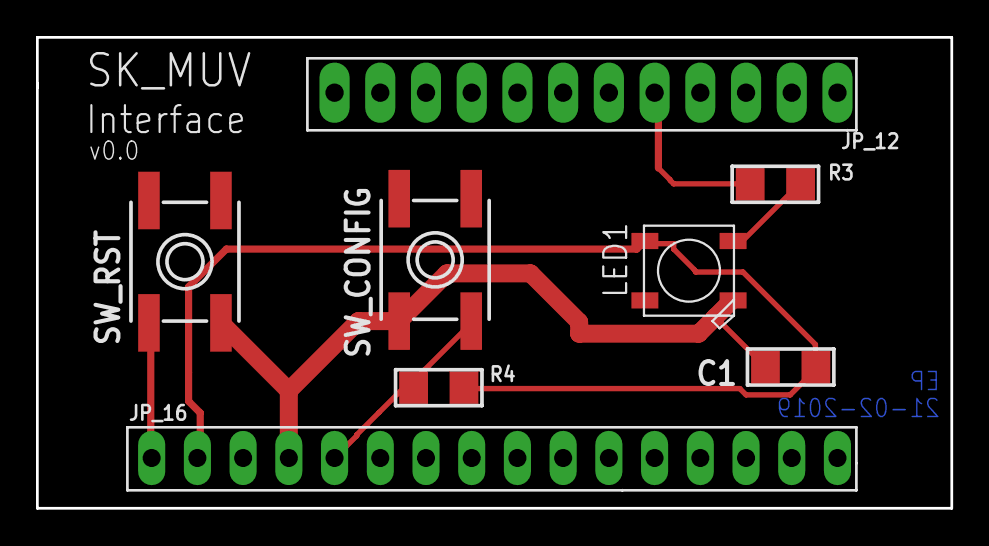
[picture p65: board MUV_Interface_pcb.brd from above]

Board: 2 copper layers, 50.8 x 26.2 mm, 8 parts (0 on the bottom side), 6 nets.

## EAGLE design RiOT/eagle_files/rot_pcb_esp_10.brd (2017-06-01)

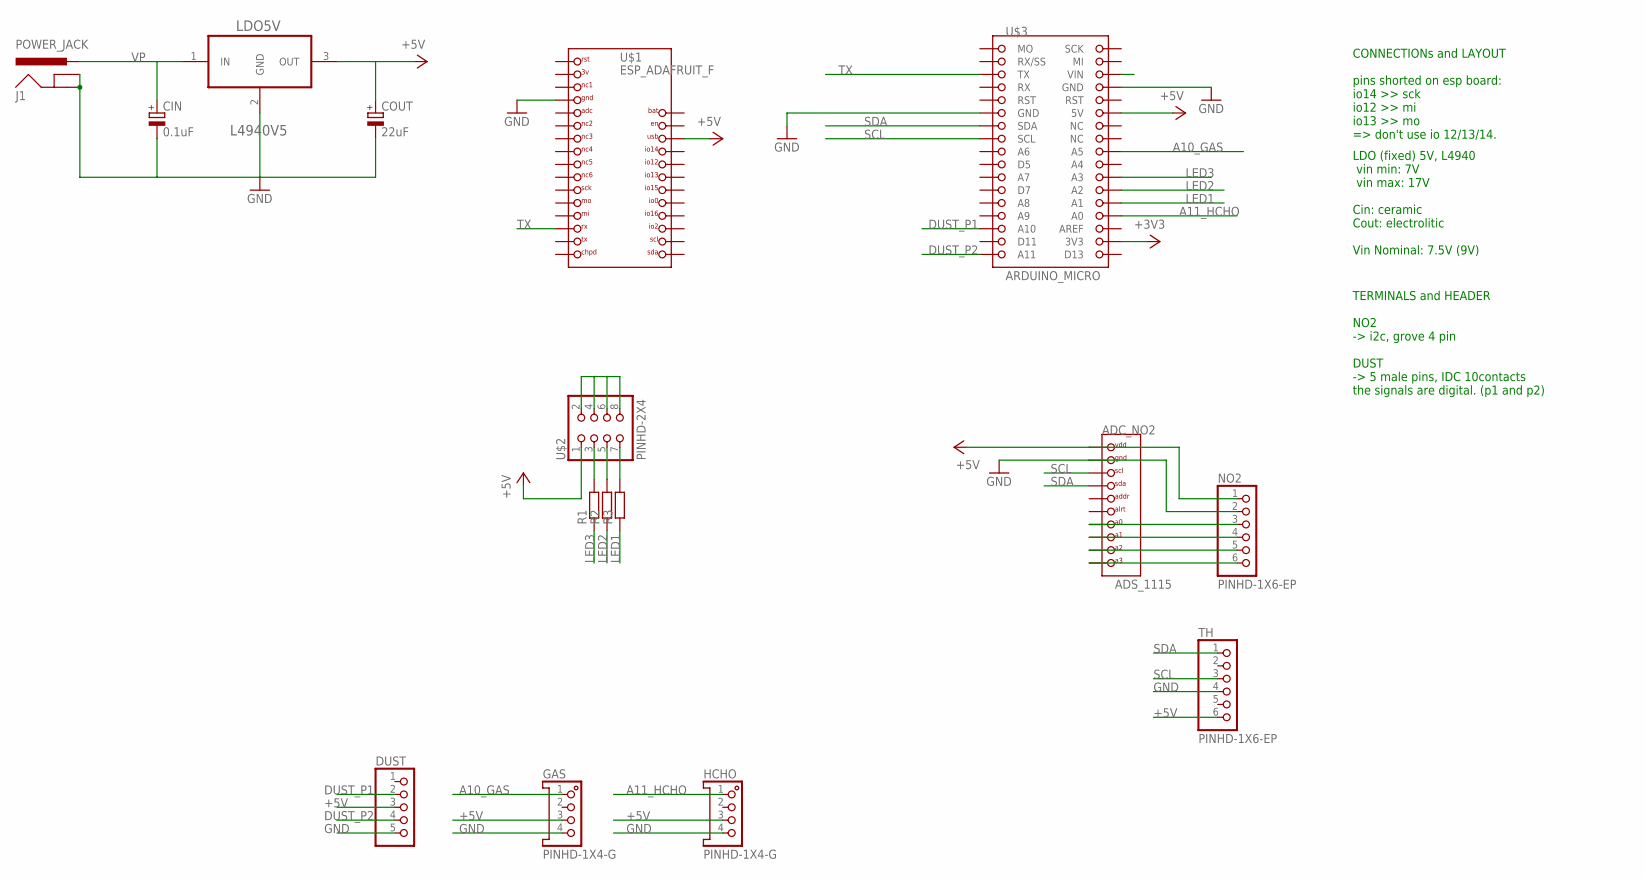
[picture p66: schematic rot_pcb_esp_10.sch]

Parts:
ADC_NO2: ADS_1115
CIN: 0.1uF; B45181B
COUT: 22uF; E2-5
DUST: PINHD-1X5; 1X5
GAS: PINHD-1X4-G; 1X4_G
HCHO: PINHD-1X4-G; 1X4_G
J1: POWER_JACK; POWER_JACK_PTH
LDO5V: L4940V5; TO254P482X1024X3124-3P
NO2: PINHD-1X6-EP; 1X6
R1, R2, R3: R-EU_0204/7; 0204/7
TH: PINHD-1X6-EP; 1X6
U$1: ESP_ADAFRUIT_F
U$2: PINHD-2X4; 2X4
U$3: ARDUINO_MICRO

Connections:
3V: U$1.3V
+3V3: U$3.3V3
+5V: ADC_NO2.VDD, COUT.+, DUST.3, GAS.3, HCHO.3, LDO5V.3 (OUT), NO2.1, TH.6, U$1.USB, U$2.1, U$3.5V
A4: U$3.A4
A10_GAS: GAS.1, U$3.A5
A11_HCHO: HCHO.1, U$3.A0
AREF: U$3.AREF
BAT: U$1.BAT
D13: U$3.D13
DUST_P1: DUST.2, U$3.A10
DUST_P2: DUST.4, U$3.A11
EN: U$1.EN
GND: ADC_NO2.GND, CIN.-, COUT.-, DUST.5, GAS.4, HCHO.4, J1.GND, J1.GNDBREAK, LDO5V.2 (GND), NO2.2, TH.4, U$1.GND, U$3.GND1 (GND), U$3.GND2 (GND)
LED1: R3.1, U$3.A1
LED2: R2.1, U$3.A2
LED3: R1.1, U$3.A3
MI: U$3.MI
unnamed: ADC_NO2.A3, NO2.6
unnamed: ADC_NO2.A2, NO2.5
unnamed: ADC_NO2.A1, NO2.4
unnamed: ADC_NO2.A0, NO2.3
unnamed: R1.2, U$2.3
unnamed: R2.2, U$2.5
unnamed: R3.2, U$2.7
unnamed: U$2.2, U$2.4, U$2.6, U$2.8
NC: U$3.NC1 (NC), U$3.NC2 (NC)
RST: U$3.RST2 (RST)
SCK: U$3.SCK
SCL: ADC_NO2.SCL, TH.3, U$3.SCL
SDA: ADC_NO2.SDA, TH.1, U$3.SDA
TX: U$1.RX, U$3.TX
VP: CIN.+, J1.PWR, LDO5V.1 (IN)

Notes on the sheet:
LDO (fixed) 5V, L4940 vin min: 7V vin max: 17V Cin: ceramic Cout: electrolitic Vin Nominal: 7.5V (9V)
CONNECTIONs and LAYOUT pins shorted on esp board: io14 >> sck io12 >> mi io13 >> mo => don't use io 12/13/14.
TERMINALS and HEADER NO2 -> i2c, grove 4 pin DUST -> 5 male pins, IDC 10contacts the signals are digital. (p1 and p2)

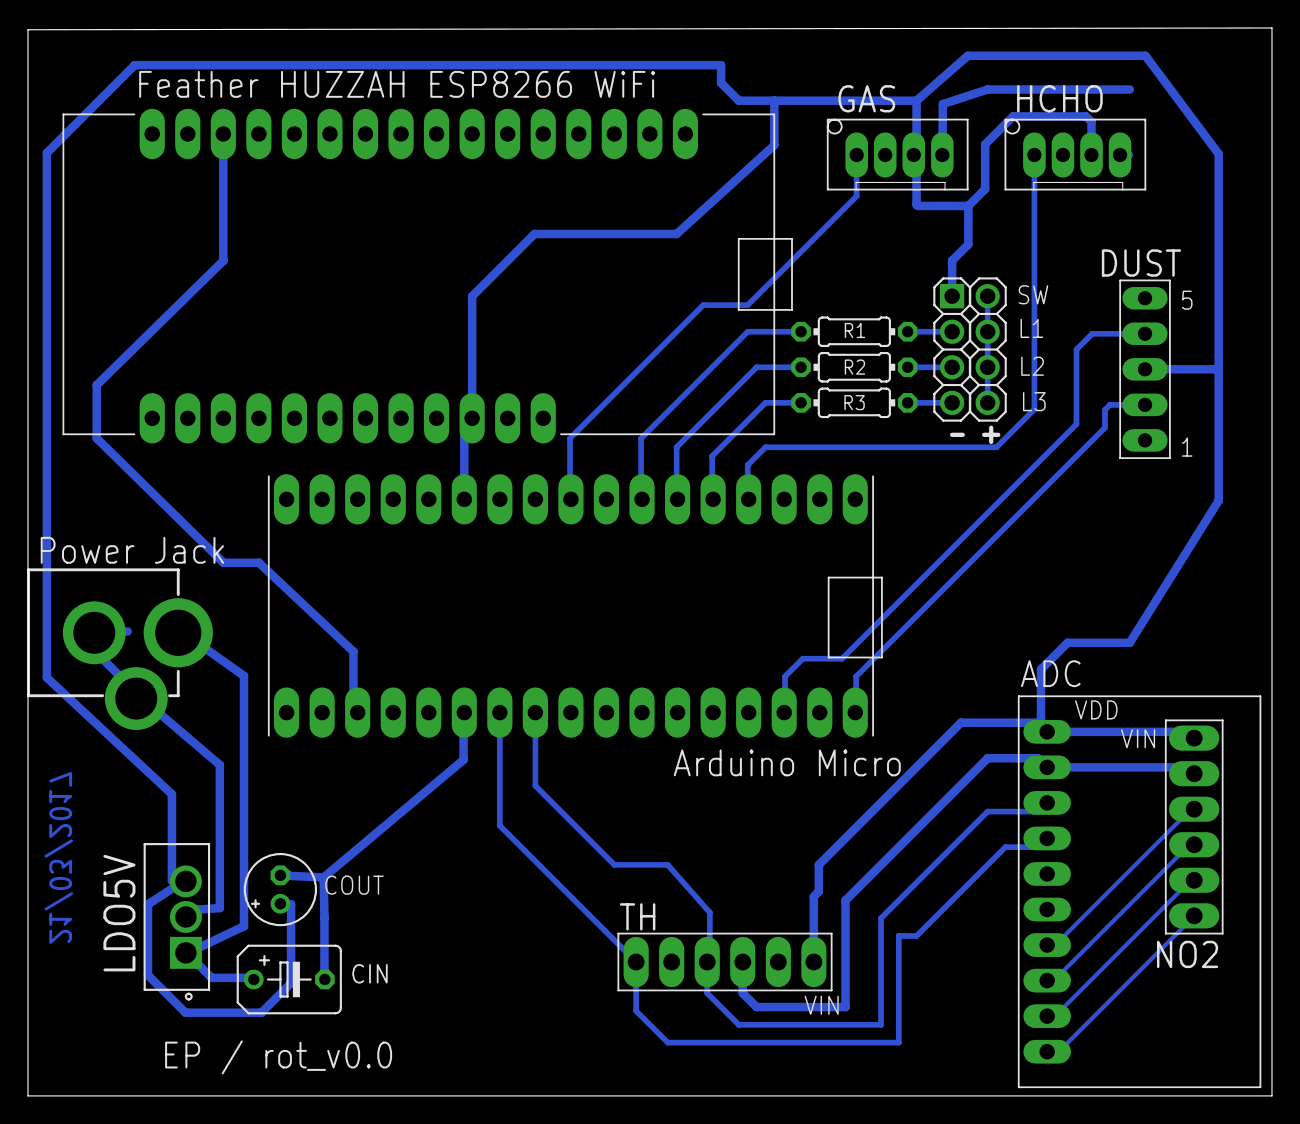
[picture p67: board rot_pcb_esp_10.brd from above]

Board: 1 copper layer, 88.9 x 76.3 mm, 16 parts (0 on the bottom side), 22 nets.

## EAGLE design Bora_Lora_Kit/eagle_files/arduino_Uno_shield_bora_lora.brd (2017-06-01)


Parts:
AD: 6x1F-H8.5; 1X06
IOH: 10x1F-H8.5; 1X10
IOL: 8x1F-H8.5; 1X08
LED2: LED3MM
POWER: 8x1F-H8.5; 1X08
R1, R2, R3, R4, R5: RESISTOR1206; 1206
U$1: RFM95W_ADAFRUIT
U$2: PINHD-2X2; 2X2
U$3: PINHD-2X5; 2X5

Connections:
+3V3: POWER.4
+5V: LED2.A, POWER.2, POWER.5, U$1.VIN, U$2.1, U$3.9
AD0: AD.1
AD1: AD.2
AD4: AD.5
AD4/SDA: IOH.9, U$3.5
AD5: AD.6
AD5/SCL: IOH.10, U$3.7
AREF: IOH.8
G1: R2.2, R3.1, U$1.G1
G2: R4.2, R5.1, U$1.G2
GND: IOH.7, POWER.6, POWER.7, R1.1, R2.1, R4.1, U$1.GND, U$2.3, U$3.3, U$3.4, U$3.6, U$3.8, U$3.10
IO0: IOL.1
IO1: IOL.2
IO4: IOL.5
IO5: IOL.6, R3.2
IO6: IOL.7, R5.2
IO7: IOL.8, U$1.G0
IO8: IOH.1
IO9: IOH.2, U$1.RST
IO10: IOH.3, U$1.CS
MISO: IOH.5, U$1.MISO
MOSI: IOH.4, U$1.MOSI
unnamed: LED2.K (C), R1.2
PM10: IOL.4, U$3.1
PM25: IOL.3, U$3.2
SCK: IOH.6, U$1.SCK
SDA_TH: AD.4, U$2.2
TH: AD.3
VIN: POWER.8

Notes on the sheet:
SDA
SCL
CONNECTION Suitble for the Adafruit breakout board Mapping breakout board - - arduino Uno RST - - IO5 CS - - 10 SCK - - 13 MOSI - - 11 MISO - - 12 G0 - - IO2 G1 - - IO3 G2 - - IO4


Board: 2 copper layers, 68.6 x 53.3 mm, 13 parts (0 on the bottom side), 18 nets.

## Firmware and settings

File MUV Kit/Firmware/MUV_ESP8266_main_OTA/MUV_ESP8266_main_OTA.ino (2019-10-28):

#ifndef MUV_ESP8266_MAIN_OTA
#define MUV_ESP8266_MAIN_OTA

/*
 * Author: Emma Pareschi
 * Date: March 2019
 * Project MUV
 * Code for Feather HUZZAH ESP8266
 * Version v0.1
 * 

 * Rewrite and additional features: 
 * - More robust Wifi connection and configuration
 * - OTA firmware update
 * - NTP synchronisation of the RTC
 * - Better error handling and logging to the SD card
 * - Removal of sound sensor support
 * Author: Dave Gönner
 * Date: Oktober 2019
 * Version v2.0
*/

#define FIRMWARE_VERSION "2.0-7"  // Increment this version number on every release! Crucial for the Over The Air software update to work properly. 

#define FS_NO_GLOBALS             //allow spiffs to coexist with SD card, define BEFORE including FS.h

#include <Arduino.h>
#include <stdarg.h>               // for the variable length arguments of the log function
#include <ESP8266WiFi.h>          // https://github.com/esp8266/Arduino
#include <ESP8266WebServer.h>     // part of the esp8266 core
#include <ESP8266httpUpdate.h>    // part of the esp8266 core
#include <DNSServer.h>            // part of the esp8266 core
#include <WiFiManager.h>          // https://github.com/tzapu/WiFiManager --- Version 0.14.0
#include <PubSubClient.h>         // https://github.com/knolleary/pubsubclient
#include <Adafruit_NeoPixel.h>    // https://github.com/adafruit/Adafruit_NeoPixel
#include <FS.h>                   // part of the esp8266 core, make sure ESP library 2.1.0 or higher is installed
#include <SD.h>                   // https://github.com/arduino-libraries/SD
#include <ArduinoJson.h>          // https://github.com/bblanchon/ArduinoJson (Version 6!)
#include <Wire.h>                 // part of Arduino core
#include <RTClib.h>               // https://github.com/adafruit/RTClib
#include <ezTime.h>               // https://github.com/ropg/ezTime
#include <Adafruit_Sensor.h>      // https://github.com/adafruit/Adafruit_Sensor
#include <Adafruit_BME280.h>      // https://github.com/adafruit/Adafruit_BME280_Library
#include <Adafruit_ADS1015.h>     // https://github.com/adafruit/Adafruit_ADS1X15

WiFiManager wifiManager;
WiFiClient espClient;
PubSubClient mqttClient(espClient);

// *** NEOPIXEL *** //
#define Pixel_pin 0               //Neopixel pin
#define LedConfig 0
byte brightness = 15;
Adafruit_NeoPixel pixels = Adafruit_NeoPixel(1, Pixel_pin, NEO_RGB + NEO_KHZ800);
uint32_t red = pixels.Color(200, 0, 0);
uint32_t green = pixels.Color(0, 255, 0);
uint32_t orange = pixels.Color(200,80,0);
uint32_t off = pixels.Color(0,0,0);
uint32_t aqua = pixels.Color(0,255,255);
uint32_t blue = pixels.Color(0,0,255);
uint32_t magenta = pixels.Color(255, 0, 255);

#define SwConfig_pin A0           // D0, button to enter wifi manager
bool shouldSaveConfig = false;    // flag for saving data

// *** SD CARD *** // 
int chipSelect = 15;             //chip select pin for the MicroSD Card Adapter
File file;                       // file object that is used to read and write data
char file_name[16];              // make it long enough to hold your longest file name, plus a null terminator


// This will be read from config on the SD-card
char mqtt_server[41];
char mqtt_portStr[21];
int mqtt_port;
char mqtt_username[21];
char mqtt_password[128];
char mqtt_topic[21];
char street_address[41];
char firmware_server[41];
char firmware_portStr[6];
int firmware_port;
char firmware_path[41];

// *** SENSORS *** //
// this will be read from config on the SD-card
boolean NO2  = false;
boolean O3 = false;
boolean BME = false;

// *** RTC *** //
RTC_PCF8523 rtc;
String timestamp;

// *** SDS011 Particulate sensor *** //
unsigned int Pm25 = 0;
unsigned int Pm10 = 0;
int  Status_sds = -1;
int LastError_sds = 0;
float p10 = -1.0;
float p25 = -1.0;
int ecnt = 0;

// *** BME280 *** //
#define SEALEVELPRESSURE_HPA (1013.25)
Adafruit_BME280 bme; // I2C
float temp = 0;
float hum = 0;
float pres = 0;

// *** NO2 and O3 gas *** //
Adafruit_ADS1115 ads;  /* Use this for the 16-bit version */
Adafruit_ADS1115 ads_o3(0x4A);
int op1 = 0;
int op2 = 0;
int op1_sum =0;
int op2_sum =0;
int op1_avg =0;
int op2_avg =0;
int gas_count =0;
int o3_op1 = 0;
int o3_op2 = 0;
int o3_op1_sum =0;
int o3_op2_sum =0;
int o3_op1_avg =0;
int o3_op2_avg =0;

long chipid;

// logging functionality
boolean log_to_sd;
boolean log_to_serial;

//enum loglevel{ LOG_INFO, LOG_WARN, LOG_ERR }; 

// *** general *** //
boolean collect_data_sensors = false;
uint8_t status_publish = 0;
boolean status_write = 0;


//==== FUNCTIONS ===============================================================
void log(const char *format, ...);  // just the prototype, declaration will be further down below


void setPixel(uint32_t color) {
  pixels.setPixelColor(LedConfig, color);
  pixels.show();  
}


// Get the current time from the RTC and form a timestamp from it.
String get_rtc_data_time() {
  DateTime now = rtc.now();
  return now.timestamp();
}


void setup_sd_card() {
  // ************************** INITIALIZE CARD ** //
  pinMode(chipSelect, OUTPUT); // chip select pin must be set to OUTPUT mode
  if (!SD.begin(chipSelect)) { // Initialize SD card
    log("%s", "[E] Could not initialize SD card"); // if return value is false, something went wrong.
    return;    
  } else {
    log("%s", "[i] SD card initialized");   
  }

  int n = 0;
  snprintf(file_name, sizeof(file_name), "data%03d.txt", n); // includes a three-digit sequence number in the file name
  
  while(SD.exists(file_name)) {
    n++;
    snprintf(file_name, sizeof(file_name), "data%03d.txt", n);
  }

  log("%s %s", "[i] File name:", file_name); 

  // ** Write Log File Header 
  file = SD.open(file_name, FILE_WRITE); // open "file.txt" to write data
  if (file) {
    file.println(" "); //Just a leading blank line, in case there was previous data
    const char *header = "ID,TimeStamp,Temp,Hum,Press,P2.5,PM10,NO2op1,NO2op2,O3op1,O3op2,Noise(SPLdB)\0";
    file.println(header);
    file.close();
    log("%s %s", "Header:", header);
  } else {
    log("%s", "[E] Couldn't open log file");
  }
}


// save the currently collected sensor readings to a file on the sd-card.
void log_sd_card(char * buffer) {
  // ** Write Log File Header 
  file = SD.open("log.txt", FILE_WRITE); // open file to write data
  if (file) {
    file.println(buffer);
    file.close();
  } else {
    Serial.println("Couldn't open log file");
  }
}


void log(const char *format, ...) {
  char buffer[256];
  va_list args;
  va_start ( args, format );           
  vsprintf (buffer,format, args);

  if (log_to_serial) {
    Serial.println(buffer);
  }
  if (log_to_sd) {
    char sd_buffer[256];
    char data_time[20];
    get_rtc_data_time().toCharArray(data_time, 20);
    snprintf(sd_buffer, 256, "%s %s", data_time, buffer);
    log_sd_card(sd_buffer);
  }
}


void setupMQTT() {
  mqttClient.setServer(mqtt_server, mqtt_port);  
  char mqtt_clientid[15];
  snprintf (mqtt_clientid, 14, "ESP%lu", chipid);
  if (!mqttClient.connect(mqtt_clientid, mqtt_username, mqtt_password)) {         
    log("%s", "[i] Connecting to MQTT");        

    while (!mqttClient.connect(mqtt_clientid, mqtt_username, mqtt_password)) {    
      setPixel(magenta);
      delay(500);
      Serial.print(".");
      setPixel(off);
      delay(500);     
    } 
  } else { 
    log("%s", "[i] MQTT connected"); 
    setPixel(magenta);
  }  
}


//function that send the MQTT startup message
void send_mqtt_startup_message() {
  log("%s", "[i] Trying to send MQTT startup message");

  String timeString = get_rtc_data_time();
  char mqtt_clientid[15];
  snprintf (mqtt_clientid, 14, "ESP%lu", chipid);

  if (mqttClient.connect(mqtt_clientid, mqtt_username, mqtt_password)) {
    long rssi = WiFi.RSSI(); 

    // send proper JSON startup message
    DynamicJsonDocument json(1024);
    json["message"] = "startup";
    json["id"] = chipid;
    json["ts"] = timeString;
    json["location"] = street_address;
    json["rssi"] = rssi;     
    char buf[110];
    serializeJson(json, buf, sizeof(buf));

    log("%s %s", "[i] Publish message: ", buf);
    char topic_buf[50];
    sprintf(topic_buf, mqtt_topic, chipid);
    mqttClient.publish(topic_buf, buf);
  } else {
    log("%s", "[E] Failed to send, MQTT not connected");
  }
}


void setupRTC() {
  log("%s", "[i] Initialising RTC");
  
  if (! rtc.begin()) {
    log("%s", "[E] Couldn't find RTC");
    while (1);
  } else {
    log("%s", "[i] RTC ready ");
  }

  if (!rtc.initialized()) {
    log("%s", "[E] RTC is NOT running!");
    // following line sets the RTC to the date & time this sketch was compiled
     rtc.adjust(DateTime(F(__DATE__), F(__TIME__)));
     delay(5);
  }  

  char data_time[20];
  get_rtc_data_time().toCharArray(data_time, 20);
  log("%s", data_time);
}


// ------------ NTP ----------------------
void setupNTP() {
  log("%s", "[i] Waiting for NTP sync");
  waitForSync();
  char date_time[40];
  UTC.dateTime().toCharArray(date_time, 40);
  log("UTC: %s", date_time );
  rtc.adjust(DateTime(now()));
}


//  This function is called when the Wifi configuration manager is started
void configModeCallback (WiFiManager *myWiFiManager) {
  log("%s", "[i] Entered WiFi config mode");

  char ip_buffer[16];
  WiFi.softAPIP().toString().toCharArray(ip_buffer, 16);
  log("%s", ip_buffer);
  
  char ssid_buffer[50];
  myWiFiManager->getConfigPortalSSID().toCharArray(ssid_buffer, 50);
  log("%s", ssid_buffer);
  setPixel(blue);
}


//callback notifying us of the need to save config
void saveConfigCallback () {
  log("%s", "[i] Should save WiFi config");
  shouldSaveConfig = true;
}

// Save the config variables to the SD-card
void saveConfigJsonSD() {
  log("%s", "[i] Saving config to SD-card");
  if (SD.exists("config.json")) {
    log("%s", "[i] Delete existing config.json");
    SD.remove("config.json");
  }
  File config_file = SD.open("config.json", FILE_WRITE); // creating new config file for writing
  if (config_file) {
    log("%s", "[i] config.json opened");

    DynamicJsonDocument json(1024);
    json["mqtt_server"] = mqtt_server;
    json["mqtt_port"] = mqtt_portStr;
    json["mqtt_username"] = mqtt_username;
    json["mqtt_password"] = mqtt_password;
    json["mqtt_topic"] = mqtt_topic;
    json["address"] = street_address;
    json["firmware_server"] = firmware_server;
    json["firmware_port"] = firmware_portStr;
    json["firmware_path"] = firmware_path;
    if (NO2) { json["sensor_no2"] = "True"; } else { json["sensor_no2"] = "False"; }  
    if (O3) { json["sensor_o3"] = "True"; } else { json["sensor_o3"] = "False"; }  
    if (BME) { json["sensor_bme"] = "True"; } else { json["sensor_bme"] = "False"; }  

    serializeJson(json, Serial);
    Serial.println();
    serializeJson(json, config_file);
    config_file.close();
    log("%s", "[i] config.json written succesfully");
  } else {
    log("%s", "[E] Failed to open config.json file for writing");
  }
}


// Read temperature an humidity values from the BME280 sensor and 
// store in the global temp, hum and pres variables.
void data_bme() {
  temp = 0.00;
  hum = 0.00;
  pres = 0.00;

  if(BME){ 
    temp = bme.readTemperature();
    hum = bme.readHumidity();
    pres = bme.readPressure() / 100.0F;

    temp = round(temp*100);
    temp = temp/100;

    hum = round(hum*100);
    hum = hum/100;

    pres = round(pres*100);
    pres= pres/100;
  }
}


// Read PM25 and PM10 values from the SDS sensor 
// and store in the global p25 and p10 variables.
void data_sds(){
  uint8_t mData = 0;
  uint8_t i = 0;
  uint8_t mPkt[10] = {0};
  uint8_t mCheck = 0;

  Status_sds = -1;  // Default: no data availabe ...
  p10 = -1.0;
  p25 = -1.0;

  while (Serial.available() > 0) {
    // from www.inovafitness.com
    // packet format: AA C0 PM25_Low PM25_High PM10_Low PM10_High 0 0 CRC AB

    Status_sds = 0; // There is data!

    mData = Serial.read();
    delay(10);//wait until packet is received

    if (mData == 0xAA) {  // Head1 ok?
      mPkt[0] =  mData;
      mData = Serial.read();

      if (mData == 0xc0) {  // Head2 ok?
        mPkt[1] =  mData;
        mCheck = 0;
        for (i = 0; i < 6; i++) {  // Get the content of the package!
          mPkt[i + 2] = Serial.read();
          delay(2);
          mCheck += mPkt[i + 2];
        }

        mPkt[8] = Serial.read();
        delay(5);

        mPkt[9] = Serial.read();
        if (mPkt[9] != 0xAB) {
          log("%s %X", "[W] mData[9] != 0xAB,  but ", mPkt[9]);
          Status_sds = 4; LastError_sds = Status_sds; ecnt++;
        }

        if (mCheck == mPkt[8]) {  // Check CRC
          Serial.flush();
          //Serial.write(mPkt,10);

          Pm25 = (uint16_t)mPkt[2] | (uint16_t)(mPkt[3] << 8);
          Pm10 = (uint16_t)mPkt[4] | (uint16_t)(mPkt[5] << 8);

          if (Pm25 > 9999)
            Pm25 = 9999;
          if (Pm10 > 9999)
            Pm10 = 9999;

          p25 = Pm25 / 10.0;
          p10 = Pm10 / 10.0;

          while (Serial.available() > 0) {  // Zap buffer ...
            mData = Serial.read();
          }

          return;  // We now have one good packet :-))

        } else {  // CRC ??
          log("%s %X %s %X", "[i] CRC != OK, ", mCheck, "  !=  ", mPkt[8]);
          Status_sds = 3; LastError_sds = Status_sds; ecnt++;
        }
      } else {  // Head2 ??
        log("%s %X", "[W] mData != 0xc0,  but ", mData);
        Status_sds = 2; LastError_sds = Status_sds; ecnt++;
      }
    } else {  // Head1 ??
      log("%s %X", "[W] mData != 0xAA,  but ", mData);
      Status_sds = 1; LastError_sds = Status_sds; ecnt++;
    }
  }
}


// read the values from the NO2 and O3 gas sensors 
// and store in the global op1, op2, o3_op1 and o3_op2 variables.
void data_gas1(){
  if(NO2) {
    op1 = ads.readADC_Differential_0_1();
    op2 = ads.readADC_Differential_2_3();
  } else {
    op1 = 0;
    op2 = 0;
  }
    
  if(O3) {
    o3_op1 = ads_o3.readADC_Differential_0_1();
    o3_op2 = ads_o3.readADC_Differential_2_3();
  } else {
    o3_op1 = 0;
    o3_op2 = 0;
  }
}


void setup_BME() {
  // BME280 
  bool status;   
  log("%s", "[i] Starting BME280 sensor");  
  status = bme.begin();  
  if (!status) {
    log("%s", "[E] Could not find a valid BME280 sensor, check wiring!");
  } else {
    log("%s", "[i] BME280 sensor is OK");
  }
}


void setup_gas() {
  // ADS1115 converters for NO2 and O3 sensors
  log("%s", "[i] Starting ADS converters");  
  ads.begin();
  ads_o3.begin();
}


void setup_Wifi(){
  wifiManager.setAPCallback(configModeCallback);
  wifiManager.setSaveConfigCallback(saveConfigCallback);
    
  boolean startConfigPortal = false;
  
  if ( analogRead(SwConfig_pin) <= 500 ) {
    startConfigPortal = true;
  }

  if (startConfigPortal) {
    WiFiManagerParameter custom_address("address", "address", "insert address", 41);
    wifiManager.addParameter(&custom_address);
    wifiManager.startConfigPortal("MUV_air");
    
    if (shouldSaveConfig) {
      //save the config
      log("%s", "[i] Saving new wifi config");

      mqtt_port = atoi(mqtt_portStr);
      strcpy(street_address, custom_address.getValue());
      saveConfigJsonSD();

      shouldSaveConfig = false;
      setPixel(off);
    }
  }

  WiFi.mode(WIFI_STA);
  if (WiFi.SSID()) {
    log("%s", "[i] Using saved WiFi credentials");
    WiFi.begin();
    char ssid_buffer[50];
    WiFi.SSID().toCharArray(ssid_buffer,50);
    log("[i] WiFi SSID: %s", ssid_buffer);
    char pass_buffer[50];
    WiFi.psk().toCharArray(pass_buffer, 50);
    log("[i] WiFi Password: %s", pass_buffer);

    uint8_t wifi_status = WiFi.status();
    while (wifi_status != WL_CONNECTED) {
      setPixel(red);
      delay(500);
      Serial.print(".");
      setPixel(off);
      delay(500);
      if (wifi_status == WL_CONNECT_FAILED) {
        log("%s", "[E] Wifi password incorrect");
      }
      if (wifi_status == WL_NO_SSID_AVAIL) {
        log("%s", "[E] Wifi SSID can not be reached");
      }
      wifi_status = WiFi.status();
    }
  } else {
    log("%s", "[W] No saved credentials");
    startConfigPortal = true;
  }

  WiFi.waitForConnectResult();
  if (WiFi.status() != WL_CONNECTED) {
    log("%s", "[E] Failed to connect Wifi");
    startConfigPortal = true;
  } else { 
    pixels.setPixelColor(LedConfig, green);
    pixels.show();
  }

  WiFi.printDiag(Serial);
  log("%s", "[i] Wifi connected");
  // End wifi section, from here on we are connected 
}


void check_firmware_update() {
  log("%s", "[i] Checking for newer firmware");
  ESPhttpUpdate.rebootOnUpdate(false);
  t_httpUpdate_return ret = ESPhttpUpdate.update(espClient, firmware_server, firmware_port, firmware_path, FIRMWARE_VERSION);

  switch(ret) {
    case HTTP_UPDATE_OK:
        log("%s", "[i] Firmware update OK"); // may not be called since we reboot the ESP
        delay(500);
        ESP.reset();
        break;
    case HTTP_UPDATE_NO_UPDATES:
        log("%s", "[i] Firmware already at latest");
        break;
    case HTTP_UPDATE_FAILED:
        log("%s", "[E] Firmware update failed");
        break;
  }
}

void read_config_from_SD() {
  //read config.json from SD card
  log("%s", "[i] Opening config.json");

  if (SD.exists("config.json")) {
    File config_file = SD.open("config.json", FILE_READ); // open the config file for reading
    if (config_file) {
      log("%s", "[i] Reading config.json file");
      DynamicJsonDocument json(1024);
      DeserializationError error = deserializeJson(json, config_file);
      serializeJson(json, Serial);  //print the content of json object on serial.
      Serial.println();

      if (!error) {
        log("%s", "[i] Parsed json, from config.json");
        strcpy(mqtt_server, json["mqtt_server"]);
        strcpy(mqtt_portStr, json["mqtt_port"]);
        mqtt_port = atoi(mqtt_portStr);
        strcpy(mqtt_username, json["mqtt_username"]);
        strcpy(mqtt_password, json["mqtt_password"]);
        strcpy(mqtt_topic, json["mqtt_topic"]);
        strcpy(street_address, json["address"]);
        strcpy(firmware_server, json["firmware_server"]);
        strcpy(firmware_portStr, json["firmware_port"]);
        firmware_port = atoi(firmware_portStr);
        strcpy(firmware_path, json["firmware_path"]);

        String no2Str = json["sensor_no2"];
        no2Str.toLowerCase();
        if (no2Str.equals("true")) { NO2 = true; } else { NO2 = false; }

        String o3Str = json["sensor_o3"];
        o3Str.toLowerCase();
        if (o3Str.equals("true")) { O3 = true; } else { O3 = false; }

        String bmeStr = json["sensor_bme"];
        bmeStr.toLowerCase();
        if (bmeStr.equals("true")) { BME = true; } else { BME = false; }

      } else {
        log("%s", "[E] Failed to parse config.json");
      }

      config_file.close();
    } else {
      log("%s", "[E] Can't open config.json");
    }
  } else {
    log("%s", "[E] No config.json on SD card");
  }
}
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
void loop() {
  mqttClient.loop();

  data_sds();  //check sds data

  //are there good data?
  if (p25 > -1.0 && p10 > -1.0) {
    collect_data_sensors = true;    //if there are data => flag collect data
    gas_count = ecnt;
    ecnt =0;
  } else {
    ecnt++;
    data_gas1();          //continuosly read the gases
    op1_sum += op1;       //sum the readings of NO2
    op2_sum += op2;
    o3_op1_sum += o3_op1;       //sum the readings of O3
    o3_op2_sum += o3_op2;
  }

  if (collect_data_sensors){

    status_publish = 0;     //before sending, clean the status publish flag

    Serial.println("");
    timestamp = get_rtc_data_time();         //get the timestamp
    Serial.print("Timestamp : "); Serial.println(timestamp);
    
    Serial.print("PM2.5 : "); Serial.println(p25);
    Serial.print("PM10 : "); Serial.println(p10);
       
    if (BME) {    
      data_bme();                             //get temp/hum/pres
      Serial.print("Temperaure (C) : "); Serial.println(temp);
      Serial.print("Humidity (%) : "); Serial.println(hum);
      Serial.print("Pressure (hPa) : "); Serial.println(pres);
    }  

    if (NO2) {
      op1_avg = op1_sum/gas_count;            //average the op1
      op2_avg = op2_sum/gas_count;            //average the op2
      Serial.print("NO2 op1 avg : "); Serial.println(op1_avg);
      Serial.print("NO2 op2 avg : "); Serial.println(op2_avg);
    }  

    if (O3) {
      o3_op1_avg = o3_op1_sum/gas_count;            //average the op1
      o3_op2_avg = o3_op2_sum/gas_count;            //average the op2
      Serial.print("O3 op1 avg : "); Serial.println(o3_op1_avg);
      Serial.print("O3 op2 avg : "); Serial.println(o3_op2_avg);
    }  

    Serial.println();

    send_mqtt_payload();  //send payload

    //if the publish was success => blink green
    if(status_publish == 1){
      log("%s", "[i] The payload reached the server");
      setPixel(green);
      delay(100);
      setPixel(off);
    } else {
      setPixel(orange);
      delay(1);
      save_data_sdcard(); //if the publish not good => save in sd card
    }

    //if it was possible to open the file => blink orange
    if(status_write == true && status_publish == 0){
      log("%s", "[W] The payload saved on sd-card");
      setPixel(off);
      delay(100);
      setPixel(orange);
    } else if (status_write == false && status_publish == 0) { //if there is not card => Led orange and stays red until the next try
      setPixel(red);
    }
    
    op1_avg =0;
    op2_avg =0;
    op1_sum=0;
    op2_sum=0;
    o3_op1_avg =0;
    o3_op2_avg =0;
    o3_op1_sum=0;
    o3_op2_sum=0;
    
    gas_count = ecnt;
    collect_data_sensors = false;         //un-flag collect data
  }

  Serial.print(get_rtc_data_time()+" "); Serial.print("ECOUNT: "); Serial.println(ecnt); 

  #ifdef DO_DEBUG
    Serial.print("\tECOUNT= "); Serial.println(ecnt); 
    Serial.print("\tNO2 op1= "); Serial.print(op1);  
    Serial.print("\tNO2 op2= "); Serial.print(op2);
    Serial.print("\tO3 op1= "); Serial.print(o3_op1);  
    Serial.print("\tO3 op2= "); Serial.println(o3_op2);
  #endif
    
  delay(1000);
}

#endif

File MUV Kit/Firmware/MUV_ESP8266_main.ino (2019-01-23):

/*
 * Author: Emma Pareschi
 * Date: Janury 23 2019
 * Project MUV
 * Code for Feather HUZZAH ESP8266
 * 
*/

#define FS_NO_GLOBALS
#include <FS.h>                   // Make sure ESP library 2.1.0 or higher is installed
#include <ESP8266WiFi.h>          //https://github.com/esp8266/Arduino
#include <DNSServer.h>
#include <ESP8266WebServer.h>
#include <WiFiManager.h>          //https://github.com/tzapu/WiFiManager
#include <ArduinoJson.h>          //https://github.com/bblanchon/ArduinoJson
#include <PubSubClient.h>         //https://github.com/knolleary/pubsubclient

#include <SD.h> //Load SD library
#include <SoftwareSerial.h>
#include <Wire.h> //include Wire.h library
#include "RTClib.h" //include Adafruit RTC library

#include <Adafruit_Sensor.h>
#include <Adafruit_BME280.h>

#include <Adafruit_ADS1015.h>

  char mqtt_server[41] = "<my_server>\0";<br>
  char mqtt_portStr[21] = "<my_port>\0";<br>
  char mqtt_username[21] = "<my_username>\0";<br>
  char mqtt_password[128] = "<my_password>\0";<br>
  char mqtt_topic[21] = "<my_topic>\0";<br>
  char address[41] = "insert address\0";

String location = "";

int mqtt_port = atoi(mqtt_portStr);

#define SwConfig_pin A0              // D0, button to enter wifi manager
boolean SwConfig_state = 1;         // current state of the button
boolean lastSwConfig_state = 1;     // previous state of the button

WiFiManager wifiManager;
WiFiClient espClient;
PubSubClient mqttClient(espClient);

long chipid;
bool shouldSaveConfig = false;    //flag for saving data

// for Neopixel
#include <Adafruit_NeoPixel.h>

#define Pixel_pin            0 //Neopixel pin
#define LedConfig 0

byte brightness = 50;

Adafruit_NeoPixel pixels = Adafruit_NeoPixel(1, Pixel_pin, NEO_GRB + NEO_KHZ800);

uint32_t red = pixels.Color(255, 0, 0);
uint32_t green = pixels.Color(0, 255, 0);
uint32_t orange = pixels.Color(255,100,0);
uint32_t off = pixels.Color(0,0,0);
uint32_t aqua = pixels.Color(0,255,255);
uint32_t blue = pixels.Color(0,0,255);
uint32_t magenta = pixels.Color(255, 0, 255);

// *** SD CARD *** // 
 int chipSelect = 15; //chip select pin for the MicroSD Card Adapter
 File file; // file object that is used to read and write data
 char file_name[16]; // make it long enough to hold your longest file name, plus a null terminator

// *** RTC *** //
 RTC_PCF8523 rtc;
 String timestamp;


// *** BME *** //
#define SEALEVELPRESSURE_HPA (1013.25)
Adafruit_BME280 bme; // I2C

float temp = 0;
float hum = 0;
float pres = 0;


// *** SDS011 *** //
unsigned int Pm25 = 0;
unsigned int Pm10 = 0;
int  Status_sds = -1;
int LastError_sds = 0;
float p10 = -1.0;
float p25 = -1.0;
int ecnt = 0;


// *** NO2 gas *** //
 Adafruit_ADS1115 ads;  /* Use this for the 16-bit version */

 int op1 = 0;
 int op2 = 0;
 int op1_sum =0;
 int op2_sum =0;
 int op1_avg =0;
 int op2_avg =0;
 int gas_count =0;



// *** NOISE *** //
long noise_dB = 0;
int request_ok = 0;
String readStr;
char c;
int start_time_noise = 0;
int noise_flag = 0;


// *** general *** //
boolean collect_data_sensors = false;
uint8_t status_publish = 0;
boolean status_write = 0;

#define DEBUG 1

//callback notifying us of the need to save config
void saveConfigCallback () {
  Serial.println("Should save config");
  shouldSaveConfig = true;
}

void saveConfigJson() {
  //save the custom parameters to FS
  Serial.println("saving config");
  DynamicJsonBuffer jsonBuffer;
  JsonObject& json = jsonBuffer.createObject();
  json["mqtt_server"] = mqtt_server;
  json["mqtt_port"] = mqtt_portStr;
  json["mqtt_username"] = mqtt_username;
  json["mqtt_password"] = mqtt_password;
  json["mqtt_topic"] = mqtt_topic;
  json["address"] = address;

  fs::File configFile = SPIFFS.open("/config.json", "w");
  if (!configFile) {
    Serial.println("failed to open config file for writing");
  }

  json.printTo(Serial);
  Serial.println("\n");
  json.printTo(configFile);
  configFile.close();
  //end save
}


void setup() {
 
 Serial.begin(9600);
 
  //--------------------------------------------
//  //Format FS, reset Wifi settings, for testing
//  Serial.print("Formatting FS...");
//  SPIFFS.format();
//  Serial.println("Done.");
//  Serial.print("Reset WiFi settings...");
//   wifiManager.resetSettings();  //****
//  Serial.println("Done.");
//  while(1) {
//    delay(1000);
//    Serial.println("loop..."); //i block the code
//  }
  //--------------------------------------------

 pinMode(SwConfig_pin, INPUT);

  pixels.begin();
  pixels.setBrightness(brightness);
  pixels.setPixelColor(LedConfig, off);
  pixels.show();

  //read configuration from FS json
  Serial.println("mounting FS...");

  if (SPIFFS.begin()) {
    Serial.println("mounted file system");
    if (SPIFFS.exists("/config.json")) {
      //file exists, reading and loading
      Serial.println("reading config file");
      fs::File configFile = SPIFFS.open("/config.json", "r");
      if (configFile) {
        Serial.println("opened config file");
        size_t size = configFile.size();
        // Allocate a buffer to store contents of the file.
        std::unique_ptr<char[]> buf(new char[size]);

        configFile.readBytes(buf.get(), size);
        DynamicJsonBuffer jsonBuffer;
        JsonObject& json = jsonBuffer.parseObject(buf.get());
        json.printTo(Serial);  //print the content of json object on serial.
        if (json.success()) {
          Serial.println("\nparsed json, from setup");

          strcpy(mqtt_server, json["mqtt_server"]); //save the block "mqtt_server" of json object in mqtt_server variable
          strcpy(mqtt_portStr, json["mqtt_port"]);
          mqtt_port = atoi(mqtt_portStr);
          strcpy(mqtt_username, json["mqtt_username"]);
          strcpy(mqtt_password, json["mqtt_password"]);
          strcpy(mqtt_topic, json["mqtt_topic"]);
          strcpy(address, json["address"]);
          

        } else {
          Serial.println("failed to load json config");
        }
      }
    } else {
      Serial.println("/config.json does not exist, creating");
      saveConfigJson(); // saving the hardcoded default values
    }
  } else {
    Serial.println("failed to mount FS");
  }
  //end read


  wifiManager.setSaveConfigCallback(saveConfigCallback);
    
  boolean startConfigPortal = false;
  
  if ( analogRead(SwConfig_pin) <= 500 ) {
    startConfigPortal = true;
  }

  WiFi.mode(WIFI_STA);
  if (WiFi.SSID()) {
    Serial.println("Using saved credentials");
    ETS_UART_INTR_DISABLE();
    wifi_station_disconnect();
    ETS_UART_INTR_ENABLE();
    WiFi.begin();
  } else {
    Serial.println("No saved credentials");
    startConfigPortal = true;
  }

  WiFi.waitForConnectResult();
  if (WiFi.status() != WL_CONNECTED) {
    Serial.print("Failed to connect Wifi");
    startConfigPortal = true;
  } else { 
  }

  if (startConfigPortal) {

    pixels.setPixelColor(LedConfig, blue);
    pixels.show();
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

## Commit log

2017-05-30 add sensor kit
2017-05-30 fix consumption table in sensor kit
2017-06-01 add eagle_file
    [arduino_Uno_shield_bora_lora.brd, arduino_Uno_shield_bora_lora.sch]
2017-06-01 add rivm eagle files
    [rot_pcb_esp_10.brd, rot_pcb_esp_10.sch]
2019-01-09 upload bom
    [BOM_sensors_kit.xlsx]
2019-01-23 add codes
    [BOM_sensors_kit.xlsx]
2019-01-23 fix wrong code for M0
    [MUV_M0_main.ino]
2019-01-24 sensors page
2019-02-13 update BOM
    [BOM_sensors_kit.xlsx]
2019-02-14 update sensors pcb
2019-02-19 Add Case folder to instructions
2019-02-19 Update MUV Air Quality Kit Bill of Materials.md
2019-02-19 Update Air Qual. Sensor_ Prototyping.md
2019-02-27 Updating pictures and BOM, plus one more laser cut file
    [Mounting Template.DXF]
2019-03-13 eagle for MUV
    [BOM_sensors_kit.xlsx, MUV_Interface_pcb.brd, MUV_Interface_pcb.sch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]
2019-03-20 update sds cable
2019-03-21 gerber files
2019-03-22 update 6way conn BOM
    [BOM_sensors_kit.xlsx]
2019-10-28 New 2.0-7 firmware version for the MUV Monitoring Station. Changes: - Wifi connection more stable, no timeout - Over the air firmware update - Real time clock sync with Network Time in UTC - Better d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

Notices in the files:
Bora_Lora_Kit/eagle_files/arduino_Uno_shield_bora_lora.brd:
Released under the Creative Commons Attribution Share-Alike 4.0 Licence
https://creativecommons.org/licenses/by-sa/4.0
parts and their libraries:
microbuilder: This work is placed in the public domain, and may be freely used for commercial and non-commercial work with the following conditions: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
